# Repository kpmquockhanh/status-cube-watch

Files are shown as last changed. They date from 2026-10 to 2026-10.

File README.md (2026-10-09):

# Claude Status Cube

A desk display that shows how much of your Claude rate limits you have left.
Runs on a **Waveshare ESP32-S3-Touch-LCD-1.69** (240x280 ST7789V2, CST816
touch).

One card with both rate-limit windows — the five-hour session and the
seven-day week — as two concentric rings: outer is the session, inner is the
week. The middle holds the one thing a ring cannot show (time until the session
resets), a legend line per window sits underneath with its exact percentage and
reset time, and your unread-mail count rides in the gap of the rings next to an
envelope.

```
┌─────────────────────┐
│ 78%    BLE      4s● │
│      ╭───────╮      │
│    ╭─╯ ╭───╮ ╰─╮    │
│   │  │ 4h 09m │ │   │
│   │  │TO RESET│ │   │
│    ╰─╮╰─ ✉ 12 ─╯╭╯  │
│      ╰──   ──╯      │
│  ■ 5H  14%   4h 09m │
│  ■ 7D  53%   1d 1h  │
│        ● ○          │
└─────────────────────┘
```

Two notches are cut into each ring at 60% and 85%, where it turns amber and
then red, so the arcs read against their own thresholds with no legend of
colours anywhere on screen.

## How it fits together

```
~/.claude/projects/*.jsonl  ─┐
                             ├─→  bridge (Node)  ──HTTP──→  ESP32-S3
Anthropic Usage & Cost API  ─┘     aggregates,              draws cards
                                   formats strings
```

The device never talks to Anthropic. A host-side bridge does the aggregation
and serves one small, pre-formatted JSON document over the LAN. That keeps
credentials off the microcontroller, keeps TLS and pagination off the
microcontroller, and — most usefully — means **you redesign the dashboard by
editing `bridge/cards.mjs` and reloading, with no reflash.**

## The gauges

The whole deck is two cards, because the only numbers that change what you do
next are the two rate-limit windows.

Both come from the same place Claude Code's own status line gets them:
`GET https://api.anthropic.com/api/oauth/usage`, which returns each window's
utilization as a whole percentage plus the instant it resets. That is the
figure the server is actually enforcing, so there is nothing to estimate and no
error bar. Green under 60%, amber to 85%, red above.

Authentication reuses the Claude Code login already on this machine -- the
macOS Keychain item `Claude Code-credentials`, falling back to
`~/.claude/.credentials.json` elsewhere. The token never leaves the host; the
device only ever receives the rendered percentage. `bridge/limits.mjs` caches
the response for 60s and fails soft: a failed read keeps the last good one for
up to 10 minutes, and after that (or with no login, no network, or an endpoint
that has moved) the ring keeps its empty track and a short reason (`no login`,
`timeout`, `HTTP 401`, `offline`...) goes under the countdown. A window whose
reset time has passed shows the empty track too, until the next read. An
unfilled ring reads as a legible nothing; a missing ring reads as a bug.

The spend and token breakdowns (`TODAY`, `THIS MONTH`, `TOKENS TODAY`,
`TOP MODEL`, `TOP PROJECT`) are still built in `bridge/cards.mjs` and are one
flag away -- set `"extraCards": true` in `bridge/config.json`, or run with
`CUBE_EXTRA_CARDS=1` (with the Mac helper: **Bridge settings…**), to swipe through them as well. They are off by default,
and they have no percentage of anything to fill a ring with, so they keep the
older big-number layout (see **Adding a card**).

### Unread mail card

Set `"gmail": {"user": "you@gmail.com", "appPassword": "xxxx xxxx xxxx xxxx"}`
in `bridge/config.json` (or `CUBE_GMAIL_USER` / `CUBE_GMAIL_PASSWORD`; with the Mac helper, the
Mail fields in **Bridge settings…**) and a
number appears next to an envelope in the gap of the rings. The bridge
reads it over IMAP (`STATUS INBOX (UNSEEN)`, at most once a minute), so the
device never sees a credential. Create the app password at
<https://myaccount.google.com/apppasswords> (needs 2-step verification; some
Workspace admins disable them). If a fetch fails the last count stays on screen
shown in red; with no count yet it reads `--`. Leave the settings empty and
there is no mail badge.

## Two data sources

| Source | What it reads | Who it works for |
|---|---|---|
| `local` *(default)* | Claude Code's own transcripts in `~/.claude/projects` | Anyone. Works on a personal account, no API key, no network call. |
| `admin` | The [Usage & Cost Admin API](https://platform.claude.com/docs/en/manage-claude/usage-cost-api) | Organizations only. Needs an Admin API key or an `org:admin` OAuth token. |

**Start with `local`** unless you're on an org plan. The Admin API is
unavailable for individual accounts, and `local` covers the machine you
actually work on.

A caveat worth knowing for `local`: the transcripts record tokens, not
billing. The bridge prices them with the published per-model rates, so the
dollar figures are an *equivalent API cost*. If you're on a Claude subscription
you aren't billed per token, and the number is a usage proxy, not an invoice.
Cards show a `~` in the top bar whenever the figure is an estimate. In `admin`
mode the cost report supplies real billed dollars and the `~` disappears.

## Quick start

### 1. Bridge

```bash
cd bridge
node server.mjs
```

No dependencies to install — it's plain Node ≥20 with zero packages. It prints
the URL to put in the firmware config:

```
claude-status-cube bridge  source=local  refresh=5000ms
  preview   http://localhost:8787/
  device    http://192.168.1.50:8787/api/status
```

Open the **preview** URL in a browser: it renders the same payload as a
240x280 device mock, so you can build and tune the whole dashboard before the
hardware arrives. Click the screen or use the arrow keys to change cards.

The server answers at once and fills in the data in the background (the card
says `starting` until the first read lands). `GET /health` is always 200 while
it runs; read `ok` in the body (`ok:false` with `error` / `limitsError` when
degraded). It listens on every interface, which the cube needs to poll over
WiFi; set `"host": "127.0.0.1"` in `config.json` (or `CUBE_HOST`) to keep it off
the LAN when the cube only uses Bluetooth. Pinned to one LAN address, it also
listens on `127.0.0.1` for the Mac helper. A bad value in `config.json` or the
environment is ignored with a warning, and an environment variable wins over
the file both ways (`CUBE_EXTRA_CARDS=0` turns off `"extraCards": true`).

To keep it running without a terminal open, install it as a LaunchAgent:

```bash
./agent.sh install      # starts now, and at every login
./agent.sh status       # loaded? answering? what's on the cards?
./agent.sh logs         # tail ~/Library/Logs/claude-status-cube/bridge.log
./agent.sh restart      # after editing cards.mjs
./agent.sh uninstall
```

An *agent* rather than a *daemon* on purpose: it runs as you, inside your GUI
login session, which is what lets it read the Claude Code token from your login
Keychain. A daemon starts before login, has no Keychain, and could not
authenticate. launchd restarts it if it crashes but leaves it alone if you stop
it deliberately (`SuccessfulExit=false`), and backs off 10s between respawns so
a bad config cannot spin the CPU.

The interpreter is pinned to an absolute path — launchd does not read your
shell profile — and the script prefers `/opt/homebrew/bin/node` over an nvm
build, whose path disappears when you clean up a Node version. Override with
`CUBE_NODE=/path/to/node ./agent.sh install`.

This keeps the cube alive as long as the Mac is awake. It still goes dark when
the Mac sleeps; for a display that is genuinely independent, run the bridge on
a Raspberry Pi or another always-on box instead.

For Admin API mode:

```bash
export ANTHROPIC_ADMIN_KEY=sk-ant-admin01-...
CUBE_SOURCE=admin node server.mjs
```

(or copy `config.example.json` to `config.json` and set it there).

### 2. Firmware

```bash
cd firmware
cp src/config.h.example src/config.h   # fill in SSID, password, bridge URL
pio run -t upload && pio device monitor
```

**Check `src/board_pins.h` before the first flash.** Waveshare ships several
1.69" variants and the revisions don't all share a pinout. Every
board-specific value is in that one file; cross-check it against the pin table
on your board's product wiki.

### 3. Pairing over Bluetooth (optional, recommended)

The Mac can push the data to the cube over Bluetooth, so the cube needs no WiFi at all. With WiFi
also configured, it is the automatic fallback when the Mac is out of range or asleep.

```sh
cd mac-helper
./install.sh install      # builds the app, asks for Bluetooth permission, installs the LaunchAgent
./install.sh status|logs|restart|uninstall
```

1. Flash the cube. With no WiFi configured and no Mac paired it shows **Waiting for a Mac** until a payload arrives (a touch dismisses it).
2. `./install.sh install`, click **Allow** on the macOS Bluetooth prompt. The script pauses
   (`read`) until you press Enter, so run it from a terminal, not a script without stdin.
3. The cube shows a 6-digit code; macOS asks for it. Type it. That is the whole pairing.
4. From then on it reconnects by itself. The app also runs the Node bridge for you
   (`node server.mjs` from a copy of `bridge/` inside the app, restarted if it dies); if something
   already serves the port, such as a running `bridge/agent.sh` job, the app adopts that bridge
   instead of starting its own. Node itself is not bundled: it needs Node 20+ installed.

**`install.sh` replaces `bridge/agent.sh`.** BLE users run `mac-helper/install.sh` instead of
`bridge/agent.sh install`. If the `agent.sh` job is already installed, run
`bridge/agent.sh uninstall` first; otherwise both LaunchAgents fight for the same port.
**The bridge ships inside the app.** `build-app.sh` copies the bridge's code (not `config.json`)
to `ClaudeCubeLink.app/Contents/Resources/bridge`, so the app runs the same way from the
LaunchAgent, Finder or `open`, wherever the repo is. A change to `bridge/` reaches the app only
after `./install.sh install` again.

**Bridge settings live in the app**, not in `bridge/config.json`: menu **Bridge settings…** edits
the usage source (local logs or Admin API, with its key or OAuth token), the spend/token cards,
the refresh interval, Gmail (address + app password) and whether the bridge serves the LAN (WiFi
cubes need it; off = `127.0.0.1` only). Apply saves and restarts the bridge, which gets them as the
bridge's environment variables (`CUBE_SOURCE`, `CUBE_EXTRA_CARDS`, `CUBE_REFRESH_MS`,
`CUBE_HOST`, `ANTHROPIC_ADMIN_*`, `CUBE_GMAIL_*`), which win over any `config.json`. The secrets are one Keychain item ("Claude Cube Link
bridge settings"); the rest is in the app's defaults (`bridgeSettings`). On its first launch after
`./install.sh install` the app imports `bridge/config.json` once, if it has no settings of its own
yet. Each reinstall re-signs the app, so macOS asks once to let the new build read that Keychain
item: choose **Always Allow**. A bridge the app adopted (say, a running `agent.sh` job) keeps its own
config; the window says so.
The app reads `CUBE_PORT` (default 8787), `CUBE_BRIDGE_DIR` and `CUBE_NODE` (path to `node`) from
the environment, and takes `--port N` on its command line; `install.sh` writes the port and node
into the LaunchAgent, which restarts the app only after a crash (`KeepAlive` with
`SuccessfulExit=false`), and records the node path in the app's defaults
(`defaults read com.claude-cube.link`) for launches without the LaunchAgent. Bridge order:
`CUBE_BRIDGE_DIR` (to run the repo's bridge while working on it), a `bridgeDir` default left by an
older install (`install.sh install` removes it), the bundled copy, then a `bridge/` next to the
working directory (`swift run`). Node: `CUBE_NODE`, the recorded path, the Homebrew and system paths.
The app talks to the bridge on `127.0.0.1`; a bridge whose `host` is pinned to a LAN address
listens on `127.0.0.1` as well, so any `host` works.

**Menu bar.** The item shows the 5-hour percentage. **Cube settings…** edits what the setup portal
can; changing the WiFi network with the password left blank asks first, because the cube then joins
it as an open network and forgets the stored password. **Forget cube** drops the stored cube and
scans again, for when you replace it (also remove the old "Claude Cube" in System Settings >
Bluetooth). **Quit** also stops the bridge the app started.
For verbose diagnostics (BLE state changes, frames and ACKs, bridge health checks and child exits,
HTTP timings, push decisions) set `CUBE_TRACE=1` or pass `--trace`; lines tagged `[trace:...]`
go to stderr, i.e. `./install.sh logs`.

While a Mac is paired and data arrives over Bluetooth (a payload every 5 s) the cube turns WiFi off
(with no paired Mac, or with `WIFI_ALWAYS_ON 1`, WiFi stays on even when Bluetooth is live). If
nothing arrives for 15 s and WiFi is configured it polls the bridge instead, and goes back to
Bluetooth after it has been steady for 30 s. `WIFI_ALWAYS_ON 1` in `config.h` keeps WiFi up
(needed for OTA while Bluetooth is working). With no WiFi configured and the Mac away, the last
cards stay on screen and the freshness counter keeps counting; the setup portal does not open by
itself unless the cube has no paired Mac.

**Pairing again.** Hold the screen at boot, join the cube's `claude-cube-XXXX` network, press
**Forget paired Mac**, then also remove "Claude Cube" in System Settings > Bluetooth. If the cube's
flash was erased the Mac keeps the old bond and the log says so (`./install.sh logs`).

The protocol is in `docs/ble-protocol.md`. The manual hardware checklist (nothing in it has been run
on a real cube yet) is `docs/ble-acceptance.md`.

### Changing WiFi without reflashing (setup portal)

The cube shows a setup screen when it cannot join the stored network within ~20 s and has no paired Mac (a cube with no WiFi and no Mac shows "Waiting for a Mac" instead, see Pairing over Bluetooth), or when you touch the screen while the boot screen says "HOLD SCREEN FOR SETUP" (the first 3 s after power-up) and keep holding for 5 s. Join the open `claude-cube-XXXX` network (scan the QR on the screen); the setup page opens by itself, or browse to `192.168.71.1`. Enter the WiFi name and password, the bridge URL and, optionally, an OTA password. A WiFi password must be 8 to 63 characters (or empty for an open network). A blank password keeps the saved one unless you change the network; a blank OTA password keeps the saved one too, and **Remove the OTA password** clears it. While nobody is on the setup network the cube keeps trying the stored network (a 10 s attempt every 30 s). Once it joins, the screen also shows the cube's address on that network, where the same page works from any computer on your LAN. If the setup screen came up because WiFi was down (not because you held the screen), the cube goes back to normal by itself the moment the stored network answers, so a router that was slow to come back after a power cut does not strand it. The setup network is open by design: while it is up (setup screen showing), anyone in radio range, and once it has joined, anyone on your LAN, can change the cube's settings, including the OTA password. (The page refuses requests that do not name the cube by address or that do not come from the form it served, so another web page cannot submit it for you.) Only reconfigure when you are at the cube, and set an OTA password. The page also has a **Forget paired Mac** button.

### Updating over WiFi (OTA)

After the first USB flash the cube is reachable as `claude-cube.local`. In `firmware/platformio.ini` uncomment `upload_protocol = espota`, `upload_port = claude-cube.local` and (if you set an OTA password) `upload_flags = --auth=...`, then run `pio run -t upload` as usual. The screen shows a progress bar. OTA runs under WiFi modem sleep (Bluetooth is always on, and the ESP32 does not allow WiFi power-save off alongside it), so an upload may occasionally time out: just retry. Without an OTA password anyone on your network can flash the cube; set one in the portal.

### Volume card

While a Mac is paired, the deck has a Volume card just before the Pomodoro: the output's name and its volume as a large number on the left, a slim bar on the right that fills from the bottom. **Drag** up or down anywhere on the card to raise or lower the volume by how far your finger moves; touching or tapping never changes it. **Tap the number** to mute or unmute (any volume change also unmutes). The row of buttons at the bottom is **previous**, **play/pause** and **next**: they act on whichever app is playing (as Control Center's buttons do; no permission needed), and the middle button shows ▶ while paused and ❙❙ while playing. Left and right swipes still change card; swipe down does not open the display panel on this card. Changes made on the Mac (keyboard, menu bar, switching to AirPods) show on the cube within about a third of a second. An output whose volume the Mac cannot set (HDMI, some USB devices) shows `FIXED`, and only mute works there; with the Mac's app not connected the card shows `NO MAC`. It needs the Mac app and firmware from the same release: an older app leaves the card on `NO MAC`, and an older cube has no Volume card. After a firmware update the cube tells the paired Mac its services changed (Service Changed, sent once per new firmware revision), and the Mac app rediscovers them on the next connection. If the card still stays on `NO MAC` while the top bar says `BLE`, remove the cube in System Settings > Bluetooth and pair again (macOS kept the old services).

### Unlocking the Mac from the cube

Turn on **Unlock Mac with cube…** in the menu. It asks for your login password once, checks it, and keeps it in the Mac's Keychain; macOS also asks you to allow Claude Cube Link under Privacy & Security > Accessibility, which it needs to type. From then on, when the Mac locks, the cube shows **Tap to unlock**. Tap it, and the Mac wakes the display and types the password into the lock screen. The cube only asks; the password never leaves the Mac. A swipe puts the prompt away to show the cards, and it comes back after 30 s without a touch. A running Pomodoro shows its clock under the prompt.

It works on a locked session only. After a restart, the FileVault login comes before the app runs, so type the password there as usual. Anyone holding your paired cube can unlock the Mac while it is in Bluetooth range, so leave this off if the cube sits where others can reach it. `build-app.sh` signs with your Apple Development certificate when the keychain has one (a free Apple ID in Xcode > Settings > Accounts creates it), so macOS keeps the Accessibility permission and Keychain access across rebuilds. Without one the app is signed ad-hoc, and macOS forgets both after every rebuild; until you allow them again, the log says why a tap did nothing. Turning the item off deletes the stored password.

### Pomodoro card

The last card in the deck is a Pomodoro timer that runs on the cube itself (so it works with the bridge down). **Double-tap** the screen to start, pause or resume (it acts a third of a second after the second tap, once it is clear no third is coming); **triple-tap** to reset. It runs 25 min focus, 5 min break, and a 15 min break after four focus sessions, each phase started by you. When a phase ends the cube jumps to this card and pulses the ring and backlight for about two seconds and plays a short tune (rising for a break, ending high for back to work); the next phase waits for your double tap. To change the lengths without reflashing, **swipe up** on the Pomodoro card while the timer is idle. A settings screen opens with a `-` and `+` for FOCUS (steps of 5 min), SHORT BREAK (1 min), LONG BREAK (5 min) and SESSIONS (1). RESET returns to the defaults; DONE (or a swipe down) saves them, and they survive power cycles. A running or paused phase is never resized: new lengths apply from the next one you start. Lengths changed from the Mac (**Cube settings…**) work the same way, and arrive even mid-set. The defaults are `POMO_FOCUS_MIN`, `POMO_BREAK_MIN`, `POMO_LONG_MIN` and `POMO_SESSIONS` in `config.h`.

### Sound

The cube's buzzer plays a short tune when a Pomodoro phase ends. Its level is OFF, LOW, MED (the default) or HIGH, and you can set it in three places:
- **On the cube:** swipe down on any card and use the SOUND row. A tap on its label switches it off or back on, and each change plays a beep at the new level.
- **From the Mac:** **Cube settings…** > Sound.
- **In the setup portal:** Sound, from 0 to 3.

The default is `BUZZER_LEVEL` in `config.h`. SOUND took the place of WiFi refresh in the on-device panel. WiFi refresh is still in the portal and on the Mac.

## Layout

```
bridge/
  server.mjs          HTTP server + refresh loop
  cards.mjs           events → the card deck (edit this to redesign)
  pricing.mjs         per-model rates and cache multipliers
  limits.mjs          rate-limit windows from the OAuth usage endpoint
  agent.sh            install/remove the macOS LaunchAgent
  preview.html        browser mock of the device
  sources/local.mjs   incremental ~/.claude transcript reader
  sources/admin.mjs   Usage & Cost Admin API client
mac-helper/           Swift app: runs the bridge, pushes /api/status to the cube over BLE
  install.sh          install/remove the LaunchAgent
firmware/
  src/board_pins.h    all board-specific pins — check this first
  src/config.h        your WiFi + bridge URL (gitignored)
  src/display.h       LovyanGFX panel definition
  src/touch.cpp       CST816 driver
  src/ui.cpp          card rendering
  src/payload.cpp     bridge JSON → Payload (shared with the simulator)
  src/net.cpp         WiFi transport
  src/net_ble.cpp     BLE transport (NimBLE GATT server)
  src/ble_frame.h     chunk reassembly for the BLE wire format
  src/transport_policy.h  when WiFi runs versus BLE (pure, host-tested)
  src/main.cpp        poll loop and swipe handling
  sim/                desktop simulator — runs the UI without hardware
  sim/shot.cpp        headless frame grab: one PNG per card
```

## Testing without the board

Two ways, in increasing fidelity.

**Browser mock.** Start the bridge and open its address. `preview.html` renders
the same 240×280 layout and polls the same endpoint the device will. Good for
iterating on `cards.mjs` — edit, reload, see it. It is a JavaScript
reimplementation of the layout, so it tells you whether the *data* reads well,
not whether the firmware draws it correctly.

**Battery indicator.** Every card's top bar shows the battery level, measured on the board's ADC and drawn on-device (it is not part of the bridge payload). With no battery connected the cube is running from USB and shows a full 100%. In the simulator, `CUBE_BATTERY=30 make run` (or `none` for the no-battery case) picks the level.

**Desktop simulator.** `firmware/sim/` compiles the actual firmware sources —
`main.cpp`, `ui.cpp`, `payload.cpp` — against LovyanGFX's SDL backend and opens
a window instead of driving the ST7789. Only the two layers that touch hardware
are swapped: `net_sim.cpp` does a socket HTTP GET in place of WiFi, and
`touch_sim.cpp` feeds mouse events in place of the CST816 over I²C. The gesture
thresholds, the font-fitting ladder, the sprite compositing and the JSON parsing
are the real ones.

```sh
brew install sdl2
cd firmware && pio run          # once, to fetch LovyanGFX + ArduinoJson
cd sim && make run
```

Drag across the window to swipe, click to tap, `SCALE=3 make run` for a bigger
window, and `CUBE_BRIDGE_URL=http://localhost:8787/api/status make run` to point
it somewhere other than the `BRIDGE_URL` in `config.h`.

**Bluetooth in the simulator.** There is no BLE radio on the desktop, so `CUBE_BLE` picks what the
cube believes: `none` (default, WiFi-only as before), `live` (bonded, a payload arrives every 5 s),
`stale` (bonded, nothing arrives, so WiFi takes over after 15 s), `pair` (the passkey screen).
`./build/cube-shot build/shot @ble-pair` and `@ble-wait` render the passkey and "Waiting for a Mac"
screens.

**Frame grabs.** `make shot` renders every card of the live payload through the
same `ui.cpp` and writes one PNG per card to `build/`, with no window and no
screen-recording permission involved. It waits for the entry animation to
settle first, so what you get is the resting layout. Point it at a saved
payload to shoot states you cannot reach on demand -- the red ring, the
empty track, a card that does not exist yet:

```sh
cd firmware/sim
make shot                                  # the live bridge
./build/cube-shot build/state states.json  # build/state-0.png, -1.png, ...
```

What it still cannot tell you: whether the pins in `board_pins.h` match your
revision, how the ST7789 renders these colours, and how the panel behaves at its
real refresh rate.

## Adding a card

Push one more object onto the `cards` array in `bridge/cards.mjs`. Without a
`g`, you get the big-number layout:

```js
{ t: 'WEB SEARCHES', v: String(dayT.webSearch), s1: 'today', s2: '', c: 'blue' }
```

With a `g` — a whole percentage — you get a ring instead, and the other fields
change jobs: `g` fills the arc, `v` goes in the middle of it, `s1` captions
`v`, and `s2` labels the percentage in the gap at the bottom:

```js
{ t: 'CONTEXT', v: '38k', s1: 'tokens left', s2: 'of 200k', c: 'green', g: 81 }
```

`g: -1` means *no reading* and draws the empty track. The threshold colours
are yours to pick through `c`; the notches at 60% and 85% are fixed, so a ring
whose meaning does not break there wants a different accent than green/amber/
red so it doesn't imply one.

Reload the page. The firmware sizes the deck from the payload and the page
dots follow — nothing to change on the device. Accent names are `accent`,
`blue`, `green`, `amber`, `violet`, `red`.

Keep `v` short. A text card shrinks its own value to fit 220px. Ring cards
instead pick one size for the whole deck — the largest that fits the longest
value inside the ring's 130px middle — so the countdown does not change size
as you swipe. One long value therefore shrinks every ring, which is why
`until()` drops minutes once the horizon passes ten hours.

## Notes on the implementation

- **Incremental reads.** The local source reads every `.jsonl` under
  `~/.claude/projects` (subagent transcripts included), keeps a byte offset per
  file and only parses appended bytes, moving the offset only past complete
  lines, so a half-written line is read again next time. A file whose size and
  modified time have not changed is skipped, so a 5-second refresh over a busy
  `~/.claude` stays cheap. Events are de-duplicated on `requestId`, because
  the same request is often written to the log more than once.
- **Pricing.** `bridge/pricing.mjs` matches model ids on the longest prefix,
  prices cache reads and writes per model, and prices fast mode and US-only
  inference (`inference_geo: "us"`, 1.1x) when the usage record says so.
- **Admin polling.** The Usage & Cost API documents sustained polling at once
  per minute; the bridge enforces that floor in `admin` mode regardless of
  what you configure.
- **Cost vs. usage endpoints.** In `admin` mode the usage report gives hourly
  granularity per model and the cost report gives authoritative dollars in
  daily buckets (UTC days, shown under the local date). Both only matter with
  `extraCards` on; the default gauges come from the OAuth usage endpoint instead.
- **No LVGL.** Two dials don't need a widget toolkit. LovyanGFX with one
  full-screen sprite is simpler to build, has no `lv_conf.h` to maintain, and
  leaves most of RAM free. LVGL 9 is the upgrade path if the UI grows.
- **Motion.** A ring sweeps up from zero the first time you see a card after
  boot (700ms), retargets from wherever it currently is when the number moves
  under it (260ms), and crossfades through a threshold colour over 400ms.
  Everything eases out. It is deliberately per-card and once-per-boot: an
  animation replayed on every swipe is one you would see dozens of times a
  day, and there is no pulse or blink on the red state for the same reason.
  `uiAnimating()` is what tells `main.cpp` to keep drawing frames; the rest of
  the time the loop still redraws once a second for the freshness counter.

## Troubleshooting

| Symptom | Cause |
|---|---|
| White or blank screen | Pins in `board_pins.h` don't match your revision |
| Image shifted vertically | Change `LCD_OFFSET_Y` (20 ↔ 0) |
| Colours inverted | Flip `cfg.invert` in `src/display.h` |
| `[touch] not responding` | `PIN_I2C_SDA` / `PIN_I2C_SCL` / `PIN_TP_RST` wrong |
| Top bar shows `OFF` | Bridge not reachable — check it's bound to the LAN address it printed, and that the host firewall allows the port |
| Costs look too low | An unrecognised model falls back to Sonnet-tier rates; add it to `bridge/pricing.mjs` |
| Cube never pairs | Check `./install.sh logs`; the app needs the Bluetooth permission (System Settings > Privacy & Security > Bluetooth) |
| `pio run` stalls at `Downloading 0%` | PlatformIO's CDN, not your network. See below. |

### When the PlatformIO registry is down

`dl.registry.platformio.org` occasionally serves at a crawl, which strands
`pio run` on `Downloading 0%` with an empty `~/.platformio/packages/`. Confirm
it's the CDN and not you by timing the same toolchain from GitHub:

```sh
curl -o /dev/null -w '%{speed_download} B/s\n' -r 0-8000000 \
  https://github.com/espressif/crosstool-NG/releases/download/esp-2021r2-patch5/xtensa-esp32s3-elf-gcc8_4_0-esp-2021r2-patch5-macos-arm64.tar.gz
```

If GitHub is fast, install the packages by hand into `~/.platformio/packages/`
from their upstream releases — the two xtensa toolchains and the RISC-V one
from [crosstool-NG](https://github.com/espressif/crosstool-NG/releases/tag/esp-2021r2-patch5),
the framework from [arduino-esp32 2.0.17](https://github.com/espressif/arduino-esp32/releases/tag/2.0.17),
and [esptool 4.11.0](https://github.com/espressif/esptool/releases/tag/v4.11.0).
Each directory needs a `package.json` (`name` and `version` matching what
`~/.platformio/platforms/espressif32/platform.json` asks for) and a `.piopm`
naming the owner — the registry adds both during packaging, so the raw
archives lack them. esptool from source also needs `pip install intelhex`
in the PlatformIO Python environment.

## Ideas from here

The board also has a QMI8658 IMU, a PCF85063 RTC, a buzzer, and battery
charging, none of which this scaffold uses yet:

- Wrist-raise or tilt to wake, via the IMU
- Buzzer when the daily spend crosses a threshold
- Deep sleep between polls, with the RTC as the wake source, for battery use
- A "burn rate" card: tokens per minute over the last 10 minutes

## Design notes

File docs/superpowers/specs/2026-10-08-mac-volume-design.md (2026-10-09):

# Mac volume card

## Goal

A card on the cube that shows and changes the Mac's output volume: a full-width vertical slider in
the style of the Android "flex" volume control. Drag it, tap to jump, tap the speaker to mute. The
cube follows the Mac too, so a change made with the keyboard shows up on the cube.

## Decisions (agreed)

- A **deck card**, not a panel. Deck order: payload cards, **Volume**, Pomodoro (still last). The
  card exists while a Mac is bonded (`bleBonded()`); with no bond the deck is unchanged.
- Controls: **volume and mute** only. No media keys.
- Transport: **BLE only**, approach A: a new Control message (cube -> Mac) carries the request, and a
  new **Volume** characteristic (Mac -> cube) carries the Mac's state, including the **output device
  name**. The payload contract, the bridge and `preview.html` are untouched.
- Look: one rounded pill across the card, filling from the bottom (reference: Android flex volume
  UI, made full width).
- On this card a vertical drag is the volume, so **swipe down does not open the display panel
  here**. It still opens from every other card.
- No new menu item on the Mac.

## The card

```
  BLE   78%            4s .
 +------------------------+
 |  MACBOOK PRO SPEAKERS  |   output name, small caps
 |          56            |   level
 |########################|   fill edge = level (flat)
 |########################|
 |#########  spk  ########|   speaker glyph
 +------------------------+
           . . o .
```

Layout (240x280 panel; exact numbers are tuned against `make shot`):

- The top bar is the shared one (battery, link marker, age), and the page dots sit below as usual.
- The pill runs x 14..226 and y 42..252, with corners of about 40 px. Its track is dark (the ring
  track colour family).
- The fill is the same anti-aliased rounded rect, clipped to `y >= levelY`, so the corners stay
  smooth at any level and the top edge is flat. The fill colour is a soft lavender (a new accent
  constant).
- The output name is drawn in small caps near the top of the pill, and the level number large below
  it. Both are drawn twice through the fill clip: ink above the fill edge, dark where the fill
  covers them, so the text stays readable at any level.
- The speaker glyph is centred near the bottom of the pill with 0..3 waves by level (0, 1..33,
  34..66, 67..100). When muted it is slashed and drawn with no waves.
- No glow or texture: the panel is RGB565 and the frame budget is better spent elsewhere.

States:

| State | Fill | Number | Caption / name | Touch |
|---|---|---|---|---|
| Live | lavender, at level | level | output name | drag, tap-jump, speaker = mute |
| Muted | crossfades to grey (`POMO_MUTED`), keeps its height | level | output name, glyph slashed, the word `MUTED` under the number | as live; any level change also unmutes |
| Fixed volume (`canSet` false) | full, dimmed grey | `--` | output name, `FIXED` under the number | speaker = mute if `canMute`, else nothing |
| No Mac (link down, or no Volume write yet) | empty track | `--` | `MAC VOLUME`, `NO MAC` under the number | nothing |

The state never relies on colour alone: `MUTED`, `FIXED` and `NO MAC` are spelled out.

Motion:

- A change from the Mac, or a tap-jump, eases the fill to the new level with the existing retarget
  timing (`RETARGET_MS`, 260 ms, ease-out).
- While a finger drags, the fill tracks the finger directly, with no easing.
- Mute and unmute crossfade the fill colour over `COLOR_MS` (400 ms).
- The first view of the card sweeps the fill in from empty, as rings do (`uiReplay`).

Interaction:

- Drag up or down anywhere on the pill: the level is the finger's height mapped linearly over the
  pill's inner height, clamped to 0..100.
- Tap on the pill, outside the speaker zone: the level jumps to that height.
- Tap in the speaker zone (about 60x50 px around the glyph): toggle mute.
- Swipe left or right: change card. Axis lock decides between the two: once the finger has moved
  10 px from where it landed, a mostly vertical move becomes a drag and a mostly horizontal one
  stays a swipe. A drag never turns into a swipe and vice versa.
- Swipe up and swipe down mean nothing on this card.
- Taps here are plain taps (multi-tap is off), delivered at once.
- Touch is ignored in the No Mac state. In the Fixed state only the speaker zone acts.

Other behaviour:

- Local-only, like the Pomodoro card: not in the payload contract, not counted against
  `MAX_CARDS`, not in `preview.html`.
- Volume writes from the Mac are not readings. They do not change `readingsKey()`, so they do not
  keep the screen awake or wake it.
- Auto-advance includes the card like any other. A touch on it restarts the auto-advance timer, as
  a swipe does.
- When the deck changes size, a viewer on the Volume card stays on it (`deck_util.h`), as a viewer
  on the Pomodoro card does.

## Protocol

Additive; protocol version stays 1. `fw_rev` goes 4 -> 5.

### Control (cube -> Mac)

| Bytes | Meaning |
|---|---|
| `05 <level> <muted>` | set the Mac's output to `<level>` (0..100) and mute `<muted>` (0/1). |

- The request is an absolute target, so a lost or repeated message cannot drift the volume.
- Fire and forget: no ack, and it is dropped when no Mac is subscribed.
- A Mac that does not know `05` ignores it.

### Volume characteristic (Mac -> cube)

UUID `6e6d3c10-5d1a-4c1e-9f0b-7c4a2b8e1a06`, write (encrypted + authenticated), at most 26 bytes:

```
[ver=1][level][flags][name...]
```

- `level`: 0..100, or `FF` when there is no output device.
- `flags`: bit0 muted, bit1 volume settable, bit2 mute settable. Other bits are 0, and the cube
  ignores them.
- `name`: the output device name, printable ASCII (0x20..0x7E), 0..23 bytes, no terminator.

Validation:

- The cube drops the whole write when the value is shorter than 3 bytes, `ver != 1`, `level` is
  over 100 and not `FF`, or the name holds a byte outside 0x20..0x7E.
- A dropped write keeps the previous state.

When the Mac writes:

- once after it has subscribed to Control;
- then on every coalesced CoreAudio change (volume, mute, name, default output device).

Lifetime:

- The cube forgets the state when the link drops, and the card falls back to No Mac.
- A cube without the characteristic (fw_rev < 5) gets no writes, and the Mac logs it once.

Both encodings get golden lines in `firmware/sim/fixtures/ble-frames.txt`, read by `make test` and
`swift test`. Documented in `docs/ble-protocol.md`.

Latency note: the idle connection parameters let the cube skip up to 6 connection events, so a
Mac -> cube write can take about 300 ms to land. Drags go cube -> Mac and the fill follows the
finger locally, so this only delays how fast a *keyboard* change shows on the cube.

## Firmware

New pure units, each with a host test in `sim/tests/` (no Arduino, caller passes `now`, gnu++11
safe):

- **`volume_frame.h`**
  - `MacVolume { bool known; uint8_t level; bool muted, canSet, canMute; char name[24]; }`.
  - `bool volumeParse(const uint8_t *d, size_t n, MacVolume &out)` applies the validation above.
  - `void volumeRequestEncode(uint8_t level, bool muted, uint8_t out[3])`.
- **`volume_slider.h`**
  - The geometry: pill rect, inner travel, speaker zone. `ui.cpp` draws from the same constants,
    so drawing and hit-testing cannot drift (the `pomo_editor` pattern).
  - `uint8_t volumeLevelAt(int16_t y)`.
  - A `VolumeSlider` model:
    - holds the shown level and muted flag;
    - `grab(now)` / `drag(y, now)` / `release(now)` / `tap(x, y, now)`;
    - `fromMac(const MacVolume&, now)`, which is ignored while held and for `VOLUME_HOLD_MS`
      (600 ms) after release, so echoes of older levels cannot jerk the fill;
    - `bool takeSend(now, level&, muted&)`, which yields a request at most every `VOLUME_SEND_MS`
      (50 ms) while dragging, always the final value on release, and once per tap.

Changed units:

- **`gesture.h/.cpp`**: a `dragMode` flag next to `multiTap`, set by `main.cpp` only on the Volume
  card.
  - New gestures `DragStart`, `Drag`, `DragEnd`. `Drag` comes back while the finger moves, with
    `lastY()`.
  - Once travel reaches `DRAG_LOCK_PX` (10), a mostly vertical move locks to a drag and a mostly
    horizontal one is classified on lift as today.
  - Taps are unchanged. With `dragMode` off, behaviour is identical to today (the existing tests
    must still pass).
- **`ble.h`, `net_ble.cpp`**
  - The Volume characteristic; its callback copies the value out under the same pattern as
    Settings.
  - `bool bleTakeVolume(MacVolume &out)` returns true when the state changed, including the change
    to "unknown" when the link drops.
  - `void bleSendVolume(uint8_t level, bool muted)` notifies Control `05`.
  - `BLE_FW_REV` becomes 5.
  - Stand-ins in `sim/ble_sim.cpp` (driven by `CUBE_VOLUME=56|muted|fixed|none`, default `none`)
    and `sim/bench.cpp`.
- **`ui.h/.cpp`**
  - `uiVolumeIndex(p)`. `uiDeckSize` / `uiPomodoroIndex` account for the card when it is present,
    and `uiRender` takes whether it is present.
  - `drawVolumeCard(...)` draws the pill, the clipped fill, the two-tone text and the glyph.
  - A `GaugeAnim`-style animation holds the fill level and colour.
  - `uiReplay` covers the card.
- **`deck_util.h`**: `deckKeepIndex` keeps a viewer on either local card.
- **`main.cpp`**
  - calls `bleTakeVolume` every pass and feeds the slider;
  - on the Volume card passes `dragMode`, routes `DragStart` / `Drag` / `DragEnd` / `Tap` to the
    slider and skips `SwipeDown`;
  - calls `bleSendVolume` from `takeSend`;
  - sets `dirty` on any slider change;
  - treats a drag as animating, so the CPU stays at 240 MHz and frames are paced to `FRAME_MS`.
- **`sim/shot.cpp`**: `@vol-56`, `@vol-muted`, `@vol-fixed`, `@vol-none`, `@vol-full`,
  `@vol-zero`.
- **`sim/bench.cpp`**: a `volume` scenario (one drag across the pill, then a tap on the speaker).

## Mac helper

- **`CubeLinkCore/Volume.swift`** (pure, tested)
  - `MacVolume`.
  - `encodeVolume(_ v: MacVolume) -> Data`. The name is folded to ASCII: diacritics stripped,
    other non-ASCII dropped, cut to 23 bytes.
  - `ControlMessage.volumeRequest(level:muted:)` in `Protocol.swift`. A frame under 3 bytes, a
    level over 100 or a muted byte over 1 parses to nil.
  - `CubeProtocol.volumeUUID`.
- **`ClaudeCubeLink/SystemVolume.swift`** (CoreAudio; no permission prompt needed)
  - Reads the default output device, `kAudioHardwareServiceDeviceProperty_VirtualMainVolume`,
    `kAudioDevicePropertyMute`, `kAudioObjectPropertyName`, and whether each is settable. With no
    output device, `level` is `FF`.
  - Listens with `AudioObjectAddPropertyListenerBlock` to the system default-output change and to
    volume, mute and name on the current device. The device listeners move when the default
    output changes.
  - Coalesces callbacks into one `onChange(MacVolume)` about 30 ms after the last.
  - `apply(level:muted:)` sets mute, then the volume scalar (level / 100). A request with
    `muted = 0` unmutes. A part the device cannot set is skipped.
- **`CubeLink`**
  - Discovers the Volume characteristic optionally (like Settings).
  - `writeVolume(Data)` writes it with response.
  - The Control handler calls `onVolumeRequest(level, muted)`.
  - Once subscribed, the link asks for the current state so it is written at once.
- **Wiring (`main.swift` / `StatusMenu.swift`)**: `SystemVolume.onChange` -> `CubeLink.writeVolume`
  (only while ready), and `CubeLink.onVolumeRequest` -> `SystemVolume.apply`. Changes are logged
  through `Trace`.

## Testing

- `make test`:
  - `volume_frame_test`: parse and encode, every rejection case, the fixture lines.
  - `volume_slider_test`: `levelAt` at the travel ends and past them, tap-jump, the speaker zone,
    the hold window ignoring and then accepting Mac state, the send throttle and the final send,
    unmute-on-change.
  - `gesture_test`: axis lock both ways, the drag event sequence, taps in drag mode, `dragMode`
    off unchanged.
  - `deck_util` cases for two local cards.
- `swift test`: fixture parity for both encodings, `05` parsing including malformed frames, name
  folding and truncation.
- `make shot` / `cube-shot @vol-*`: each state looked at before the UI is called done.
- `make bench`: the `volume` scenario stays within frame pacing, and the screen still sleeps at
  the end of `linked` / `sleep`.
- `pio run`: the board build (gnu++11) after the pure headers are added.
- Hardware: a "Volume card" section in `docs/ble-acceptance.md` covering drag, tap-jump, mute,
  keyboard echo, switching output to AirPods, an HDMI or fixed output, link drop, and an older Mac
  app.

## Out of scope

- Media keys (play/pause, next).
- Per-app volume.
- Input (microphone) volume.
- A Mac-side toggle for the feature.
- WiFi delivery.
- Haptic or sound feedback on the cube.
- Hold-to-repeat.
- A volume HUD on the Mac.

## Docs to update on implementation

- `CLAUDE.md`: the deck description and the Transports paragraph.
- `firmware/CLAUDE.md`: the pure-header list.
- `docs/ble-protocol.md`: Control `05` and the Volume characteristic.
- `docs/ble-acceptance.md`: the new section.
- `mac-helper/CLAUDE.md`.
- `README.md`: where it describes the cards and the Mac app.

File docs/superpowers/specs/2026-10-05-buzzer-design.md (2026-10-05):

# Buzzer

## Goal
Give the cube a voice. Make the on-board passive buzzer play a short tune when a Pomodoro phase ends, with an on/off switch and three volume levels you can set on the cube, from the Mac and in the portal. Also hold the buzzer pin low from the first instant of boot. Today the firmware never touches it, and Waveshare's FAQ for this board warns that an undriven buzzer pin keeps drawing current through the 3.3 V LDO and heats it.

This is sub-project A of six (A buzzer, B Claude session status, C answer from the cube, D IMU gestures, E next meeting, F now playing). B will use the `Attention` sound defined here when Claude Code is waiting for you, so that sound is in the tables now even though nothing in A triggers it.

## Non-goals
- Sounds triggered by the bridge: no payload field and no contract change. B adds the payload event that plays `Attention`.
- Usage-threshold beeps and a limit-reset chime. These were offered and not wanted.
- Quiet hours. The cube has no local time of day yet (the RTC is unused), so there is nothing to compare against.
- A touch-click sound, or sound for swipes and taps.
- Mirroring in `preview.html` or the Mac's menu bar. Sound is local, like the battery and the Pomodoro card.
- Real audio in the simulator. It logs which sound would play.

## Hardware facts
- The buzzer is **passive**: a PWM square wave sets its pitch, and the duty cycle sets its loudness (non-linearly; 50% is loudest).
- Current boards wire it to **GPIO42** (`docs/ESP32-S3-Touch-LCD-1.69.md`). Waveshare's FAQ says an older revision used GPIO33.
- The Arduino core is 2.0.17 (`framework-arduinoespressif32` 4.20017.0), so the LEDC API is `ledcSetup` / `ledcAttachPin` / `ledcWrite` / `ledcChangeFrequency`. On the S3, channel *n* runs on timer `(n / 2) % 4`.
- The backlight is LovyanGFX `Light_PWM` on LEDC **channel 7** (timer 3) at 12 kHz (`display.h`). The buzzer must use a channel on another timer, so that changing the buzzer's frequency can never retime the backlight. Channel 6 would share timer 3, so it is ruled out.
- Arduino's `tone()` is not used. It claims LEDC channel 0 and spawns its own FreeRTOS task.

## Design

### Pin: `board_pins.h`
`#define PIN_BUZZER 42`, with a comment that older board revisions use 33.

### Sequencer: `firmware/src/melody.h` (pure, header-only, host-tested)
- `struct Note { uint16_t hz; uint16_t ms; }`, where `hz == 0` is a rest.
- `enum class Sound : uint8_t { FocusDone, BreakDone, Attention, Preview }` and `const Note *melodyFor(Sound, uint8_t &len)`. Each melody is a `constexpr` table and lasts under 0.5 s.

| Sound | Played when | Shape (starting pitches; tuned by ear on the board) |
|---|---|---|
| `FocusDone` | a focus phase ends: break time | three rising notes, ~2.1 / 2.6 / 3.1 kHz, ~110 ms each |
| `BreakDone` | a short or long break ends: back to work | three notes ending high and held longer, distinct from `FocusDone` |
| `Attention` | (B) Claude Code is waiting for you | two ~70 ms beeps near the buzzer's loudest pitch (~2.7 kHz), 70 ms apart |
| `Preview` | the SOUND level changes in the on-device panel | one ~90 ms beep |

- `class MelodyPlayer`:
  - `play(Sound)` replaces whatever is playing. Timing starts at the next `update()`, so a play requested after this pass read `now` (the panel's preview, from the touch handler) keeps its first note.
  - `stop()`.
  - `uint16_t update(now)` returns the pitch to output now, or 0 for silence (a rest, or finished). A late call skips the notes it missed, so a tune keeps its length.
  - `bool playing() const`.
- Elapsed time uses unsigned subtraction, so a `millis()` wrap mid-melody is harmless. The caller passes `now`, as with every pure header.
- C++11-safe for the board build: every `constexpr` function is a single `return`.

### Driver: `firmware/src/buzzer.{h,cpp}` (hardware layer)
API:
```cpp
bool buzzerBegin();                 // first thing in setup(); false = LEDC setup failed
void buzzerSetLevel(uint8_t level); // 0 = off, 1..3 = LOW / MED / HIGH
void buzzerPlay(Sound s);           // no-op at level 0
void buzzerUpdate(uint32_t now);    // every loop pass
```
- `buzzerBegin()`:
  1. `pinMode(PIN_BUZZER, OUTPUT); digitalWrite(PIN_BUZZER, LOW)` before anything else in `setup()`, so the pin no longer floats from boot.
  2. Then `ledcSetup(BUZZ_CH = 0, 2000, 10)` (10-bit duty), `ledcAttachPin`, and `ledcWrite(BUZZ_CH, 0)`. Channel 0 runs on timer 0, away from the backlight's timer 3.
- Silence is always duty 0, which keeps the output low.
- `buzzerUpdate` asks the `MelodyPlayer` for the current pitch and only touches LEDC when the pitch changes: `ledcChangeFrequency` followed by `ledcWrite(duty)`, or duty 0 for a rest or the end.
- Notes are timed by the main loop pass (15 ms, or `FRAME_MS` = 16 ms while animating), so durations are accurate to about one pass. Every note is ≥ 60 ms, so that is inaudible. Screen-off passes are 50 ms, but nothing in A plays with the screen off: a running Pomodoro keeps it on, and the panel is on screen.
- Volume is a duty per level: `{0, LOW ≈ 2%, MED ≈ 10%, HIGH = 50%}` of the 10-bit range. These are constants in `buzzer.cpp`, tuned by ear on the board, because a passive transducer's loudness is not linear in duty.
- A level change applies on the next loop pass. Level 0 also stops the tune, so it is silent at once.
- `ledcSetup` returning 0 makes `buzzerBegin()` return false. `setup()` logs `[buzz] ledc setup failed` once Serial is up, and the cube stays silent. The pin is still held LOW by step 1.
- Serial log: `[buzz] <sound> @<LOW|MED|HIGH>` on each play.

Simulator and bench:
- `firmware/sim/buzzer_sim.cpp` implements the same header. It only prints the `[buzz]` line: no player and no audio.
- `sim/bench.cpp` includes `../src/buzzer.h` and defines no-op stand-ins, as it already does for the battery and the IMU.
- `buzzer_sim.cpp` goes in `SRCS`. `melody.h` is header-only, so `melody_test` only needs adding to `TESTS`.

### Setting: `DeviceSettings.sound`
- New field `uint8_t sound; // 0 = off, 1..3 = LOW / MED / HIGH`. It is clamped to 0..3 in `deviceClamp` and compared in `operator==`.
- Default: `BUZZER_LEVEL` from `config.h` (MED = 2), with an `#ifndef` fallback in `device_defaults.h` so an older `config.h` still builds. `config.h.example` documents it.
- NVS key `sd` (`settings.cpp`), falling back to the default when never stored. `sim/settings_sim.cpp` has no NVS and copies `DEVICE_DEFAULTS` whole, so it needs no change.
- Every brace-initialised `DeviceSettings{...}` gains the fifth value: `DEVICE_DEFAULTS`, `portal.cpp`'s save (`DeviceSettings{bl, sl, rt, pi}` today), and the tests. A missed one compiles fine and silently stores sound = 0.
- `buzzerSetLevel` is called:
  - in `setup()`, with `deviceSettings().sound`;
  - in `closeDeviceEditor()`, next to the brightness restore;
  - in `handleBleSettings()`, next to its `setBrightness`.

  The portal saves and reboots, so `setup()` covers it.

Everywhere it can be edited:
- **On-device panel** (`dev_editor.cpp`): row 3 becomes **SOUND** in place of REFRESH. It is a switch row, like SLEEP and ADVANCE.
  - Presets are `{1, 2, 3}`, shown as `LOW` / `MED` / `HIGH`, or `OFF`.
  - A tap on the lead toggles it. Turning it back on restores the saved level, else the default, else MED.
  - The steppers move between presets and do nothing while it is off.
  - Each change plays `Preview` at the new level, as brightness previews live. Turning it off is silent.
  - This lives in `main.cpp`, beside the existing live `lcd.setBrightness(editDevice.backlight)` after `devEditorApply`. When `editDevice.sound` changed, it calls `buzzerSetLevel(editDevice.sound)`, and then `buzzerPlay(Sound::Preview)` if the new level is non-zero. `dev_editor.cpp` stays pure.
  - Closing the panel always saves, so there is no cancel path that would need to revert the level.
  - REFRESH leaves the cube's panel but stays editable in the portal and the Mac window.
- **BLE Settings JSON** (`settings_json.cpp`, `docs/ble-protocol.md`): key `sd`, an integer from 0 to 3. As for every key, a missing `sd` leaves the level unchanged, so an older Mac helper keeps working. `BLE_FW_REV` goes from 3 to 4.
- **Mac helper** (`CubeSettings.swift`, `SettingsWindow.swift`): a `sound` field and a **Sound** popup (Off / Low / Medium / High). The popup is shown only when the cube's settings read contains `sd`, so an older cube never shows a control it would ignore. The write sends `sd` only when it changed (the existing diff rule).
- **Portal** (`portal.cpp`): a numeric field "Sound" (hint "0 = off, 1 = low, 2 = medium, 3 = high"), key `sd`, using the existing `numField` / `portalParseInt` pattern. A blank field keeps the current value.

### Pomodoro hookup: `main.cpp`
In the existing `pomo.takeAlert()` block, next to `bleNotifyPomodoro` and `uiAlertStart`:
```cpp
buzzerPlay(ended.phase == PHASE_FOCUS ? Sound::FocusDone : Sound::BreakDone);
```
`buzzerUpdate(now)` runs on every loop pass, right after the Pomodoro tick. The screen never sleeps while a Pomodoro runs, so this needs no sleep interaction. Nothing here changes the CPU clock policy: a playing tone costs LEDC time, not CPU.

## Testing
- `make test`:
  - New `melody_test`: note boundaries, a rest outputs 0, the end gives 0 and `playing() == false`, `play` replaces a running melody, `stop`, timing starts at the first `update`, a late pass skips ahead and still ends on time, a `millis()` wrap mid-note, and every table is non-empty and under 500 ms.
  - Updated `dev_editor_test`: row 3 is SOUND, with a switch; toggle/restore order; stepping LOW↔HIGH and clamping at the ends; steppers inert while off; RESET restores the defaults but keeps WiFi refresh, which has no row in the panel.
  - Updated `settings_json_test`: `sd` is accepted for 0..3, rejected for 4, -1 and a string, and absent means unchanged.
  - Updated `device_settings_test`: `deviceClamp` holds `sound` to 0..3, and `operator==` sees it.
- `pio run`: the board build (catches C++11 issues in `melody.h`).
- `make bench`: still passes, with the buzzer stand-in.
- `./build/cube-shot build/shot @dev-edit`: the panel shows the SOUND row, switched on at MED. ADVANCE in the same shot shows what a switched-off row looks like.
- `swift test`: `CubeSettings` round-trips `sd`, and `sound` is nil when `sd` is absent, so it is never sent. That the popup is then hidden is checked by hand: the window is AppKit glue.
- Hardware (new `docs/buzzer-acceptance.md`, a checklist like the IMU and BLE ones):
  - [ ] With the cube idle and silent, the board near the LDO stays cool (compare with before the flash).
  - [ ] Each level is audible, with LOW clearly quieter than HIGH; the duties are tuned until it is.
  - [ ] A focus phase ending plays `FocusDone`, and a break ending plays `BreakDone`.
  - [ ] Sound OFF is silent everywhere.
  - [ ] The backlight does not flicker or change brightness while a tune plays (separate LEDC timers).

## Docs
- Root `CLAUDE.md` and `firmware/CLAUDE.md`:
  - A short Buzzer paragraph covering the pin, the separate LEDC timer, that `melody.h` is pure and host-tested, the `sd` setting, and that it is local-only.
  - The "Display panel" paragraph's list of rows changes (WiFi refresh becomes sound), and its NVS keys gain `sd`.
- `mac-helper/CLAUDE.md`: `sd` in the mirrored key list, and that `sound` is optional.
- README: a sound line in the device features and settings. `docs/ble-protocol.md`: the `sd` key and fw_rev 4.

## Risks
- **Loudness.** A passive buzzer behind a 3D-printed bezel may be quiet at LOW, or shrill at HIGH. The duty table and the pitches are tuned on the board; the structure does not depend on the values.
- **Board revision.** Only GPIO42 is supported. If an older GPIO33 board turns up, `PIN_BUZZER` is a one-line change, to be checked against that board's schematic first.
- **Losing REFRESH from the on-device panel.** It is still in the portal and on the Mac. With BLE as the main link it is rarely changed.

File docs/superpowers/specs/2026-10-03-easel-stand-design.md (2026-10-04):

# Easel desk stand — design

Date: 2026-10-03 · Status: approved; plan: docs/superpowers/plans/2026-10-03-easel-stand.md

## Goal

A second printed stand for the status cube, chosen from the concepts page as **A · Easel**.
The board stands at 65° in a slim bezel, carried on a low tray that holds the 12 × 40 × 65 mm
LiPo flat. Compared with the wedge (`3d-printing/stand.scad`) it looks lighter, it keeps the cell in its
own tray, and every part prints flat without supports. It lives alongside the wedge, and the two
share one copy of the board facts.

## Constraints

Carried over from the wedge spec (`docs/superpowers/specs/2026-10-02-desk-stand-enclosure-design.md`):
- the whole active area stays open, with no overlay;
- Type-C stays reachable, with a plug relief and an optional blanking cap;
- RST/BOOT/PWR are reachable through pinholes;
- plastic only near the antenna;
- FDM without supports.

New:
- **One source of truth for the board.** Move the board facts, fit tunables and board helpers out of
  `stand.scad` into `board.scad`. After the move, the wedge must render the same parts.
- **Stable under touch.** A press on the centre of the active area of at least 3.0 N must not tip the
  stand backwards, and neither must 1.3 N on its top edge. These are estimates from the meshes, not
  measurements.
- **Screws only, no glue:** 5 × M2 self-tapping.
- **`board_flip` needs no firmware change**, because auto-rotate is always on.

## Source dimensions

All board numbers come from `board.scad`, moved out of `stand.scad` unchanged, including its VERIFY
defaults. The easel adds three VERIFY items:
- **PCB mounting-hole positions.** The carrier's pegs go into these holes. They are assumed symmetric,
  as in the wedge spec. `peg_l = 0` turns the pegs off.
- **Where the MX1.25 connector sits** on the board's rear, and the route of the battery lead to it.
- **Which end of the cell the tabs leave from.** The design assumes the front.

## Frames and placement

- **World frame:** X = width, Y = depth (front edge y = 0), Z = up, with the desk at z = 0.
- **Board-local frame**, as in `stand.scad`: x = portrait right, y = into the stand from the glass
  front, z = portrait up. The origin is the glass's front-bottom-left corner.
- **Lean:** the board leans back by `lean = 90 − tilt` = 25°.
- **Origin:** `O = [(W − glass_b)/2, 6.2, deck + 9.1]`. `deck` = 17.6 is the top of the frame lid.
- **Deck plane** in board-local coordinates: z = −10.04 + 0.466·y.
- **Hinge line P:** the bezel's front-bottom edge, at board (y −1, z −10.51), which is world (y 0.85,
  z 17.6). The bezel swings about P.

## Design

### Form
Four printed parts and an optional cap:
- **Tray** (46 × 81 × 15.2): holds the cell flat.
- **Frame:** a 2.4 mm lid with a central fin; it closes the tray.
- **Carrier:** stands on the lid at 65° and holds the board from behind.
- **Bezel:** frames the glass from the front and hooks onto the carrier at the bottom.

The envelope is about 46 × 81 × 68 mm (W × D × H). The 55 g cell sits low and mostly behind the screen. That keeps the
centre of gravity far in front of the rear feet, which stops a press on the screen from tipping the stand backwards.

### Parts

#### 1. Tray
Prints open side up.
- Walls and floor 2.4 mm.
- **Battery bay** 40.8 × 65.8 × 12.8 (the cell plus 0.4 per side) at x 2.6–43.4, y 9.9–75.7, tab end
  towards the front.
- **Front space** (y 2.4–9.9, 7.5 mm deep) holds:
  - the bend of the battery lead;
  - two Ø4.2 screw pilasters at (14.5, 7.6) and (31.5, 7.6), webbed to the front wall.
- **Rear pilaster** Ø4.2 at (23, 77.9), merged into the rear wall.
- **Pilots:** Ø1.8 in every pilaster.
- **Feet:** four Ø8 × 0.8 recesses for rubber feet, 7 mm in from the corners.
- **Bottom edge:** 0.8 mm chamfer.

#### 2. Frame
Prints lid down.
- **Lid:** 2.4 thick, W × D, corner radius 4.
- **Holes:**
  - Ø2.4 clearance for the two leg screws;
  - Ø2.4 with a Ø4.2 × 1.6 counterbore for the rear screw;
  - two lead slots, 4.5 × 5.5, one beside each carrier leg, over the tray's front space.
- **Fin:** 5 mm thick, on the centre line, lightened with a window.
  - It sits 0.2 mm behind the carrier's rear face, up to board z 32, and runs back to y 65 on the lid.
  - Its job is to stop a press on the screen from flexing the carrier backwards.

#### 3. Carrier
Prints rear face down. The legs stand at 65°, so they need no supports.
- **Back plate:** the panel outline (x −3.2 to 36.33, top z 45.13, r 4) from y 7.3 to 9.7, cut by the deck.
- **Posts:** four, at the PCB holes.
  - Ø3 shoulders reach y 3.0, which preloads the PCB rear (y 3.2) by 0.2.
  - Ø1.8 × 1.0 pegs enter the holes. They hold the board in place while the bezel goes on.
- **Legs:** two, 6 mm wide, under the board.
  - Position: x 5.065–11.065 and 22.065–28.065; y 1.5–7.3; from the deck up to z −1.3.
  - Each takes a vertical M2 × 10 from above, at world (14.5, 7.6) and (31.5, 7.6). The Ø4.2 counterbore floor is 2.4 above the deck.
  - The screw passes through the leg and the lid into the tray pilaster, so one screw clamps all three parts.
- **Ridges:** one on each leg's front face, 1 mm proud (y 0.5–1.5). Each is an arc band from radius 3.2 to 4.4 about P.
- **Top-screw holes:** two Ø2.4 holes, with Ø4.2 × 1.6 counterbores from the rear face.
- **Plug relief:** the Type-C relief continues 1.3 mm into the back plate (y 7.3–8.6).

#### 4. Bezel
Prints face down.
- **Body:** the panel outline from y −1 (front face) to 7.3, cut by the deck. A 0.6 chamfer runs along the top and side edges of the front face.
- **Glass pocket and window:** the same as the wedge, with the chamfered window.
- **Open chin cavity:** x −0.3 to 33.43, from y 1.2 to the rear, and everything below the pocket. It
  leaves room for the legs, the screw heads and the battery lead.
- **Chin wall** (y −1 to 1.2): its top is lowered to z −0.6, so it clears a board that sags on its
  pegs while the bezel swings.
- **Grooves** for the ridges, cut into the chin wall's rear face:
  - an arc band from radius 3.0 to 4.6 about P;
  - from y 0.3 to the rear face;
  - across each leg's width plus 0.3 per side.
- **Top-screw pilots:** two, Ø1.8, from y 7.3 to −0.2, at board (−0.561, 41.691) and (33.691, 41.691).
  These are the corners between the glass and the outline, and both keep walls of at least 1.2.
- **Openings:** the Type-C slot, plug relief and RST/BOOT/PWR pinholes, as in the wedge. They follow `board_flip`.

#### 5. USB cap
Optional; prints flange down.
- A friction plug for the blind plug relief.
- Crush ribs on its ±z faces, only on the part of the plug that sits in the bezel.
- A 1.0 flange plus a pull ear, sitting on the side face at board x 36.33.

### Hinge
- Ridges and grooves are concentric about P, so swinging the bezel about P slides each groove along
  its ridge. The ridge leaves through the groove's open rear face, and nothing else meets.
- When closed, the ridges stop the chin lifting or sliding forward. The grooves also locate it sideways.
- The two top screws then fix the bezel to the carrier.

### Assembly
1. Put the cell in the tray, tab end forwards. Thread the lead up through the slot on the board's connector side.
2. Put the frame on and fit the rear M2 × 8.
3. Stand the carrier on the lid. Fit two M2 × 10 through the legs; they clamp carrier, lid and tray together.
4. Plug the lead into the board and press the board onto the pegs, glass outwards.
5. Hold the bezel tilted forward with its front-bottom edge on the lid. Swing it back over the glass, so the grooves pick up the ridges.
6. Fit two M2 × 6 from the carrier's rear.

To reach the board or the lead later, remove the two top screws and swing the bezel off.

### Hardware
- **Screws** (self-tapping into Ø1.8 pilots):
  - 2 × M2 × 6 for the top;
  - 2 × M2 × 10 for the legs;
  - 1 × M2 × 8 for the rear.
- **Feet:** 4 × Ø8 rubber feet.

### Parameters
- **`board.scad`:** the board facts, fit tunables and board helpers. It has no top-level geometry.
  - Facts: glass, active area, PCB, holes, openings.
  - Tunables: `clr`, `lip_t`, `win_*`, `board_flip`.
- **`easel.scad`:**
  - `tilt`, W, D and `wall`;
  - cell size and clearance;
  - leg, ridge, peg and screw positions, and the swing margin;
  - `part`, which selects the output.

## Deliverables

- **Shared file:** `3d-printing/board.scad`, with `stand.scad` changed to include it. The wedge output is unchanged.
- **`3d-printing/easel.scad`**, with these parts:
  - `tray`, `frame`, `carrier`, `bezel` and `cap`, in print orientation;
  - `assembly` and `section`, for viewing;
  - `at_*`, the parts in their assembled positions, for analysis.
- **STLs:** `3d-printing/easel-tray.stl`, `easel-frame.stl`, `easel-carrier.stl`, `easel-bezel.stl` and `easel-usb-cap.stl`.
- **`3d-printing/tools/stability.py`:** works out mass, centre of gravity and tip force from the `at_*` STLs
  and the reference points that `easel.scad` echoes.
- **`3d-printing/test.sh`:** covers both stands. `./test.sh stand` or `./test.sh easel` runs one.
- **README:** an Easel section. The stale `docs/enclosure/` paths and the old `setRotation` note are fixed.

## Verification

`./test.sh` runs OpenSCAD with the manifold backend and checks the following.

**Parts**
- Every part renders, is manifold and stays inside its size envelope.
- Each part also renders at tilt 55, 65 and 75, and with `board_flip`.

**Fit and clearance**
- No part collides with another part, the board ghost or a cell ghost.
- This also holds with a 15 mm cell, with `clr` 0.5 and with a 9 mm board.
- The window clears the active area.
- Pilot walls are at least 1.2.
- The leg screw heads sit inside the leg and clear the bezel.
- The lead slots open into the chin cavity above and the tray's front space below.

**Hinge**
- The ridges sit inside the grooves.
- With the bezel swung 5, 10, 20 and 30° about P, it clears the carrier and the board, and the board is
  checked both at nominal and sagged 0.2 mm on its pegs.

**Board mount**
- The pegs sit inside the PCB holes.
- The shoulders press on the PCB.
- The cap seats in the relief.

**Stability**
- `stability.py` reports at least 3.0 N at the centre of the active area and at least 1.3 N at the top edge.

Every check also has a positive control that must fail, such as a part moved or a margin removed. That
catches a check that could never fail.

**After the tests:** print the carrier first and check the pegs against the real board before printing the rest.

## Risks

- **PCB hole positions are assumed.** If the pegs are wrong, the board will not seat. Shorten the pegs
  (`peg_l`) or turn them off; the shoulders still press the PCB.
- **Tip force is an estimate.** It assumes 0.9 solidity at 1.24 g/cm³, a 55 g cell and a 12 g board, and
  it takes a pivot 1 mm inside the rear edge of the rear feet.
- **The hinge has 0.2 mm clearances in printed plastic.** If it binds, sand the ridges or reduce `ridge_t`.
- **Lead routing.** The lead must pass beside a leg and behind the PCB to the MX1.25. Check this on the first build.
- **Battery polarity and LiPo safety:** as in the wedge README.

## Out of scope

- Replacing the wedge. It stays, and choosing between the two is the user's call.
- Adjustable tilt.
- Firmware or bridge changes.

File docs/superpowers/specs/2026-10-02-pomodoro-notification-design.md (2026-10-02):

# Pomodoro phase-end notification on the Mac

## Goal

When a Pomodoro phase ends on the cube, `ClaudeCubeLink.app` shows a macOS notification, so the
user notices at the Mac even when not looking at the cube.

## Decisions (agreed)

- Notify on **every phase end** (focus, short break, long break), each with its own text.
- The cube announces the event over BLE (approach A). The Mac does not mirror the timer.
- Works over BLE only. WiFi-only setups have no cube-to-Mac path and are out of scope.
- A mute checkbox lives in the **menu bar dropdown**, stored in the Mac's `UserDefaults`
  (default on). It is not a cube setting and not part of the Settings characteristic.
- The cube's own on-screen alert is unchanged.

## Protocol

New Control (cube -> Mac) message, additive; protocol version stays 1:

| Bytes | Meaning |
|---|---|
| `04 <ended> <next>` | a Pomodoro phase just ended. `<ended>`/`<next>`: `00` focus, `01` short break, `02` long break |

- Fire-and-forget Control notify, no ack, no retry. If no Mac is subscribed it is dropped.
- A Mac that does not know `04` ignores it (`ControlMessage.parse` returns nil).
- Documented in `docs/ble-protocol.md`; a frame is added to `firmware/sim/fixtures/ble-frames.txt`
  so `make test` and `swift test` both pin the encoding.

## Firmware

- `net_ble.cpp`: `bleNotifyPomodoro(uint8_t ended, uint8_t next)` notifies Control. No-op when
  there is no connected, subscribed Mac. Stubbed in `net_ble_off.cpp` and `sim/ble_sim.cpp`.
- `main.cpp`: inside the existing `if (pomo.takeAlert())` block, read `pomo.view()` (state DONE:
  `phase` = ended phase, `next` = what a long-press starts) and call `bleNotifyPomodoro`.
- The frame encoding lives in a pure helper next to `ble_frame.h` so it is host-tested.
- Bump `fw_rev` per the Settings precedent so the Mac can tell the event exists (informational;
  the Mac does not gate on it).

## Mac helper

- `Protocol.swift`: `ControlMessage.pomodoroEnded(ended: PomoPhase, next: PomoPhase)`. A frame
  shorter than 3 bytes or with a phase code above 2 parses to nil.
- `CubeLinkCore`: pure `PomodoroNotice` mapping (ended, next) to title/body:

  | Ended | Next | Title | Body |
  |-------|------|-------|------|
  | focus | short break | Focus done | Take a short break |
  | focus | long break | Focus done | Take a long break |
  | short/long break | focus | Break over | Time to focus |

  Any other combination falls back to title "Pomodoro", body "Phase finished".
- `CubeLink`: new `onPomodoroEnded` callback invoked from the Control handler (next to the
  existing `Trace.log("ble", "control: ...")`).
- `ClaudeCubeLink` target: a `Notifier` posts through `UNUserNotificationCenter`; it requests
  authorization once at launch. `StatusMenu.swift` wires `onPomodoroEnded` to it, gated by the
  mute flag.
- Menu: a checkable item "Pomodoro notifications" in the dropdown, backed by `UserDefaults`
  (default on). If authorization is denied the item shows as disabled with the hint
  "Notifications off in System Settings".
- No queueing: an event that arrives while the Mac is disconnected is lost.

## Testing

- Host: frame encoding fixture (`make test`), `ControlMessage.parse` cases including malformed
  frames, and the `PomodoroNotice` mapping (`swift test`).
- Hand: finish a phase on the cube with `POMO_FAST` firmware or a short duration set in the
  Pomodoro editor; confirm the notification, the mute checkbox, and the denied-permission state.
- Add an item to `docs/ble-acceptance.md` for the on-hardware check (the BLE path has not yet
  been run on a real cube).

## Out of scope

WiFi delivery, notifications for pause/start/reset, per-phase mute, a notification sound
setting, a cube-side toggle, and queueing missed events.

## Docs to update on implementation

`CLAUDE.md` (Transports paragraph), `docs/ble-protocol.md`, `docs/ble-acceptance.md`, `README.md`
if it lists the menu items.

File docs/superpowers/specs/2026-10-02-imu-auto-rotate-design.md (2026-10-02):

# IMU auto-rotate (180°) — design

## Goal

When the cube is turned upside down, the display redraws rotated 180° so it stays
readable, and touch/swipes still feel correct. Portrait and upside-down only.

Out of scope: landscape, flip/shake as an input gesture, any on/off setting
(always on; decided with the user), gyro use, the IMU interrupt pin.

Assumption: the cube is usually stood upright or hung, and often rests flat, face up.
USB-C sits on a side edge, so its position is irrelevant to the logic; only the
sign of the accelerometer axis that runs along the screen's vertical axis matters.

## Approach

Rotate the panel in hardware (`lcd.setRotation(0|2)`) and leave the renderer alone.
`ui.cpp` composes one 240x280 sprite and pushes it, so card/ring/editor layouts
and `preview.html` are untouched. Touch is remapped before it reaches
`GestureTracker`, so swipes and both editors work unchanged.

## Components

1. **`imu.h/.cpp`** (hardware-only) — minimal QMI8658C driver on the shared `Wire`
   bus, address `0x6B` (`QMI8658_ADDR` in `board_pins.h`). Accelerometer only, low
   ODR, one call `bool imuReadAccel(float &ax, float &ay, float &az)` in g.
   Absent/not answering → returns false and orientation stays at 0; never blocks boot.
2. **`orientation.h`** (pure, host-tested, no Arduino) — `Orientation` class:
   `update(now, up, az, busy)` → true when the rotation (0 or 2) changed. `up` is the
   accelerometer axis along the screen's vertical, signed by `IMU_UP_SIGN` so that
   `+1 g` means "screen top is up".
   - A flip candidate exists only when `|up| > 0.6 g` **and** `|up| > |az|` (so a cube
     lying flat or tilted past 45° towards face-up never flips) and it points away
     from the current orientation. It must hold for 1000 ms.
   - Anything else (flat, in the dead zone, pointing at the current orientation)
     clears the candidate and keeps the orientation. Needing `up < -0.6` to go to 2
     and `up > +0.6` to come back is the hysteresis.
   - `busy` (finger down) defers a pending flip; it lands right after the finger
     lifts if still wanted.
3. **`board_pins.h`** — `IMU_UP_SIGN` (+1/-1): which sign of the IMU axis means
   "screen top is up". Needs confirming on the first hardware run.
4. **`main.cpp`** — poll the IMU ~5 Hz from the main loop; when `Orientation`
   changes, call `lcd.setRotation(r)`, set the touch-remap flag, and force a full
   redraw. Touch remap: for rotation 2, `x → LCD_WIDTH-1-x`, `y → LCD_HEIGHT-1-y`,
   applied where `touch.read()` results are consumed. Remap lives in a small pure
   helper so it is host-tested.
5. **Simulator** — `imu_sim.cpp` returns a gravity vector from `CUBE_ORIENT=0|2`
   (default 0), so `make run` flips after ~1 s; `touch_sim.cpp` undoes the remap so
   `main.cpp` sees raw panel coordinates as on hardware. `make shot` is **not**
   affected: it reads pixels back with `readRect` in LovyanGFX's already-rotated
   logical frame, so a flipped frame looks identical there. The flip is only visible
   in the `make run` window.

## Interactions to preserve

- Screen sleep: IMU motion is **not** activity; it neither wakes the screen nor
  resets the idle timer. Orientation is still tracked while asleep (the CPU runs at
  80 MHz then; 5 Hz reads are negligible) so the first frame on wake is correct.
- Editors and Pomodoro: rotation may change while an editor or timer is open;
  state is untouched, only the output and touch mapping change.
- Boot: orientation starts at 0 and is corrected within ~1 s if the cube boots upside down.

## Error handling

IMU missing or I2C errors → treat as "no reading", keep current orientation, log once
to Serial (`[imu] not responding`), same style as `touch.cpp`. A bad IMU never
affects touch or display.

## Testing

- Host (`make test` in `firmware/sim/`): `Orientation` — flips after hold, not before;
  flat readings never flip; hysteresis band; `busy` defers; flips back; touch remap
  helper for both rotations incl. corners.
- Simulator: `CUBE_ORIENT=2 make run` shows the rotated frame and a left swipe with
  the mouse still advances the card.
- Hardware only (open checklist, like `docs/ble-acceptance.md`): `IMU_UP_SIGN` is
  right; no band at an edge after rotation (the 20 px `LCD_OFFSET_Y` is symmetric
  in the 40 spare rows of the 320-row frame, so it should be unchanged under
  rotation 2; if a band appears, adjust the offset in `display.h`); touch lands
  where drawn when flipped; no I2C errors from touch while polling; QMI8658
  `WHO_AM_I` (reg `0x00`) reads `0x05` in the boot log.

## Docs

Update CLAUDE.md (new "Auto-rotate" paragraph, local-only: not in payload or
`preview.html`, hardware layer `imu.cpp` with sim stand-in) and the Commands list
(`CUBE_ORIENT`).

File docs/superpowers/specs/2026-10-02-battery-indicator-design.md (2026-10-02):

# Battery indicator in the top bar

## Goal
Show the Li-ion battery percentage on every card, so the cube's charge is visible at a glance. Purely on-device: the bridge, the payload contract, `cards.mjs` and `preview.html` do not change.

## Non-goals
- Charging bolt / charge state. The board docs list no charge-status GPIO (ETA6098 STAT is not routed to a documented pin). Revisit only if the schematic shows one.
- A dedicated battery card, low-battery sleep, or any power management.
- Mirroring in `preview.html` (it is device-local, like the Pomodoro card).

## Design

### Measurement: `firmware/src/battery.{h,cpp}`
- Reads `PIN_BAT_ADC` (GPIO1), `VBAT = VADC x 3` (200K/100K divider).
- `analogReadMilliVolts` averaged over 16 samples, sampled every ~5 s from the main loop (not every frame).
- `batteryPercent(mv)`: pure function, piecewise-linear Li-ion discharge table (4200 mV = 100, 3700 = ~50, 3300 = 0), clamped.
- Smoothing: pure `BatteryFilter` (exponential moving average on mV, first sample seeds it) so the number does not flicker with WiFi TX bursts.
- No cell: if smoothed mV is below 2500 (floating pin, USB-only), the cube can only be running from USB, so `pct = 100` and `onUsb = true`. No separate cable detection is needed or available. With a cell fitted, the percentage comes from the voltage (while USB charges, the cell sits near 4.2 V, so it reads ~100 anyway).
- API: `struct BatteryView { uint8_t pct; bool onUsb; }`, `batteryBegin()`, `batteryUpdate(uint32_t nowMs)`, `batteryView()`.

### Drawing: `ui.cpp`
- `drawTopBar` gains a `const BatteryView &bat` parameter (passed through `uiRender`).
- Layout, right side of the bar (Y = 24): `[label ........ battery pct%  | age dot]`. The battery glyph (~18x9 px outline + nub, fill proportional to pct) and `NN%` in `V_S12` sit left of the age readout, with a ~10 px gap.
- Colour via existing palette: green >= 40, amber 15..39, red < 15. The text and glyph fill share the colour; the outline is `DIM`.
- Always drawn. With `onUsb` (no cell) it shows `100%` in green, so the glyph is full.
- Left label gets a max width (bar width minus right cluster) and is truncated if longer.
- Applies to every card, including Pomodoro. Not drawn on the editor, portal, OTA or message screens.

### Simulator and tests
- `firmware/sim/battery_sim.cpp` replaces `battery.cpp`'s hardware read; level from env `CUBE_BATTERY` (percent, or `none` for the no-cell / USB case, which shows 100%), default 78.
- `cube-shot` picks it up, so `CUBE_BATTERY=10 ./build/cube-shot ...` shows red, `none` shows a full 100% indicator.
- Host tests (`make test`): `batteryPercent` table points and clamping, `BatteryFilter` seeding and convergence, the no-cell threshold (reads 100%).

### Docs
- README and CLAUDE.md: one line each noting the on-device battery indicator, `CUBE_BATTERY` in the simulator, and that it is not in the payload contract.

## Risks
- Voltage-to-percent is an estimate (load and temperature shift it); the table is approximate and the number is labelled `%` only.
- The ADC is not factory-calibrated beyond what `analogReadMilliVolts` provides; accept +-50 mV error.
- Right cluster width grows ~45 px; verify with `make shot` that nothing clips at the rounded corners for 3-digit ages (`99m`) and `OFFLINE`.

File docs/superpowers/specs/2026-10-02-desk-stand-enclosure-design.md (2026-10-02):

# Desk stand enclosure — design

Date: 2026-10-02 · Status: implemented; see the plan's "Deviations from the spec" (docs/superpowers/plans/2026-10-02-desk-stand-enclosure.md) for what changed and why

## Goal

A 3D-printable desk stand for the Claude status cube: it holds the Waveshare
ESP32-S3-Touch-LCD-1.69 and a 12 × 40 × 65 mm LiPo, with the screen tilted back
for reading on a desk. Output is parametric OpenSCAD plus print-ready STLs.

## Constraints (from the project and the user)

- Touch must stay fully usable: tap, swipe, and the Pomodoro 600 ms / 2 s
  long-press all use the CST816T panel, so the active area is an open window with no overlay.
- Type-C stays reachable with the battery installed (flashing, charging, serial).
- RST, BOOT and PWR stay reachable. BOOT is held through boot for the 5 s
  setup-portal entry and for download mode.
- The chip antenna (2.4 GHz) is not covered by the battery or any metal; the body is plastic only.
- FDM printable without a multi-material setup; support use minimised.
- The user chose: **angled wedge**, **two-part shell closed with 4 × M2 screws**.

## Source dimensions

From the Waveshare drawing in `docs/ESP32-S3-Touch-LCD-1.69.md` (landscape view):

| Item | Value (mm) |
|---|---|
| Glass outline | 41.13 × 33.13, rounded corners |
| Active area | 32.634 × 27.972 |
| PCB | 37.12 × 29.83 |
| Mounting hole centre | about 4.16 from PCB left edge, about 1.75 from PCB top edge (top-left hole; assumed symmetric) |
| Battery | 12 × 40 × 65 |

**Not in the drawing, set as defaults and marked `VERIFY` in the SCAD file:**
total board thickness (7), mounting hole diameter (2.2), corner radius of the glass (4),
battery corner radius (1), connector and button positions along their edges.

**Orientation (inferred, to confirm on the first print).** Firmware uses
`setRotation(0)`, i.e. portrait 240 × 280. The flex cable sits on the drawing's left
edge, which becomes the bottom in portrait. So Type-C and the MX1.25 battery
connector face the **right** wall, and RST/BOOT/PWR face the **left** wall.
A single `board_flip` parameter rotates the board 180° (a mirror is physically wrong) and also needs `lcd.setRotation(2)` in `firmware/src/main.cpp`.

## Design

### Form
Wedge. Screen on the sloped front face at `tilt = 65°` from the desk. Battery lies
flat in the base under the board's lower part and extends rearward under a low back
section. Envelope: about 86 deep × 48 wide × 64 high (the 65 mm battery plus screw bosses sets the depth, and a 5 mm top margin keeps the apex skin thick at tilts of 55°–75°). The heavy cell sits at the bottom, so the stand does not tip.

### Parts
1. **Front shell:** sloped face with screen window and 1 mm bezel lip, side and back
   walls (2.4 mm), 4 base-plate screw bosses, port and button cutouts.
2. **Base plate:** closes the underside with 4 × M2 screws; 4 rubber-foot recesses;
   battery retaining ribs. Removing it exposes the battery and the board's back.

### Board mount
Board is inserted from inside. The glass seats against a 1.0 mm lip. The glass covers the
front of the PCB mounting holes, so screws cannot be used; instead two vertical pusher posts on
the base plate press the PCB's rear edge up and forward (0.2 mm preload). Foam tape on the pusher tips is the fallback if the board rattles. Glass pocket is
glass outline + 0.3 mm per side, with matching corner radii. Window is the active area + 1 mm margin
per side, so the whole touch surface is exposed.

### Battery bay
Pocket 65 × 40 × 12 + 0.4 mm clearance per side (65.8 × 40.8 × 12.8). Finger gaps
between the base-plate ribs allow removal. The interior is one open volume, so the MX1.25 lead
routes freely. The bay position relative to the chip antenna is unverified and must be checked
physically.

### Openings
- Type-C: about 9.5 × 3.5 mm slot + 0.4 clearance in the right wall.
- Buttons: 3 × Ø2 pinholes in the left wall, aligned to RST / BOOT / PWR.

### Parameters
All dimensions are named variables at the top of `stand.scad`: board, glass, battery,
tilt, wall, clearance, screw size, foot size, `board_flip`, `insert_mode`
(self-tapping bosses by default; heat-set inserts optional).

## Deliverables

- `docs/enclosure/stand.scad`
- `docs/enclosure/stand-front.stl`, `docs/enclosure/stand-base.stl`
- `docs/enclosure/fit-check.stl`: a small, quick print (window + pocket + port slot
  only) for validating the unknown dimensions before printing the full stand
- `docs/enclosure/README.md`: print orientation, layer height (0.2 mm), supports,
  screws needed, assembly order, battery polarity warning
- Preview PNGs from OpenSCAD (front, back, and a section through the battery bay)

## Verification

There is no CAD test suite. Verification is:
1. OpenSCAD renders both parts without CGAL errors; STLs are manifold.
2. Preview PNGs and the battery-bay section confirm: battery fits with clearance, board
   rear components do not touch the battery, the window frames the active area, and the
   cutouts line up with the connector and button positions in the drawing.
3. The user prints `fit-check.stl` and reports fit; defaults are corrected before the full print.

## Risks

- **Battery polarity:** MX1.25 pinouts vary by vendor. Check against the board's
  `+`/`−` marks before connecting. This goes in the README.
- **Unknown thickness and hole diameter:** may force a parameter tweak after the fit check.
- **Orientation inference:** if wrong, set `board_flip`.
- **LiPo safety:** the pocket must not compress the cell. Clearance is intentional, and
  the base plate must not press on it.

## Out of scope

Wall mounting, a hinge or adjustable tilt, wireless charging, and changes to the firmware
or bridge.

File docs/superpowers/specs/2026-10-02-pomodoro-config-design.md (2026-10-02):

# On-device Pomodoro configuration

Date: 2026-10-02 · Status: draft, awaiting review

## Goal

Change the Pomodoro focus length, short break, long break and sessions-before-long-break from the cube's touchscreen, with no host, bridge or reflash involved. Values persist across reboots.

## Non-goals

- No bridge config, payload field or setup-portal fields (the bridge never learns about the Pomodoro).
- No editing while a phase is running or paused.
- No change to how phases start (still long-press only) or to the alert.
- No `preview.html` change: the Pomodoro card and its editor are local-only.

## Behavior

**Opening.** On the Pomodoro card, while the timer is idle (`POMO_IDLE`), a swipe up opens the editor. In every other timer state, and on every other card, a swipe up does nothing (as vertical travel does today). Tap and horizontal swipes keep their current meaning on the Pomodoro card.

**Editor screen** (240x280). From the top: a title, four rows, then a button row.

| Row | Step | Range | Default |
|---|---|---|---|
| FOCUS | 5 min | 1-99 | 25 |
| SHORT | 1 min | 1-99 | 5 |
| LONG | 5 min | 1-99 | 15 |
| SESSIONS | 1 | 1-9  | 4 |

Each row shows its label, the value, and a `-` and `+` touch target of at least 44x44 px. Stepping by 5 snaps to multiples of 5, with 1 as the lower bound: `+` goes to the next multiple of 5 above the value and `-` to the next one below it (1 +> 5 +> 10, 10 -> 5 -> 1, 27 +> 30, 27 -> 25). Values clamp at the range ends. The button row has **RESET** (left) and **DONE** (right), also at least 44 px tall.

**Leaving.** DONE or a swipe down saves and returns to the Pomodoro card. RESET sets all four rows to the compile-time defaults (`config.h` values, else 25/5/15/4); it only changes the rows on screen, and DONE (or swipe down) then saves, so there is no separate undo. There is no cancel: every change is visible as it is made, and RESET is the way back.

**While open.** Auto-rotate and bridge polls still run, but nothing may move the deck off the editor: `step()` and the poll's `deckKeepIndex` are bypassed while it is open. The phase-end alert cannot fire because the timer is idle.

## Components

### Persistence: `settings.h/.cpp`

```cpp
struct PomoSettings { uint8_t focusMin, shortMin, longMin, sessions; };
const PomoSettings &pomoSettings();
bool pomoSettingsSave(const PomoSettings &s);
```

NVS namespace `cube`, keys `pf`, `ps`, `pl`, `pn` (u8). A key that was never stored falls back to `POMO_FOCUS_MIN` / `POMO_BREAK_MIN` / `POMO_LONG_MIN` / `POMO_SESSIONS` from `config.h`, else the defaults above, so a fresh or older cube behaves as it does now. Loaded values are clamped to the ranges above (a bad NVS value never reaches the timer). `settingsLoad()` loads it with the rest. The `POMO_*` defaults move from `main.cpp` into a shared header (`pomo_defaults.h`) so `settings.cpp`, the editor's RESET and `main.cpp` share one source. `sim/settings_sim.cpp` gets an in-memory stand-in.

### Timer: `pomodoro.h/.cpp`

`void Pomodoro::setConfig(const PomoConfig &cfg)` replaces the config and is ignored unless the state is `POMO_IDLE`. It does not touch the completed-session count. `main.cpp` builds the `PomoConfig` from `pomoSettings()` using the existing `* 60000UL / POMO_TIME_DIV` conversion, so `make run POMO_FAST=60` is unchanged.

### Gesture: `gesture.h/.cpp`

Add `SwipeUp` and `SwipeDown`. A touch is vertical when travel is at least `SWIPE_MIN_PX`, within `SWIPE_MAX_MS`, and `|dy| > |dx|`. Horizontal classification is unchanged, and a diagonal swipe goes to whichever axis dominates. `SwipeUp`/`SwipeDown` are reported on every card; `main.cpp` acts on them only as above.

### Editor logic: `pomo_editor.h/.cpp` (new, pure)

No Arduino or LovyanGFX dependency, so it builds in `make test`.

```cpp
enum class EditAction { None, Dec, Inc, Reset, Done };
struct EditHit { EditAction action; uint8_t row; };  // row valid for Dec/Inc
EditHit pomoEditorHit(int16_t x, int16_t y);          // layout constants live here
void pomoEditorApply(PomoSettings &s, EditHit hit);   // step/snap/clamp/reset
```

The layout rectangles are constants shared with the renderer so hit-testing and drawing cannot drift apart.

### Screen: `ui.cpp` / `ui.h`

`void uiPomodoroEditor(Display &lcd, const PomoSettings &s)` draws the editor into the same full-screen sprite as the cards, using the existing palette, fonts and `fitFont`. No animation. The editor adds no new state to `uiRender`; `main.cpp` calls `uiPomodoroEditor` instead of `uiRender` while open.

### Wiring: `main.cpp`

An `editing` flag plus a working `PomoSettings` copy.
- `pollTouch`: on the idle Pomodoro card, `SwipeUp` sets `editing`, copies the current settings, and marks dirty. While `editing`, `Tap` is hit-tested and applied, `SwipeDown` and DONE call `pomoSettingsSave`, `pomo.setConfig`, clear `editing`, and `uiReplayPomodoro()`. Holds are disabled while editing (`holdEnabled` false), so a long press cannot start a session behind the editor.
- `loop`: skip `step()` and the poll's index adjustment while `editing`.
- `setup`: construct `pomo` from `pomoSettings()` after `settingsLoad()` (the global initialiser moves into `setup()` or uses `setConfig` once settings are loaded).

## Verification

Host tests (`make test` in `firmware/sim/`):
- Gesture: vertical swipe up/down, a diagonal resolved by dominant axis, and a short drag below `SWIPE_MIN_PX` stays a tap or nothing.
- Editor: step, snap-to-5 (including 1<->5), clamping at both ends, RESET, hit-testing for every row and button, and a miss returning `None`.
- Pomodoro: `setConfig` applies while idle and is ignored while running, paused or done.
- Settings: clamping and fallback are checked through the pure clamp helper (NVS itself is board-only).

Simulator: `make run` (open with a vertical mouse drag, adjust with clicks); `./build/cube-shot build/shot @pomo-edit` renders the editor headlessly; `make run POMO_FAST=60` confirms a changed length is honoured by the next focus phase. On hardware: change values, reboot, confirm they persist and that a fresh flash with an empty NVS still uses `config.h`.

## Docs

README: a short "Configuring the Pomodoro" section. CLAUDE.md: extend the Pomodoro paragraph (swipe up on the idle card opens the on-device editor, persisted in NVS keys `pf/ps/pl/pn`; the gesture and editor logic are pure and host-tested; the editor is not in the payload contract).

## Risks and open points

- Vertical swipe on the 240x280 panel near the edges may be affected by the CST816's edge behavior; verify on hardware, and if it is flaky, widen the allowed start region rather than the gesture.
- `main.cpp` currently constructs `pomo` as a global from compile-time values; moving construction after `settingsLoad()` must keep the sim (`sdl_main.cpp`) building.

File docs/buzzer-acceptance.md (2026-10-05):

# Buzzer: hardware acceptance checklist

The sequencer (`melody.h`) and the SOUND row are host-tested, and the simulator logs
every play. Nothing here has run on a real cube yet. Work through this after flashing
(`pio run -t upload && pio device monitor`). To reach a phase end quickly, set FOCUS
and SHORT BREAK to 1 min in the Pomodoro editor (swipe up on the idle Pomodoro card).

## Boot and idle

- [ ] No `[buzz] ledc setup failed` appears in the boot log.
- [ ] No click or tone at power-up or reset.
- [ ] After 10 minutes idle and silent, the area around the 3.3 V regulator is no
      warmer than with the previous firmware, which left the pin floating.
- [ ] Flashed over firmware without a buzzer (nothing stored under `sd`), the display
      panel shows SOUND MED, and the first phase end beeps.

## Tunes

- [ ] A focus phase ending logs `[buzz] focus-done @MED` and plays three rising notes.
- [ ] A break ending logs `[buzz] break-done @MED` and plays a tune you can tell
      apart from the first.
- [ ] Neither tune is cut short or stretched while the ring and the backlight pulse.

## Levels

- [ ] In the display panel (swipe down), SOUND's `-` / `+` step through LOW, MED and HIGH,
      and each step beeps at the new level. LOW is clearly quieter than HIGH, and LOW
      is still audible across a desk. If not, tune `DUTY` in `buzzer.cpp` (and the
      pitches in `melody.h`), reflash, and repeat.
- [ ] A tap on SOUND's label turns it OFF without a beep. Another tap restores the level.
- [ ] With SOUND OFF, a phase end is silent and logs no `[buzz]` line.
- [ ] Switching SOUND OFF while a tune plays silences it at once.
- [ ] A level set from the Mac (**Cube settings…** > Sound) or in the portal is the one
      the next phase end plays at.
- [ ] On a Mac helper connected to a cube that has this firmware, the settings window
      shows Sound. On older firmware it does not.

## Backlight

- [ ] While a tune plays, the backlight neither flickers nor changes brightness, at any
      brightness setting. The buzzer's LEDC timer 0 is separate from the backlight's
      timer 3.

## Board revision

- [ ] If nothing sounds even at HIGH while the log shows `[buzz]` lines, check the board
      revision: an older one wires the buzzer to GPIO33. Confirm that on the board's
      schematic before changing `PIN_BUZZER` in `board_pins.h`.

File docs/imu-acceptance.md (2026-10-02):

# IMU auto-rotate: hardware acceptance checklist

The classifier and the touch remap are host-tested, and the flow is exercised in
the simulator. Nothing here has run on a real cube yet. Work through this after
flashing (`pio run -t upload && pio device monitor`).

## Boot log

- [ ] `[imu] QMI8658 who-am-i 0x05` appears right after `[touch] CST816 chip id ...`.
      If it says "not responding", check `QMI8658_ADDR` in `board_pins.h` (`0x6A`
      is the other possible address) and the I2C pins. Touch must still work.

## Direction

- [ ] Stand the cube on its edge so the picture is the right way up. It must stay
      as is. (If it flips to upside down after about a second and back, `IMU_UP_SIGN`
      in `board_pins.h` is wrong: change `1` to `-1` and reflash.)
- [ ] Turn it over 180° on its edge. After about 1 s the picture rotates and
      `[imu] rotation -> 2` is logged. Turn it back: `rotation -> 0`.
- [ ] Lay it flat face up, then face down, and tilt it about 30° either way: the
      picture never flips.

## Display

- [ ] After the flip there is no band or shift at either screen edge. The 20 px
      `LCD_OFFSET_Y` is symmetric in the 40 spare rows of the 320-row frame, so it
      should be unchanged; if a band appears, adjust the offset in `display.h`.
- [ ] Colours are unchanged (no inversion after `setRotation`).

## Touch

- [ ] Upside down: a tap on a visible control (e.g. the DONE bar of the display
      panel, swipe down to open it) lands where it is drawn.
- [ ] Upside down: swipe left advances the card, swipe right goes back, swipe down
      opens the display panel from the top **of the picture**, swipe up closes it.
- [ ] Hold a finger on the screen and turn the cube: the picture does not flip until
      the finger lifts, and no swipe fires.
- [ ] No touch drops or I2C errors in the log while the IMU is polled (watch for a
      minute).

## Sleep and boot

- [ ] Let the screen sleep (`SCREEN_SLEEP_MS`), flip the cube, then touch: it wakes
      already the right way up, and that wake touch does not change the card.
- [ ] Moving the cube alone never wakes a sleeping screen.
- [ ] Power the cube up upside down: after the boot screens the picture rotates
      within about a second.

## Simulator (a human at the window)

- [ ] `cd firmware/sim && CUBE_ORIENT=2 make run`: the window flips about a second
      after start. The picture is upside down, so its left edge is the window's
      right edge: dragging the mouse **left-to-right** (towards the picture's left)
      advances the card and right-to-left goes back. Keep the `touchToScreen(...)`
      call in `firmware/sim/touch_sim.cpp`; without it the directions are wrong.

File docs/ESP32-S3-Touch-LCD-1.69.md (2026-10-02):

# ESP32-S3-Touch-LCD-1.69

URL: https://docs.waveshare.com/ESP32-S3-Touch-LCD-1.69

SP32-S3-Touch-LCD-1.69 (https://www.waveshare.com/esp32-s3-touch-lcd-1.69.htm)

The ESP32-S3-Touch-LCD-1.69 is a low-cost, high-performance microcontroller development board designed by Waveshare. Powered by the **ESP32-S3R8** dual-core LX7 processor (240 MHz) with 2.4 GHz Wi-Fi and Bluetooth 5 (LE), featuring 512KB SRAM, 8MB stacked PSRAM and 16MB Flash. Its compact form factor integrates a 1.69inch capacitive touch LCD (240×280), Li-battery charging, a 6-axis IMU, RTC, and other peripherals, making it convenient for rapid prototyping and embedded applications.

| SKU | Product |
| --- | --- |
| 27350 | ESP32-S3-Touch-LCD-1.69 |

**If you are looking for:**

- **Schematics, datasheets, and example code** : See [Resources](https://docs.waveshare.com/ESP32-S3-Touch-LCD-1.69/Resources-And-Documents)
- **Arduino development** : See [Working with Arduino](https://docs.waveshare.com/ESP32-S3-Touch-LCD-1.69/Arduino)
- **ESP-IDF development** : See [Working with ESP-IDF](https://docs.waveshare.com/ESP32-S3-Touch-LCD-1.69/ESP-IDF)
- **Troubleshooting** : See [Product FAQ](https://docs.waveshare.com/ESP32-S3-Touch-LCD-1.69/FAQ) or contact [Technical Support](https://docs.waveshare.com/ESP32-S3-Touch-LCD-1.69/Technical-Support)

## Onboard Resources

ESP32-S3-Touch-LCD-1.69 Hardware Resources 1

1. **ESP32-S3R8** Wi-Fi and Bluetooth SoC, 240 MHz, 8MB stacked PSRAM
2. **W25Q128JVSIQ** 16MB NOR Flash
3. **PCF85063** RTC clock chip
4. **QMI8658** 6-axis IMU (3-axis gyroscope + 3-axis accelerometer)
5. **ETA6098** high-efficiency Li-battery charging chip
6. **MX1.25 Li-battery connector** MX1.25 2P connector for 3.7V Li-battery, supports charging/discharging
7. **Type-C port** ESP32-S3 USB, for program uploading and log printing
8. **Buzzer** audible peripheral
9. **RTC battery connector** for rechargeable RTC battery, supports charging/discharging
10. **Onboard chip antenna** supports 2.4 GHz Wi-Fi (802.11 b/g/n) and Bluetooth® 5 (LE)
11. **Power function button** supports power-on detection, single-click, double-click, multi-click and long-press
12. **BOOT button**
13. **RST reset button**

### Peripheral Quick Reference

| Module | Device / Function | Interface | Address / Parameters | GPIO / Signal |
| --- | --- | --- | --- | --- |
| LCD | ST7789V2 | 4-wire SPI | 240×280, RGB565, MISO unused | DC=GPIO4, CS=GPIO5, CLK=GPIO6, DIN=GPIO7, RST=GPIO8, BL=GPIO15 |
| Touch | CST816T capacitive touch | I2C | 7-bit address `0x15` | SCL=GPIO10, SDA=GPIO11, RST=GPIO13, INT=GPIO14 |
| IMU | QMI8658C 6-axis sensor | I2C | 7-bit address `0x6B` | SCL=GPIO10, SDA=GPIO11, INT1=GPIO38 |
| RTC | PCF85063ATL | I2C | 7-bit address `0x51` , 32.768 kHz crystal | SCL=GPIO10, SDA=GPIO11, INT=GPIO39 |
| Buzzer | Onboard buzzer | GPIO / PWM | - | GPIO42 |
| Battery sampling | B+ voltage divider to ADC | ADC | R3 pull-up 200K, R7 pull-down 100K; VBAT=VADC×3 | GPIO1 / BAT_ADC |
| Power control | SYS_OUT / SYS_EN | GPIO | PWR / Key2 power circuit | SYS_OUT=GPIO40, SYS_EN=GPIO41 |
| USB Type-C | ESP32-S3 native USB | USB | Upload, logging | USB_N=GPIO19, USB_P=GPIO20 |
| UART0 | Default serial | UART | Debug / expansion pads | U0TXD=GPIO43, U0RXD=GPIO44 |
| Charge management | ETA6098 | Power | Single-cell Li-battery | PH1.25 / M1.25 battery connector |
| 3.3V LDO | ME6217C33M5G | Power | System 3.3V | VCC3V3 |
| PWR button | Key2 / Power | GPIO / power control | SYS_OUT pulled up, pulled low when pressed; SYS_EN controls battery power hold | SYS_OUT=GPIO40, SYS_EN=GPIO41 |
| BOOT button | Key1 / BOOT | GPIO / download mode | Pulled up to 3.3V, pulled low when pressed | GPIO0 |
| RST button | Key3 / Reset | Reset | Pulled up to 3.3V, pulled low when pressed | CHIP_PU |

## Pinout Definition

When using the GPIO pins reserved on the ESP32-S3-Touch-LCD-1.69 board, pay attention to the wire colors and corresponding functions to avoid burnout of the development board due to wiring habits.

ESP32-S3-Touch-LCD-1.69 Pin Definition

### Extension Port

| Type | Signal |
| --- | --- |
| Power | `5V` / `3V3` / `GND` |
| I2C | `SCL(GPIO10)` / `SDA(GPIO11)` |
| UART | `TX(GPIO43)` / `RX(GPIO44)` |
| GPIO | `GPIO2` / `GPIO3` / `GPIO17` / `GPIO18` |

### Complete GPIO Allocation

| GPIO | Signal Name | Connected To | Notes |
| --- | --- | --- | --- |
| GPIO0 | BOOT / Key1 | BOOT button | Strapping pin; hold while powering on, then release to enter download mode |
| GPIO1 | BAT_ADC | Battery voltage divider | R3 pull-up 200K, R7 pull-down 100K; VBAT=VADC×3 |
| GPIO2 | GPIO2 | Reserved pad / header | Extension port GPIO2 |
| GPIO3 | GPIO3 | Reserved pad / header | Extension port GPIO3 |
| GPIO4 | LCD_DC | ST7789V2 data/command | - |
| GPIO5 | LCD_CS | ST7789V2 chip select | - |
| GPIO6 | LCD_CLK | ST7789V2 SPI clock | - |
| GPIO7 | LCD_DIN | ST7789V2 SPI data | Only connected to the LCD SPI write data line, LCD_DOUT unused |
| GPIO8 | LCD_RST | ST7789V2 reset | - |
| GPIO10 | ESP32_SCL | Touch + IMU + RTC shared I2C SCL; also exposed on extension port | See peripheral table for I2C devices |
| GPIO11 | ESP32_SDA | Touch + IMU + RTC shared I2C SDA; also exposed on extension port | See peripheral table for I2C devices |
| GPIO13 | TP_RST | CST816T touch reset | - |
| GPIO14 | TP_INT | CST816T touch interrupt | - |
| GPIO15 | LCD_BL | LCD backlight control | - |
| GPIO17 | GPIO17 | Reserved pad / header | Extension port GPIO17 |
| GPIO18 | GPIO18 | Reserved pad / header | Extension port GPIO18 |
| GPIO19 | USB_N | USB Type-C D- | ESP32-S3 native USB |
| GPIO20 | USB_P | USB Type-C D+ | ESP32-S3 native USB |
| GPIO38 | QMI_INT2 | QMI8658C INT2 | - |
| GPIO39 | RTC_INT | PCF85063 RTC interrupt | - |
| GPIO40 | SYS_OUT | System power control network | Related to PWR / Key2 power circuit |
| GPIO41 | SYS_EN | System power control network | Related to PWR / Key2 power circuit |
| GPIO42 | Buzz | Onboard buzzer driver | Can be used as PWM / tone output |
| GPIO43 | U0TXD | Reserved UART TX pad / header | Extension port TX |
| GPIO44 | U0RXD | Reserved UART RX pad / header | Extension port RX |

LCD and Touch Pins
| Signal | GPIO | Description |
| --- | --- | --- |
| `LCD_DC` | `GPIO4` | ST7789V2 data/command |
| `LCD_CS` | `GPIO5` | ST7789V2 chip select |
| `LCD_CLK` | `GPIO6` | ST7789V2 SPI clock |
| `LCD_DIN` | `GPIO7` | ST7789V2 SPI data (write only; DOUT is unused) |
| `LCD_RST` | `GPIO8` | ST7789V2 reset |
| `LCD_BL` | `GPIO15` | LCD backlight control |
| `TP_SCL` | `GPIO10` | Touch I2C SCL (shared) |
| `TP_SDA` | `GPIO11` | Touch I2C SDA (shared) |
| `TP_RST` | `GPIO13` | CST816T touch reset |
| `TP_INT` | `GPIO14` | CST816T touch interrupt |

Power and Buttons
| Signal / Button | GPIO / Signal | Description |
| --- | --- | --- |
| `BOOT` / Key1 | `GPIO0` | Download mode strapping pin; hold while powering on, then release |
| `BAT_ADC` | `GPIO1` | Battery voltage divider; `VBAT=VADC×3` |
| `SYS_OUT` | `GPIO40` | System power control network (PWR / Key2 circuit) |
| `SYS_EN` | `GPIO41` | System power hold network (PWR / Key2 circuit) |
| `Buzz` | `GPIO42` | Onboard buzzer; supports PWM / tone output |
| `RST` / Key3 | `CHIP_PU` | Reset signal |

I2C Device Summary
| Device | Model | I2C Address | I2C Pins | Additional Interrupt / Control |
| --- | --- | --- | --- | --- |
| Touch | CST816T | `0x15` | `GPIO10` / `GPIO11` | `TP_INT=GPIO14` , `TP_RST=GPIO13` |
| IMU | QMI8658C | `0x6B` | `GPIO10` / `GPIO11` | `QMI_INT1=GPIO38` |
| RTC | PCF85063ATL | `0x51` | `GPIO10` / `GPIO11` | `RTC_INT=GPIO39` |

### Usage Notes

- When connecting external I2C devices, avoid address conflicts with `0x15` , `0x6B` , and `0x51` .
- `GPIO19/GPIO20` are connected to USB Type-C and are not recommended for general GPIO use.
- `GPIO0` is the BOOT pin and `CHIP_PU` is the reset signal; not recommended as general user inputs.

## Dimensions

ESP32-S3-Touch-LCD-1.69 Product Dimensions

## Development Methods

The ESP32-S3-Touch-LCD-1.69 supports two development frameworks: Arduino IDE and ESP-IDF, providing flexibility for developers to choose the tool that best fits their project requirements and personal preference.

Arduino generally offers a gentler learning curve and may be more approachable for beginners and hobbyists. ESP-IDF provides advanced tooling and finer control over system behavior, making it better suited to complex projects and applications with demanding performance requirements.

- **Arduino IDE** is a convenient, flexible, and easy-to-use open-source electronics prototyping platform. It requires minimal foundational knowledge, allowing for rapid development after a short learning period. Arduino has a huge global user community, providing a vast amount of open-source code, project examples, and tutorials, as well as a rich library ecosystem that encapsulates complex functions, enabling developers to implement various features rapidly. You can refer to the **[Working with Arduino](https://docs.waveshare.com/ESP32-S3-Touch-LCD-1.69/Arduino)** to complete the initial setup, and the tutorial also provides related examples for reference.
- **ESP-IDF** , short for Espressif IoT Development Framework, is a professional development framework launched by Espressif Systems for its ESP series of chips. It is based on C language development and includes compilers, debuggers, flashing tools, etc. It supports development via command line or integrated development environments (such as Visual Studio Code with the Espressif IDF plugin), which provides features like code navigation, project management, and debugging. We recommend using VS Code for development. For the specific configuration process, please refer to the **[Working with ESP-IDF](https://docs.waveshare.com/ESP32-S3-Touch-LCD-1.69/ESP-IDF)** . The tutorial also provides relevant examples for reference.

[Give Feedback](https://docs.google.com/forms/d/e/1FAIpQLSfayJEZ5J-dp-3Wq_dkWsVRhNuQ6C79_GNV62mYuFW8Mj6U8Q/viewform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)

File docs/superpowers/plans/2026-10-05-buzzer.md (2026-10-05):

# Buzzer Implementation Plan

> **For agentic workers:** REQUIRED SUB-SKILL: Use superpowers:subagent-driven-development (recommended) or superpowers:executing-plans to implement this plan task-by-task. Steps use checkbox (`- [ ]`) syntax for tracking.

**Goal:** The cube's passive buzzer plays a short tune when a Pomodoro phase ends. Its level (OFF / LOW / MED / HIGH) can be set on the cube, from the Mac and in the portal. The buzzer pin is held LOW from the first line of `setup()`.

**Architecture:** A pure, host-tested sequencer (`melody.h`: tune tables plus `MelodyPlayer`) decides which pitch should sound at `now`. A thin hardware layer (`buzzer.cpp`) turns that pitch into LEDC writes on channel 0, with a log-only simulator stand-in and a silent bench stand-in. The level is a fifth `DeviceSettings` field, `sound`, carried everywhere the other display knobs already go: NVS, portal, BLE Settings JSON, the Mac's settings window, and the on-device panel, where SOUND replaces REFRESH.

**Tech Stack:** C++ (board: Arduino-ESP32 2.0.17, `-std=gnu++11`; host tests: C++17 with `tests/check.h`), LovyanGFX, ArduinoJson. Swift 6 tools / Swift 5 mode for the Mac helper (Swift Testing). No new dependencies.

**Spec:** `docs/superpowers/specs/2026-10-05-buzzer-design.md`

## Global Constraints

- Board code compiles as gnu++11. Every `constexpr` function is a single `return`. No C++14/17 features in `src/`.
- Pure headers make no Arduino calls and never read `millis()`. The caller passes `now`, and elapsed time uses unsigned subtraction.
- LEDC channel 0 (timer 0) only. Never channel 6 or 7: those share timer 3 with the backlight. No `tone()`.
- `sound` is 0..3: 0 = off, 1 = LOW, 2 = MED, 3 = HIGH. The default is `BUZZER_LEVEL` = 2 (MED). The NVS key and the BLE JSON key are both `sd`. `BLE_FW_REV` goes from 3 to 4.
- Local-only: no payload field, nothing in `preview.html` or the Mac menu bar.
- Firmware text stays printable ASCII (the generated fonts cover 0x20-0x7E only).
- Every hardware layer has a `sim/*_sim.cpp` stand-in and a stand-in in `sim/bench.cpp`.
- Shared app code (`main.cpp`) uses only what `sim/Arduino.h` provides.
- Commit messages end with `Co-Authored-By: Claude Opus 5.5 <noreply@anthropic.com>`.

## Review Focus

These are listed most likely first. Each line names the step that pins it.

1. **Upgrade from older firmware with nothing stored under `sd`.** The cube must come up at MED, not silent. Pinned by Task 2 Step 6 (`loadU8(p, "sd", DEVICE_DEFAULTS.sound)`, checked by grep) and the Task 7 acceptance item.
2. **A positional `DeviceSettings{...}` initializer left at four values.** It still compiles, and silently stores sound = 0. Pinned by Task 2 Step 8 (a grep of every initializer) and Task 3 Step 5 (a rebuild of every test with no `missing-field-initializers` warning).
3. **Mixed versions.**
   - An older Mac writing to a new cube omits `sd`, and the level must stay unchanged: Task 4 `testSound`.
   - A new Mac reading an older cube gets no `sd`: `sound == nil`, the row is hidden and `sd` is never sent. Task 5 `soundExistsOnlyWhenTheCubeReportsIt`.
4. **Sound turned off while a tune plays, or switched off in the panel.** It must be silent at once, with no preview beep.
   - Task 1 `testStop`.
   - Task 6: `buzzerSetLevel(0)` stops the player, and `buzzerPlay` is a no-op at level 0.
   - Task 3 `testSound`: toggling off gives 0, so `main.cpp` plays nothing.
5. **A play made after this pass read `now`, a late pass, or a `millis()` wrap.**
   - A play made after `now` was read is the editor preview, called from `pollTouch`.
   - In all three cases the tune must keep its full length and note order.
   - Pinned by Task 1 `testTimingStartsAtFirstUpdate`, `testLatePassSkipsAhead` and `checkWholeTune` from just before the wrap.

---

### Task 1: Melody sequencer (`melody.h`)

**Files:**
- Create: `firmware/src/melody.h`
- Create: `firmware/sim/tests/melody_test.cpp`
- Modify: `firmware/sim/Makefile` (`TESTS`)

**Interfaces:**
- Produces (all in `melody.h`):
  - `struct Note { uint16_t hz; uint16_t ms; }`, where `hz == 0` is a rest.
  - `enum class Sound : uint8_t { FocusDone, BreakDone, Attention, Preview }`.
  - The tune tables `MELODY_FOCUS_DONE`, `MELODY_BREAK_DONE`, `MELODY_ATTENTION` and `MELODY_PREVIEW` (`constexpr Note[]`).
  - `const Note *melodyFor(Sound s, uint8_t &len)`.
  - `const char *melodyName(Sound s)`, which returns `"focus-done"`, `"break-done"`, `"attention"` or `"preview"`.
  - `class MelodyPlayer`:
    - `void play(Sound)` replaces whatever is playing. Timing starts at the next `update()`.
    - `void stop()`.
    - `bool playing() const`.
    - `uint16_t update(uint32_t now)` returns the pitch for `now`, or 0 for silence.

- [ ] **Step 1: Commit the spec and this plan**

The branch `feat/buzzer` already exists and is checked out.

```bash
cd /Users/kpmquockhanh/code/claude-status-cube
git add docs/superpowers/specs/2026-10-05-buzzer-design.md docs/superpowers/plans/2026-10-05-buzzer.md
git commit -m "docs: buzzer design and implementation plan

Co-Authored-By: Claude Opus 5.5 <noreply@anthropic.com>"
```

- [ ] **Step 2: Write the failing test**

Create `firmware/sim/tests/melody_test.cpp`:

```cpp
#include <cstring>

#include "check.h"
#include "melody.h"

namespace {

const Sound ALL[] = {Sound::FocusDone, Sound::BreakDone, Sound::Attention, Sound::Preview};

// Plays `s` from t0, checking the first and the last millisecond of every note,
// then that it ends exactly when its notes add up to.
void checkWholeTune(Sound s, uint32_t t0) {
  uint8_t n = 0;
  const Note *tune = melodyFor(s, n);
  MelodyPlayer p;
  p.play(s);
  uint32_t t = t0;
  for (uint8_t i = 0; i < n; i++) {
    CHECK(p.update(t) == tune[i].hz);
    CHECK(p.update(t + tune[i].ms - 1) == tune[i].hz);
    CHECK(p.playing());
    t += tune[i].ms;
  }
  CHECK(p.update(t) == 0);
  CHECK(!p.playing());
  CHECK(p.update(t + 1000) == 0);
}

void testWholeTunes() {
  for (Sound s : ALL) {
    checkWholeTune(s, 1000);
    checkWholeTune(s, 0xFFFFFFFFu - 50);  // millis() wraps mid-tune
  }
}

void testIdle() {
  MelodyPlayer p;
  CHECK(!p.playing());
  CHECK(p.update(0) == 0);
  CHECK(p.update(123456) == 0);
}

// A rest is silence, but the tune is still playing.
void testRest() {
  CHECK(MELODY_ATTENTION[1].hz == 0);
  MelodyPlayer p;
  p.play(Sound::Attention);
  CHECK(p.update(0) == MELODY_ATTENTION[0].hz);
  const uint32_t rest = MELODY_ATTENTION[0].ms;
  CHECK(p.update(rest) == 0 && p.playing());
  CHECK(p.update(rest + MELODY_ATTENTION[1].ms) == MELODY_ATTENTION[2].hz);
}

// The editor's preview is requested from pollTouch(), after this pass read
// `now`. The tune must start at the next update, whatever its `now`, and play
// whole.
void testTimingStartsAtFirstUpdate() {
  MelodyPlayer p;
  p.play(Sound::Preview);
  CHECK(p.playing());
  CHECK(p.update(50000) == MELODY_PREVIEW[0].hz);
  CHECK(p.update(50000 + MELODY_PREVIEW[0].ms - 1) == MELODY_PREVIEW[0].hz);
  CHECK(p.update(50000 + MELODY_PREVIEW[0].ms) == 0);
}

// One long pass misses a whole note: the player skips it, and the tune still
// ends on time instead of running late.
void testLatePassSkipsAhead() {
  MelodyPlayer p;
  p.play(Sound::FocusDone);
  CHECK(p.update(0) == MELODY_FOCUS_DONE[0].hz);
  const uint32_t third = MELODY_FOCUS_DONE[0].ms + MELODY_FOCUS_DONE[1].ms;
  CHECK(p.update(third + 5) == MELODY_FOCUS_DONE[2].hz);
  CHECK(p.update(third + MELODY_FOCUS_DONE[2].ms) == 0 && !p.playing());
}

void testPlayReplaces() {
  MelodyPlayer p;
  p.play(Sound::FocusDone);
  p.update(0);
  CHECK(p.update(MELODY_FOCUS_DONE[0].ms) == MELODY_FOCUS_DONE[1].hz);  // mid-tune
  const uint32_t t = MELODY_FOCUS_DONE[0].ms + 10;
  p.play(Sound::Preview);
  CHECK(p.update(t) == MELODY_PREVIEW[0].hz);
  CHECK(p.update(t + MELODY_PREVIEW[0].ms) == 0 && !p.playing());
}

void testStop() {
  MelodyPlayer p;
  p.play(Sound::BreakDone);
  CHECK(p.update(0) != 0);
  p.stop();
  CHECK(!p.playing() && p.update(1) == 0);
  p.play(Sound::BreakDone);  // stopped before it ever sounded
  p.stop();
  CHECK(!p.playing() && p.update(2) == 0);
  p.stop();  // stopping nothing is fine
  CHECK(!p.playing());
}

bool sameTune(Sound a, Sound b) {
  uint8_t na = 0, nb = 0;
  const Note *ta = melodyFor(a, na);
  const Note *tb = melodyFor(b, nb);
  if (na != nb) return false;
  for (uint8_t i = 0; i < na; i++)
    if (ta[i].hz != tb[i].hz || ta[i].ms != tb[i].ms) return false;
  return true;
}

void testTables() {
  for (Sound s : ALL) {
    uint8_t n = 0;
    const Note *tune = melodyFor(s, n);
    CHECK(tune != nullptr && n > 0);
    if (!tune || !n) continue;
    uint32_t total = 0;
    for (uint8_t i = 0; i < n; i++) {
      CHECK(tune[i].ms >= 60);  // the loop times notes to about one 16 ms pass
      total += tune[i].ms;
    }
    CHECK(total < 500);
    CHECK(tune[0].hz != 0 && tune[n - 1].hz != 0);  // no dead air at either end
  }
  CHECK(!sameTune(Sound::FocusDone, Sound::BreakDone));  // you can tell break from work by ear
  CHECK(!strcmp(melodyName(Sound::FocusDone), "focus-done"));
  CHECK(!strcmp(melodyName(Sound::BreakDone), "break-done"));
  CHECK(!strcmp(melodyName(Sound::Attention), "attention"));
  CHECK(!strcmp(melodyName(Sound::Preview), "preview"));
}

}  // namespace

int main() {
  testWholeTunes();
  testIdle();
  testRest();
  testTimingStartsAtFirstUpdate();
  testLatePassSkipsAhead();
  testPlayReplaces();
  testStop();
  testTables();
  return checksDone("melody_test");
}
```

In `firmware/sim/Makefile`, add `build/melody_test` to the end of `TESTS`. `melody.h` is header-only, so no extra rule is needed. Change:

```make
         build/ble_conn_test build/touch_gate_test
```

to:

```make
         build/ble_conn_test build/touch_gate_test build/melody_test
```

- [ ] **Step 3: Run the test to verify that it fails**

Run: `cd /Users/kpmquockhanh/code/claude-status-cube/firmware/sim && make build/melody_test`

Expected: the compile fails with `fatal error: 'melody.h' file not found`.

- [ ] **Step 4: Write `melody.h`**

Create `firmware/src/melody.h`:

```cpp
#pragma once
#include <stddef.h>
#include <stdint.h>

// The buzzer's tunes and the sequencer that plays them, minus the hardware:
// MelodyPlayer::update() says which pitch should sound now, and buzzer.cpp
// drives the pin. Pure: no Arduino. The caller passes `now`; elapsed time is
// unsigned subtraction, so a millis() wrap mid-tune is harmless.

struct Note {
  uint16_t hz;  // 0 = rest
  uint16_t ms;
};

enum class Sound : uint8_t {
  FocusDone,  // a focus phase ended: break time
  BreakDone,  // a short or long break ended: back to work
  Attention,  // Claude Code is waiting for you (played from sub-project B)
  Preview,    // the SOUND level changed in the display panel
};

// Starting pitches, tuned by ear on the board. Every note is >= 60 ms, because
// the loop times notes to about one pass (15-16 ms), and every tune is under
// 0.5 s.
constexpr Note MELODY_FOCUS_DONE[] = {{2093, 110}, {2637, 110}, {3136, 110}};  // rising
constexpr Note MELODY_BREAK_DONE[] = {{2637, 100}, {2349, 100}, {3136, 220}};  // ends high, held
constexpr Note MELODY_ATTENTION[] = {{2700, 70}, {0, 70}, {2700, 70}};        // near the loudest pitch
constexpr Note MELODY_PREVIEW[] = {{2700, 90}};

template <size_t N>
inline const Note *melodyOf(const Note (&tune)[N], uint8_t &len) {
  len = (uint8_t)N;
  return tune;
}

inline const Note *melodyFor(Sound s, uint8_t &len) {
  switch (s) {
    case Sound::FocusDone: return melodyOf(MELODY_FOCUS_DONE, len);
    case Sound::BreakDone: return melodyOf(MELODY_BREAK_DONE, len);
    case Sound::Attention: return melodyOf(MELODY_ATTENTION, len);
    case Sound::Preview: return melodyOf(MELODY_PREVIEW, len);
  }
  len = 0;
  return nullptr;
}

// For the [buzz] log line.
inline const char *melodyName(Sound s) {
  switch (s) {
    case Sound::FocusDone: return "focus-done";
    case Sound::BreakDone: return "break-done";
    case Sound::Attention: return "attention";
    case Sound::Preview: return "preview";
  }
  return "?";
}

class MelodyPlayer {
 public:
  // Replaces whatever is playing. Timing starts at the next update(): a
  // play() made after this pass read `now` (the editor's preview) must not
  // lose its first note.
  void play(Sound s) {
    notes_ = melodyFor(s, len_);
    if (!len_) notes_ = nullptr;
    idx_ = 0;
    armed_ = notes_ != nullptr;
  }

  void stop() {
    notes_ = nullptr;
    armed_ = false;
  }

  bool playing() const { return notes_ != nullptr; }

  // The pitch to output at `now`, or 0 for silence (a rest, or nothing
  // playing). A late call skips the notes it missed, so a tune keeps its
  // length.
  uint16_t update(uint32_t now) {
    if (armed_) {
      noteStart_ = now;
      armed_ = false;
    }
    while (notes_) {
      if (now - noteStart_ < notes_[idx_].ms) return notes_[idx_].hz;
      noteStart_ += notes_[idx_].ms;
      if (++idx_ >= len_) notes_ = nullptr;
    }
    return 0;
  }

 private:
  const Note *notes_ = nullptr;
  uint8_t len_ = 0;
  uint8_t idx_ = 0;
  bool armed_ = false;
  uint32_t noteStart_ = 0;
};
```

- [ ] **Step 5: Run the test to verify that it passes**

Run: `cd /Users/kpmquockhanh/code/claude-status-cube/firmware/sim && make build/melody_test && ./build/melody_test`

Expected: `melody_test: N checks, 0 failed`, with no compiler warnings.

- [ ] **Step 6: Commit**

```bash
cd /Users/kpmquockhanh/code/claude-status-cube
git add firmware/src/melody.h firmware/sim/tests/melody_test.cpp firmware/sim/Makefile
git commit -m "feat(firmware): melody sequencer for the buzzer

Co-Authored-By: Claude Opus 5.5 <noreply@anthropic.com>"
```

`melody.h` is first compiled for the board in Task 6, when `buzzer.cpp` includes it. That task's `pio run` catches any gnu++11 problem.

---

### Task 2: The `sound` setting (struct, defaults, NVS, portal)

**Files:**
- Modify:
  - `firmware/src/device_settings.h`
  - `firmware/src/device_defaults.h`
  - `firmware/src/config.h.example`
  - `firmware/src/settings.cpp:61-64, 112-115`
  - `firmware/src/portal.cpp:68-74, 145-167`
  - `firmware/sim/tests/settings_fake.cpp:6`
  - `firmware/sim/shot.cpp:178`
- Test: `firmware/sim/tests/device_settings_test.cpp`

**Interfaces:**
- Produces (in `device_settings.h`):
  - `DeviceSettings::sound` (`uint8_t`, 0..3), the fifth and last field. It is part of `operator==`.
  - `constexpr int DEV_MAX_SOUND = 3`.
  - `inline const char *devSoundName(uint8_t level)`, which returns `"OFF"`, `"LOW"`, `"MED"` or `"HIGH"`.
  - `DEVICE_DEFAULTS.sound` = `BUZZER_LEVEL` (default 2).
- Every `DeviceSettings{...}` brace initializer has five values.

- [ ] **Step 1: Write the failing test**

Replace `firmware/sim/tests/device_settings_test.cpp` with:

```cpp
#include <cstring>

#include "check.h"
#include "device_settings.h"

int main() {
  DeviceSettings s = deviceClamp({0, 255, 255, 0, 9});
  CHECK(s.backlight == DEV_MIN_BACKLIGHT);
  CHECK(s.sleepMin == DEV_MAX_SLEEP_MIN);
  CHECK(s.rotateSec == 255);
  CHECK(s.pollSec == DEV_MIN_POLL_SEC);
  CHECK(s.sound == DEV_MAX_SOUND);
  s = deviceClamp({160, 0, 0, 200, 0});
  CHECK(s.backlight == 160 && s.sleepMin == 0 && s.rotateSec == 0 && s.pollSec == DEV_MAX_POLL_SEC &&
        s.sound == 0);
  // == sees the level too: a change made only to it must still be saved
  // (closeDeviceEditor and settings_json compare with it).
  const DeviceSettings a{160, 15, 0, 5, 2};
  DeviceSettings b = a;
  CHECK(a == b);
  b.sound = 3;
  CHECK(a != b);
  CHECK(!strcmp(devSoundName(0), "OFF") && !strcmp(devSoundName(1), "LOW"));
  CHECK(!strcmp(devSoundName(2), "MED") && !strcmp(devSoundName(3), "HIGH"));
  // config.h gives milliseconds; the settings store whole minutes / seconds. A
  // short non-zero value must not round down to 0, which means never / off.
  CHECK(devMsToUnits(0, 60000) == 0);
  CHECK(devMsToUnits(30000, 60000) == 1);
  CHECK(devMsToUnits(60000, 60000) == 1);
  CHECK(devMsToUnits(60001, 60000) == 2);
  CHECK(devMsToUnits(900000, 60000) == 15);
  CHECK(devMsToUnits(500, 1000) == 1);
  CHECK(devMsToUnits(5000, 1000) == 5);
  return checksDone("device_settings_test");
}
```

- [ ] **Step 2: Run the test to verify that it fails**

Run: `cd /Users/kpmquockhanh/code/claude-status-cube/firmware/sim && make build/device_settings_test`

Expected: the compile fails. The errors name `sound` (`no member named 'sound'`), `DEV_MAX_SOUND`, `devSoundName` and an excess-initializer error.

- [ ] **Step 3: Add the field to `device_settings.h`**

In `firmware/src/device_settings.h`, change the struct and `operator==`:

```cpp
struct DeviceSettings {
  uint8_t backlight;    // 10..255 (0 would look like a dead cube)
  uint8_t sleepMin;     // screen-off after this many idle minutes; 0 = never
  uint8_t rotateSec;    // auto-advance the deck every N seconds; 0 = off
  uint8_t pollSec;      // WiFi poll interval in seconds
  uint8_t sound;        // buzzer: 0 = off, 1..3 = LOW / MED / HIGH
};

inline bool operator==(const DeviceSettings &a, const DeviceSettings &b) {
  return a.backlight == b.backlight && a.sleepMin == b.sleepMin && a.rotateSec == b.rotateSec &&
         a.pollSec == b.pollSec && a.sound == b.sound;
}
```

After `constexpr int DEV_MAX_POLL_SEC = 60;`, add:

```cpp
constexpr int DEV_MAX_SOUND = 3;

// The buzzer level as the display panel and the [buzz] log show it.
inline const char *devSoundName(uint8_t level) {
  return level == 0 ? "OFF" : level == 1 ? "LOW" : level == 2 ? "MED" : "HIGH";
}
```

In `deviceClamp`, after the `pollSec` line, add:

```cpp
  s.sound = devClampU8(s.sound, 0, DEV_MAX_SOUND);
```

- [ ] **Step 4: Run the test to verify that it passes**

Run: `cd /Users/kpmquockhanh/code/claude-status-cube/firmware/sim && make build/device_settings_test && ./build/device_settings_test`

Expected: `device_settings_test: N checks, 0 failed`.

- [ ] **Step 5: Add the default and document it**

In `firmware/src/device_defaults.h`, after the `SCREEN_SLEEP_MS` fallback block, add:

```cpp
#ifndef BUZZER_LEVEL
#define BUZZER_LEVEL 2  // older config.h files: MED
#endif
```

Then give `DEVICE_DEFAULTS` its fifth value:

```cpp
constexpr DeviceSettings DEVICE_DEFAULTS{
    devClampU8(BACKLIGHT, DEV_MIN_BACKLIGHT, DEV_MAX_BACKLIGHT),
    devClampU8(devMsToUnits(SCREEN_SLEEP_MS, 60000), 0, DEV_MAX_SLEEP_MIN),
    devClampU8(devMsToUnits(CARD_ROTATE_MS, 1000), 0, DEV_MAX_ROTATE_SEC),
    devClampU8(devMsToUnits(POLL_INTERVAL_MS, 1000), DEV_MIN_POLL_SEC, DEV_MAX_POLL_SEC),
    devClampU8(BUZZER_LEVEL, 0, DEV_MAX_SOUND)};
```

In `firmware/src/config.h.example`, after the `SCREEN_SLEEP_MS` line, add:

```cpp
#define BUZZER_LEVEL         2   // buzzer: 0 off, 1 low, 2 medium, 3 high
```

Leave the user's own gitignored `src/config.h` alone. The fallback covers it.

- [ ] **Step 6: Store it in NVS**

In `firmware/src/settings.cpp`, in `settingsLoad()`, give the `DeviceSettings` its fifth value. A cube that never stored `sd` gets the default, MED:

```cpp
  g_dev = deviceClamp(DeviceSettings{loadU8(p, "bl", DEVICE_DEFAULTS.backlight),
                                     loadU8(p, "sl", DEVICE_DEFAULTS.sleepMin),
                                     loadU8(p, "rt", DEVICE_DEFAULTS.rotateSec),
                                     loadU8(p, "pi", DEVICE_DEFAULTS.pollSec),
                                     loadU8(p, "sd", DEVICE_DEFAULTS.sound)});
```

In `deviceSettingsSave`, after `p.putUChar("pi", g_dev.pollSec);`, add:

```cpp
  p.putUChar("sd", g_dev.sound);
```

`firmware/sim/settings_sim.cpp` has no NVS. It copies `DEVICE_DEFAULTS` whole, so it needs no change.

Check the fallback:

```bash
grep -n '"sd"' /Users/kpmquockhanh/code/claude-status-cube/firmware/src/settings.cpp
```

Expected: two lines. One is `loadU8(p, "sd", DEVICE_DEFAULTS.sound)` and the other is `p.putUChar("sd", g_dev.sound)`.

- [ ] **Step 7: Add it to the setup portal**

In `firmware/src/portal.cpp`, in the form, after the `numField("WiFi refresh (seconds)", ...)` statement (it spans two lines), add:

```cpp
  h += numField("Sound", "sd", d.sound, 0, DEV_MAX_SOUND, "0 = off, 1 = low, 2 = medium, 3 = high");
```

In the save handler, change the declaration:

```cpp
  int bl, sl, rt, pi, pf, pshort, pl, pn;
```

to:

```cpp
  int bl, sl, rt, pi, sd, pf, pshort, pl, pn;
```

After the `pi` check (`return sendForm(400, "WiFi refresh must be 2 to 60 seconds.");`), add:

```cpp
  if (!portalParseInt(server.arg("sd").c_str(), 0, DEV_MAX_SOUND, dc.sound, sd))
    return sendForm(400, "Sound must be 0 (off) to 3 (high).");
```

Then change the save:

```cpp
      !deviceSettingsSave(DeviceSettings{(uint8_t)bl, (uint8_t)sl, (uint8_t)rt, (uint8_t)pi}) ||
```

to:

```cpp
      !deviceSettingsSave(DeviceSettings{(uint8_t)bl, (uint8_t)sl, (uint8_t)rt, (uint8_t)pi, (uint8_t)sd}) ||
```

A blank field keeps the current value. That is `portalParseInt`'s `keep` argument, as for every other field.

- [ ] **Step 8: Give every other initializer its fifth value, then grep for strays**

In `firmware/sim/tests/settings_fake.cpp`:

```cpp
constexpr DeviceSettings DEV0 = {200, 15, 0, 5, 2};
```

In `firmware/sim/shot.cpp`:

```cpp
    uiDeviceEditor(lcd, DeviceSettings{160, 15, 0, 5, 2});
```

`firmware/sim/tests/dev_editor_test.cpp` is rewritten in Task 3. Until then it builds with `missing-field-initializers` warnings and still passes.

Then list every positional initializer outside that test:

```bash
cd /Users/kpmquockhanh/code/claude-status-cube/firmware
grep -rn -E "DeviceSettings ?\{|deviceClamp\(\{|DeviceSettings [A-Z0-9_]+ ?= ?\{" src sim | grep -v "sim/tests/dev_editor_test"
sed -n '/DEVICE_DEFAULTS{/,/};/p' src/device_defaults.h
```

Expected: every hit has five values:
- `portal.cpp`
- `settings.cpp`, whose `DeviceSettings{loadU8(...` initializer spans five lines; read it.
- `settings_fake.cpp`
- `shot.cpp`
- `device_settings_test.cpp`
- `DEVICE_DEFAULTS`, printed by the `sed`, which ends in `BUZZER_LEVEL`.

The `struct DeviceSettings {` line in `device_settings.h` is the definition, not an initializer. Fix any initializer that still has four values.

- [ ] **Step 9: Build everything that compiles these files**

Run:

```bash
cd /Users/kpmquockhanh/code/claude-status-cube/firmware/sim && make test && make build/cube-shot
cd /Users/kpmquockhanh/code/claude-status-cube/firmware && pio run
```

Expected:
- `make test`: every test prints `0 failed`. `dev_editor_test` may print `missing-field-initializers` warnings while it compiles; that is expected until Task 3.
- `build/cube-shot` builds.
- `pio run` ends in `SUCCESS`. `portal.cpp` and `settings.cpp` are compiled only here.

- [ ] **Step 10: Commit**

```bash
cd /Users/kpmquockhanh/code/claude-status-cube
git add firmware/src/device_settings.h firmware/src/device_defaults.h firmware/src/config.h.example \
        firmware/src/settings.cpp firmware/src/portal.cpp firmware/sim/tests/device_settings_test.cpp \
        firmware/sim/tests/settings_fake.cpp firmware/sim/shot.cpp
git commit -m "feat(firmware): sound level setting (NVS sd, portal field)

Co-Authored-By: Claude Opus 5.5 <noreply@anthropic.com>"
```

---
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

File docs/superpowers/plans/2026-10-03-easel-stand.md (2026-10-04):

# Easel Stand Implementation Plan

> **For agentic workers:** REQUIRED SUB-SKILL: Use superpowers:subagent-driven-development (recommended) or superpowers:executing-plans to implement this plan task-by-task. Steps use checkbox (`- [ ]`) syntax for tracking.

**Goal:** Add the easel desk stand (concept A) next to the wedge: a tray for the cell, a frame lid with a fin, a carrier that holds the board at 65° and a bezel that hooks on at the bottom, with both stands sharing one copy of the board facts.
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

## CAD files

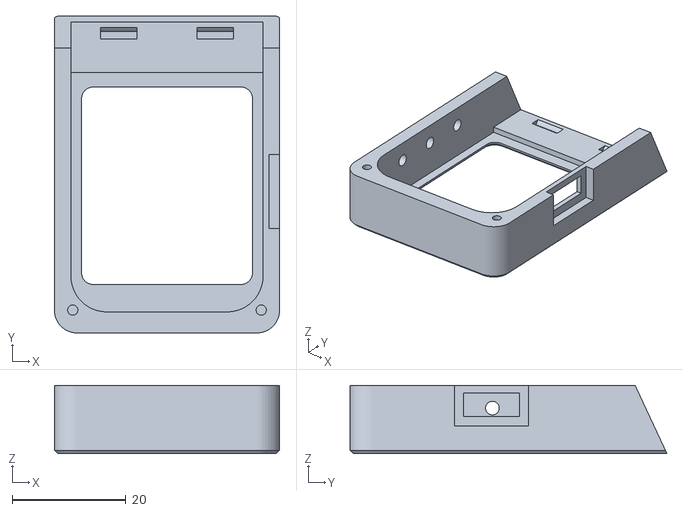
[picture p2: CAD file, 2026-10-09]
3d-printing/easel-bezel.stl
39.5 x 55.6 x 12.0

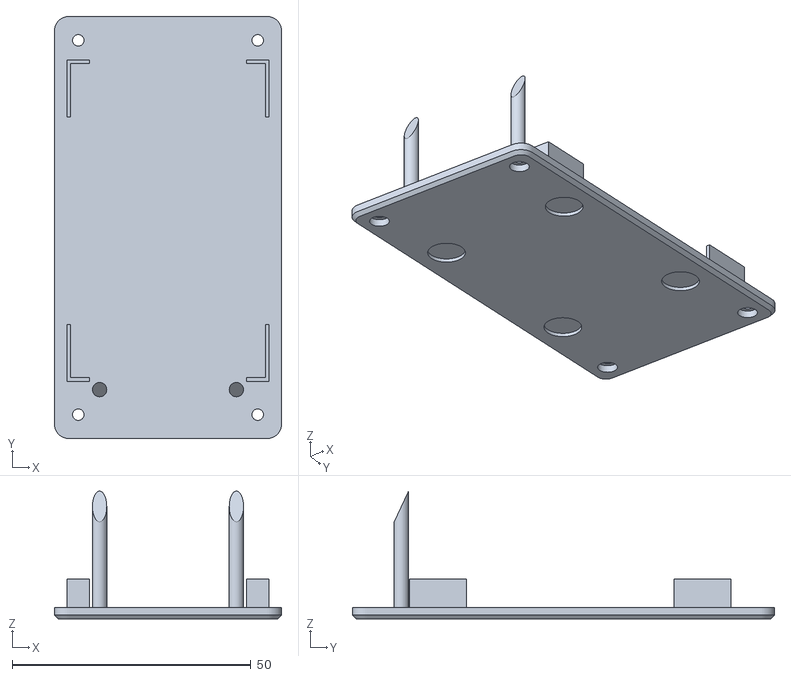
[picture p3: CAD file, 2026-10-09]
3d-printing/stand-base.stl
47.6 x 88.4 x 26.8

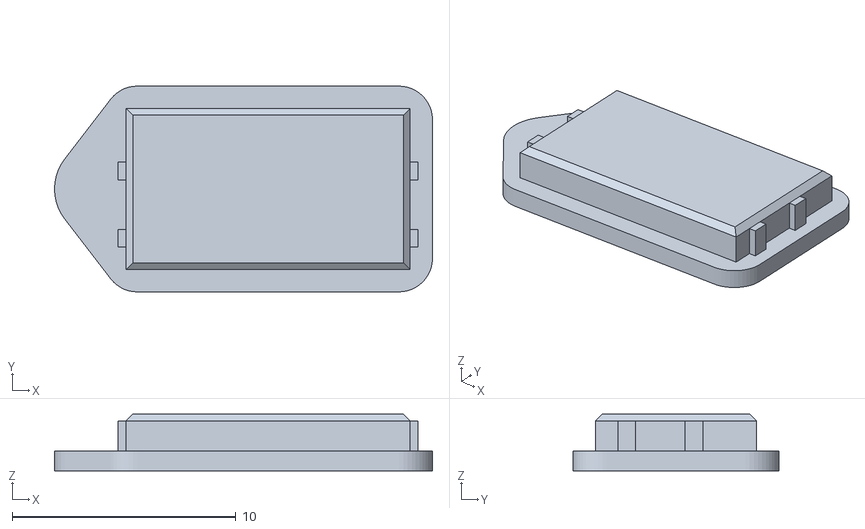
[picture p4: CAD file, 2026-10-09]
3d-printing/easel-usb-cap.stl
16.9 x 9.20 x 2.54

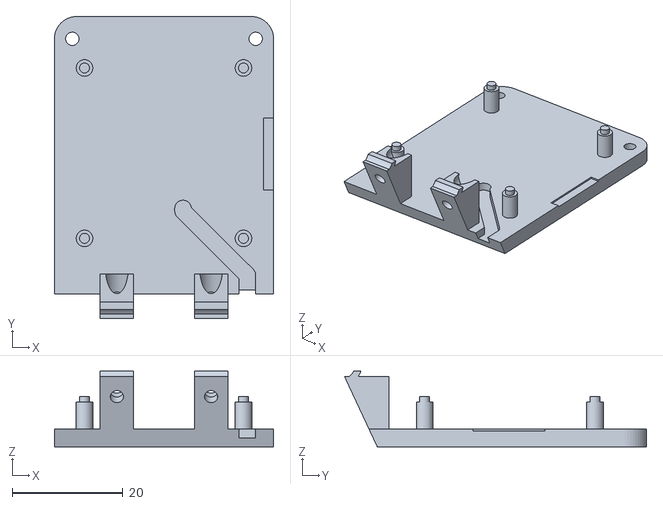
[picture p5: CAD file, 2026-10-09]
3d-printing/easel-carrier.stl
39.5 x 54.5 x 13.7

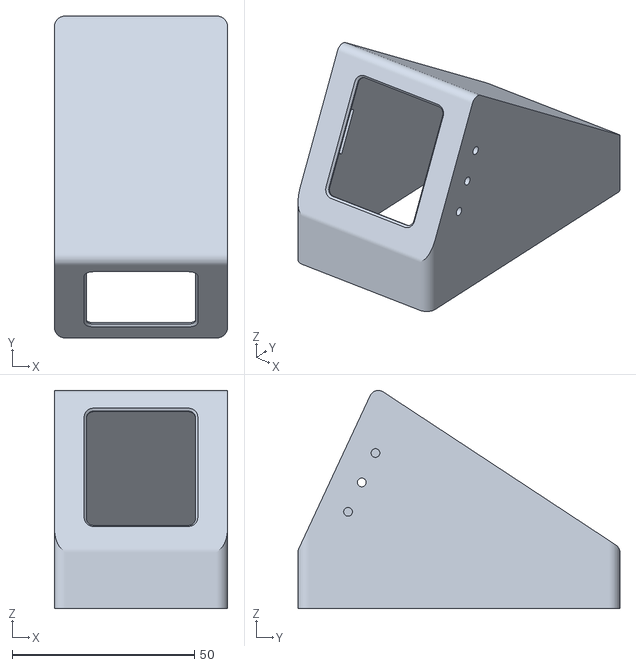
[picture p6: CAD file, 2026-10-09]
3d-printing/stand-front.stl
47.6 x 88.4 x 59.9

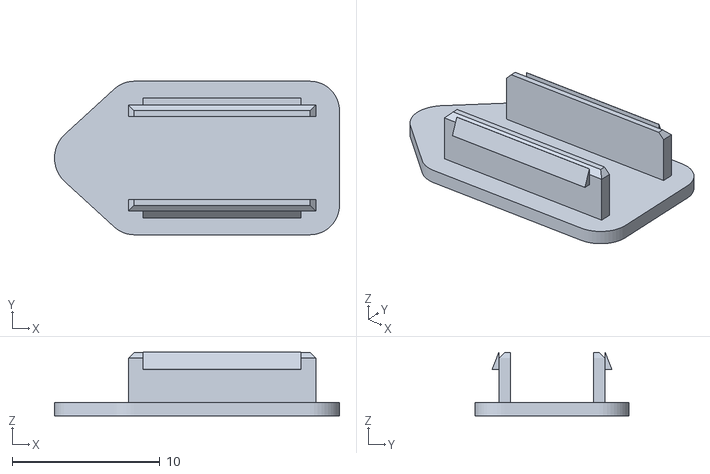
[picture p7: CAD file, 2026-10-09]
3d-printing/usb-cap.stl
19.3 x 10.4 x 4.31

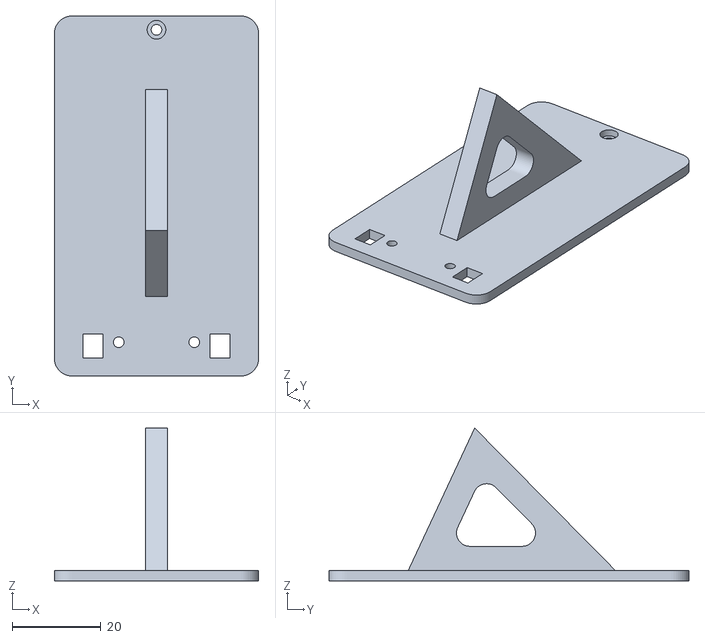
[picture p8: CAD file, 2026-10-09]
3d-printing/easel-frame.stl
46.0 x 81.0 x 34.4

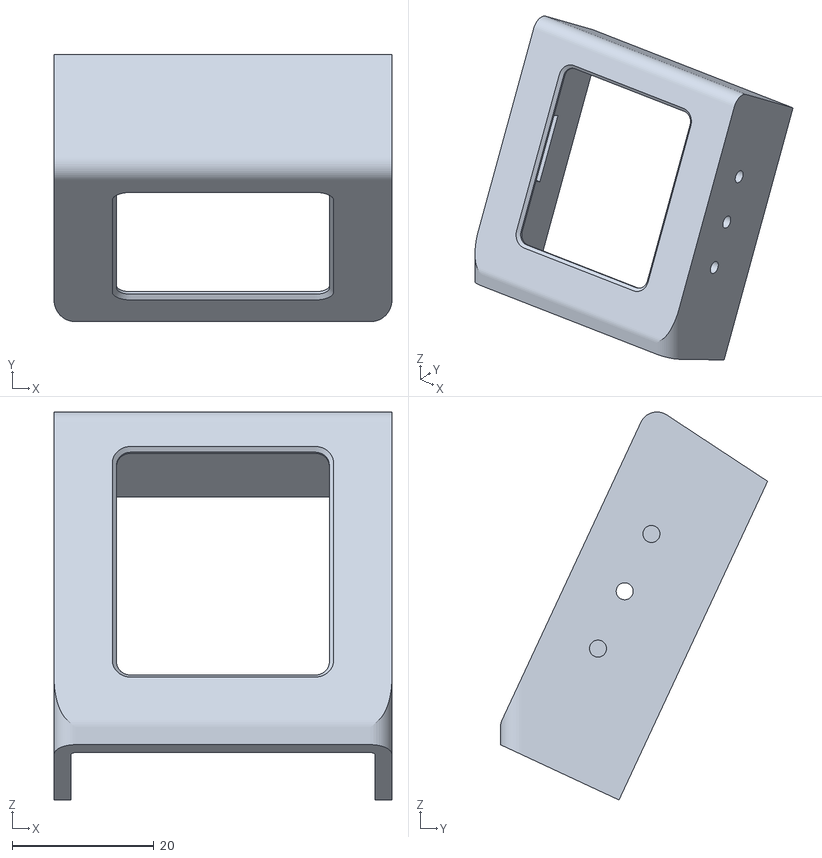
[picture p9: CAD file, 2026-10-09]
3d-printing/fit-check.stl
47.6 x 37.6 x 54.7

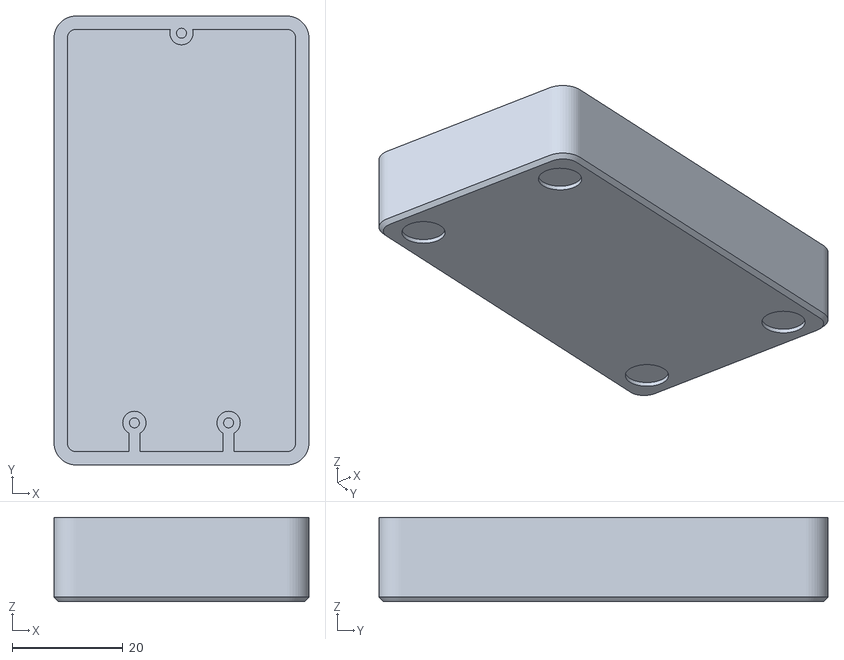
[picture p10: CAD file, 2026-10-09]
3d-printing/easel-tray.stl
46.0 x 81.0 x 15.2

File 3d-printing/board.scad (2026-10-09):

// board.scad: the Waveshare ESP32-S3-Touch-LCD-1.69 as both stands see it. Units: mm.
// Board facts, fit tunables and board-local helpers. No geometry and no $fn here: `include` it right
// after `$fn = 48;`. The includer defines `O` (board origin in world coordinates), `lean` (screen
// lean from vertical) and `board_flip`; the frame helpers read them when called. Assign no variable here
// and there too.

// ---- fit tunables -------------------------------------------------------------
lip_t = 1.0;                // material in front of the glass
clr = 0.3;                  // glass pocket clearance, per side
win_cham = 0.6;      // 45 deg break around the window, where a finger meets the screen edge

// Board, from the Waveshare drawing, corrected from Waveshare's STEP model (ESP32-S3-Touch-LCD-1_69.stp).
// Drawing coords: a = from its left edge, b = from its top edge.
// In the firmware's portrait view: portrait x = b, portrait z = a.
glass_a = 41.13;  glass_b = 33.13;  glass_r = 6;               // STEP: corners r ~6.4 and slightly bowed ends; 6 keeps the pocket outside
act_a0 = 2.97;  act_b0 = 2.585;  act_a = 32.634;  act_b = 27.972; // offsets from the STEP
pcb_a = 37.14;  pcb_b = 29.85;  pcb_a0 = 1.91;  pcb_b0 = 1.64;  // STEP
lcd_a = 37.42;  lcd_b = 30.08;  lcd_a0 = 1.81;  lcd_b0 = 1.53;  lcd_y1 = 3.8;  // STEP: LCD module behind the glass
foam_a = 18;  foam_b = 28;  foam_a0 = 7.29;  foam_b0 = 2.53;   // STEP: 1.5 mm foam pad from the LCD to the PCB
pcb_y0 = 5.3;  pcb_t = 1.0;                                     // STEP: 3.8 glass + LCD, 1.5 foam pad, then the PCB
board_t = 10.7;                                                 // STEP: glass front to tallest rear part (a 2-pin 1.0 mm header)
hole_d = 2.36;  hole_ia = 3.2;  hole_ib = 0.59;                 // STEP: not holes but notches open to the long edges; centres from the PCB corner (ends 3.13 / 3.26, averaged)
btn_a = [11.23, 20.14, 29.05];                                  // STEP: RST, BOOT, PWR along portrait z (VERIFY which is which)
usb_a = 20.3;  usb_w = 9.0;  usb_h = 3.3;                       // STEP: centre 20.31, shell 8.34 wide
usb_plug_w = 13;  usb_plug_h = 7.5;  usb_plug_x0 = 3;           // VERIFY: Type-C plug overmold relief; x0 = start beyond the PCB edge
win_margin = 1.0;                                               // window = active area + this per side

// ---- derived ------------------------------------------------------------------
pcb_rear = pcb_y0 + pcb_t;
usb_y = pcb_rear + 1.27;        // Type-C centre depth: mid-mount receptacle (STEP)
btn_y = pcb_rear + 0.7;         // side-button centre depth (STEP: switch body 5.9..8.1)
pin_d = 2.4;                    // pinhole for RST / BOOT / PWR

// Board-local point to world (reads the includer's O and lean).
function b2g(p) = [O[0] + p[0],
                   O[1] + p[1]*cos(lean) + p[2]*sin(lean),
                   O[2] - p[1]*sin(lean) + p[2]*cos(lean)];
function flipp(p) = board_flip ? [glass_b - p[0], p[1], glass_a - p[2]] : p;

// ---- helpers ----------------------------------------------------------------
// 2D shape given in (x, z) extruded along +y.
module xz_extrude(h) { rotate([-90, 0, 0]) linear_extrude(height = h) mirror([0, 1, 0]) children(); }
module rrect(x0, z0, w, h, r) { translate([x0 + r, z0 + r]) offset(r = r) square([w - 2*r, h - 2*r]); }
// Rounds the convex corners of a 2D shape by r (shrink then grow back); r <= 0 leaves it alone.
module round2d(r) { if (r > 0.01) offset(r = r) offset(r = -r) children(); else children(); }
// 2D (y, z) profile extruded along +x
module across(w) { rotate([90, 0, 90]) linear_extrude(w) children(); }

// Board-local frame: x = portrait right, y = INTO the stand from the glass front, z = portrait up.
module board_frame() { translate(O) rotate([-lean, 0, 0]) children(); }
module flip() {
  if (board_flip) translate([glass_b/2, 0, glass_a/2]) rotate([0, 180, 0]) translate([-glass_b/2, 0, -glass_a/2]) children();
  else children();
}
module bf() { board_frame() flip() children(); }

// ---- board pocket and window ----------------------------------------------------
// `extra` deepens the pocket past board_t + c (a pocket that must break through a rear face)
module pocket(c = clr, extra = 0) xz_extrude(board_t + c + extra) rrect(-c, -c, glass_b + 2*c, glass_a + 2*c, glass_r + c);
// through the lip, framing the active area, with the outer rim broken by win_cham
module win_rect(g = 0) rrect(act_b0 - win_margin - g, act_a0 - win_margin - g,
                             act_b + 2*(win_margin + g), act_a + 2*(win_margin + g), 2 + g);
module window() {
  translate([0, -lip_t - 0.5, 0]) xz_extrude(lip_t + 1.0) win_rect();
  if (win_cham > 0.01) hull() {   // widens to win_cham oversize at the face, nominal win_cham deeper in
    translate([0, -lip_t - 0.5, 0]) xz_extrude(0.01) win_rect(win_cham + 0.5);
    translate([0, -lip_t + win_cham, 0]) xz_extrude(0.01) win_rect();
  }
}
module pcb_slab() translate([pcb_b0, pcb_y0, pcb_a0]) cube([pcb_b, pcb_t, pcb_a]);
module board_ghost() {   // stand-in for the real board, for assembly renders and tests
  xz_extrude(1.8) rrect(0, 0, glass_b, glass_a, glass_r);
  translate([lcd_b0, 1.8, lcd_a0]) cube([lcd_b, lcd_y1 - 1.8, lcd_a]);
  translate([foam_b0, lcd_y1, foam_a0]) cube([foam_b, pcb_y0 - lcd_y1, foam_a]);
  pcb_slab();
}
// exactly the touch/display area, in front of the glass
module active_prism() translate([act_b0, -lip_t - 0.5, act_a0]) cube([act_b, lip_t + 0.7, act_a]);

// ---- openings (board-local; `reach` = how far they run out past the board) ----------------------
module usb_slot(reach)
  translate([pcb_b0 + pcb_b - 3, usb_y - usb_h/2 - 0.4, usb_a - usb_w/2 - 0.4])
    cube([reach, usb_h + 0.8, usb_w + 0.8]);
// Relief for the plug overmold (wider/taller than the slot), cut through the wall so the plug can
// reach within a few mm of the PCB edge. Centred on the slot.
module usb_plug_relief(reach)
  translate([pcb_b0 + pcb_b + usb_plug_x0, usb_y - usb_plug_h/2, usb_a - usb_plug_w/2])
    cube([reach, usb_plug_h, usb_plug_w]);
module button_holes(reach) for (a = btn_a)
  translate([pcb_b0 + 1.0 - reach, btn_y, a]) rotate([0, 90, 0]) cylinder(d = pin_d, h = reach);

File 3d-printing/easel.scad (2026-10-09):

// easel.scad: easel desk stand for the Claude status cube
// (Waveshare ESP32-S3-Touch-LCD-1.69 + 12x40x65 mm LiPo). Units: mm.
// A tray holds the cell flat; a frame lid with a fin closes it; a carrier stands on the lid at `tilt`
// and holds the board from behind; a bezel hooks onto the carrier's legs at the bottom and frames the
// glass. Every part is modelled where it sits in the assembly (world frame: X width, Y depth with the
// front at y = 0, Z up from the desk) and turned into print orientation only for output.
// Rendered by test.sh via the `part` variable (see README.md, "Easel stand").

part = "assembly";

$fn = 48;
include <board.scad>   // board facts, fit tunables (clr, lip_t, ...) and board helpers

// ---- tunables ---------------------------------------------------------------
board_flip = false;         // board turned 180 deg in its pocket (the IMU auto-rotates the picture). false keeps
                            // the active area low in the bezel, which the tip force needs
tilt = 65;                  // screen angle from the desk; the board turns about O, the base stays put
W = 46;  D = 81;            // footprint
wall = 2.4;                 // tray walls and floor
lid_t = 2.4;                // frame lid
base_r = 4;                 // plan corner radius of tray and lid
base_cham = 0.8;            // 45 deg chamfer under the tray, against the desk

// Cell: [length, width, thickness], same names as stand.scad
bat = [65, 40, 12];
bcl = 0.4;                  // cell clearance, per side
front_space = 7.5;          // tray room in front of the cell: lead bend and the two front pilasters

// Screws: M2 self-tapping into pilots, clearance holes and counterbores in the part on top.
pilot_d = 1.8;  screw_d = 2.4;  cb_d = 4.2;  cb_depth = 1.6;
pil_d = 4.2;                // pilaster diameter
pilot_floor = 5.2;          // pilots in the tray stop this high above the desk
leg_screw_x = [14.5, 31.5]; // world x of the two vertical leg screws (and of the tray's front pilasters)
leg_screw_y = 7.6;          // world y of the same
leg_cb_up = 2.4;            // leg counterbore floor above the deck
head_d = 4.0;  head_h = 1.6;    // M2 pan head, for the head checks
foot_d = 8;  foot_depth = 0.8;  foot_in = 7;   // rubber-foot recesses, centres foot_in from the edges

// Board placement: O is the glass's front-bottom-left corner (board-local origin) in world coordinates.
O_y = 6.2;                  // world y of O
glass_up = 9.1;             // O's height above the deck

// Carrier
carrier_t = 3.2;            // back plate (thick enough to keep 1.6 under the lead groove)
bez_side = 3.2;  bez_top = 4.0;  bez_r = 4;   // panel outline around the glass (carrier and bezel)
post_d = 3;  preload = 0.2; // shoulders press this far into the PCB rear
peg_d = 1.8;  peg_l = 1.0;  // pegs into the PCB holes; peg_l = 0 turns them off
leg_w = 6;  leg_y0 = 1.5;  leg_top = -1.3;    // legs under the board (board-local y front, z top)
ridge_r = [3.2, 4.4];  ridge_y0 = 0.5;        // hinge ridges on the leg fronts: arc band about P

// Battery lead. The MX1.25 BAT header sits on the PCB rear beside the Type-C, opening towards the board
// centre (Waveshare rear view), so the plug goes in from inside and the lead leaves flat across the PCB
// rear. A groove in the carrier's front face takes it from the plug, down at cord_x, past the lower post to
// below the PCB; from there it drops through the chin cavity beside the leg into the lid slot on that side.
bat_x = 25.3;  bat_z = 10.5;                  // STEP: header inner face (board x), header centre (board z); VERIFY it opens inwards
bat_h = 3.6;  bat_w = 5.0;  bat_plug = 3.5;   // mated height off the PCB (STEP), plug width along z (2-pin MX1.25 ~4.5); VERIFY: plug out of the header
cord_d = 1.6;                                 // the lead (two 28 AWG wires), as a round envelope
cord_w = 3.0;  cord_depth = 1.6;              // groove width, and depth into the back plate
cord_x = 20;                                  // board x of the groove's upright run
bat_exit = 3.5;                               // VERIFY: free run past the plug where the lead climbs over the rear parts

// Bezel
face_cham = 0.6;            // 45 deg break on the face's top and side edges
chin_y1 = 1.2;              // rear face of the chin wall (board-local y)
chin_top = -0.6;            // top of the chin wall, below the glass (board-local z)
groove_clr = 0.2;           // hinge groove clearance around the ridge, radial and sideways
groove_y0 = 0.3;            // grooves start this far behind the face plane
pilot_in = 1.25;            // wall between a top-screw pilot and the glass pocket

// Frame fin
// The fin stands on the lid fin_gap behind the carrier, up to board-local z fin_zb, and back to world y
// fin_end; it stops a press on the screen from flexing the carrier backwards. Lightened by a window that
// leaves fin_wall all round, with fin_win_r corners.
fin_t = 5;  fin_gap = 0.2;  fin_zb = 32;  fin_sink = 0.6;  fin_end = 65;  fin_wall = 6;  fin_win_r = 3;

// Lead slots in the lid, one beside each leg
lead_x = [6.5, 35.0];  slot_w = 4.5;  slot_l = 5.5;  slot_y0 = 4.0;

// Type-C cap (optional): a friction plug for the blind plug relief in the bezel's side, flange on the side
// face, crush ribs only on the stretch that sits in the bezel (so the bezel still swings off the carrier).
cap_clr = 0.15;             // per side, into the relief
cap_rib = 0.35;             // crush rib height: cap_rib - cap_clr of it bites
cap_rib_w = 0.8;  cap_rib_y = [-2.2, 0.8];   // rib width; rib centres along board y, from the plug centre
cap_flange = 1.0;           // how far the flange stands past the relief, per side
cap_lip = 0.9;              // flange thickness
cap_ear = 2.2;              // radius of the pull ear, centred on the flange edge
cap_gap = 0.2;              // plug tip to relief floor

nudge = 0.02;               // separates faces that touch by design, in collision checks only
swing = 0;  sag = 0;        // check_swing: bezel opened this many degrees about P; board sagged on its pegs

// ---- derived ----------------------------------------------------------------
lean = 90 - tilt;
bay_w = bat[1] + 2*bcl;  bay_l = bat[0] + 2*bcl;  bay_t = bat[2] + 2*bcl;
tray_h = wall + bay_t;
deck = tray_h + lid_t;                         // top of the lid: everything above stands on it
bay_x0 = (W - bay_w)/2;  bay_y0 = wall + front_space;  bay_y1 = bay_y0 + bay_l;
rear_screw = [W/2, bay_y1 + 2.2];
assert(D >= bay_y1 + wall + 0.5, "D too short for the cell");
O = [(W - glass_b)/2, O_y, deck + glass_up];
// board-local z of the deck plane at board-local y
function deck_zb(yb) = (deck - O[2])/cos(lean) + yb*tan(lean);
// Hinge line P: the bezel's front-bottom edge, on the deck (board-local y, z).
P = [-lip_t, deck_zb(-lip_t)];
back_y = board_t + clr + carrier_t;            // carrier rear face (board-local y)
plate_y0 = board_t + clr;                      // carrier front face = bezel rear face
out_x0 = -bez_side;  out_x1 = glass_b + bez_side;  out_z1 = glass_a + bez_top;
// PCB mounting holes (board-local x, z), following board_flip
holes = [for (bx = [hole_ib, pcb_b - hole_ib], az = [hole_ia, pcb_a - hole_ia])
         let (p = flipp([pcb_b0 + bx, 0, pcb_a0 + az])) [p[0], p[2]]];
// Top screws: on the 45 deg diagonal out of each upper glass corner arc, pilot_in clear of the pocket.
pilot_off = (glass_r + clr + pilot_in + pilot_d/2)/sqrt(2);
top_pts = [[glass_r - pilot_off, glass_a - glass_r + pilot_off],
           [glass_b - glass_r + pilot_off, glass_a - glass_r + pilot_off]];
// Stability reference points (board-local), and the tip pivots (world y)
press_pt = flipp([act_b0 + act_b/2, 0, act_a0 + act_a/2]);
top_pt = board_flip ? flipp([act_b0 + act_b/2, 0, act_a0]) : [act_b0 + act_b/2, 0, act_a0 + act_a];
pivot_y = D - foot_in + foot_d/2 - 1;          // 1 mm inside the rear edge of the rear feet
front_y = foot_in - foot_d/2 + 1;

// ---- shared helpers -------------------------------------------------------------
module yslab(y0, y1) translate([0, y0, 0]) xz_extrude(y1 - y0) children();
module above(z) translate([-200, -200, z]) cube([400, 400, 200]);
module plan_rr(w, d, r) translate([r, r]) offset(r = r) square([w - 2*r, d - 2*r]);
// a vertical hole of diameter d at world (x, y), from z0 to z1
module vhole(p, d, z0, z1) translate([p[0], p[1], z0]) cylinder(d = d, h = z1 - z0);
// the panel outline of carrier and bezel, in board-local (x, z)
module outline2d() rrect(out_x0, -30, out_x1 - out_x0, out_z1 + 30, bez_r);
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

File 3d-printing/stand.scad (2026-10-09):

// stand.scad: desk stand for the Claude status cube
// (Waveshare ESP32-S3-Touch-LCD-1.69 + 12x40x65 mm LiPo). Units: mm.
// Rendered by test.sh via the `part` variable (see README.md for the print and fit-check procedure).

part = "assembly";

$fn = 48;
include <board.scad>   // board facts, fit tunables (clr, lip_t, ...) and board helpers

// ---- tunables ---------------------------------------------------------------
board_flip = true;          // board turned 180 deg in its pocket (the IMU auto-rotates the picture). true: the
                            // pusher posts land clear of the RST switch and the BAT header (Waveshare STEP)
tilt = 65;                  // screen angle from the desk
insert_mode = false;        // true: heat-set insert holes instead of self-tapping pilots
pilot_d = 1.8;              // M2 self-tapping pilot
insert_d = 3.2;             // M2 heat-set insert hole

wall = 2.4;  plate_t = 2.4;
rim = 3.0;                  // face margin below the glass
rim_top = 5.0;              // face margin above the glass (keeps the apex skin thick at any tilt)
bcl = 0.4;                  // battery clearance, per side
side_gap = 1.0;             // extra room beside the battery pocket
end_zone = 7.5;             // room at each end of the battery for bosses / pushers
boss_r = 2.6;  boss_h = 8;

// Edge rounding (cosmetic): set any of these to 0 for the original hard edges.
edge_r = 3.0;        // the four vertical corners, in plan; shell and base plate share it
prof_r = 2.5;        // apex ridge, back top edge, and the kink at the foot of the face
plate_cham = 0.8;    // 45 deg chamfer under the base plate, against the desk

// Battery: [length, width, thickness]
bat = [65, 40, 12];

// ---- derived ----------------------------------------------------------------
lean = 90 - tilt;                              // screen lean from vertical
bay_l = bat[0] + 2*bcl;  bay_w = bat[1] + 2*bcl;  bay_t = bat[2] + 2*bcl;
inner_w = bay_w + 2*side_gap;
W = inner_w + 2*wall;
z0 = max(16, bay_t + 3);                       // height of the face's bottom edge
face_len = glass_a + 2*clr + rim + rim_top;
F1 = [face_len*sin(lean), z0 + face_len*cos(lean)];   // top edge of the face, in (y, z)
z_back = bay_t + wall + 1.5;                   // outer roof height at the back
bx0 = (W - bay_w)/2;                           // battery pocket origin (z = 0 is the plate top)
// Board-local origin (glass front face, portrait bottom-left corner) in global coordinates.
O = [(W - glass_b)/2,
     (rim + clr)*sin(lean) + lip_t*cos(lean),
     z0 + (rim + clr)*cos(lean) - lip_t*sin(lean)];
// The two lowest PCB mounting-hole positions (world-lowest even with board_flip), at the PCB rear face.
push_local = [for (bb = [hole_ib, pcb_b - hole_ib])
              [pcb_b0 + bb, pcb_rear, pcb_a0 + (board_flip ? pcb_a - hole_ia : hole_ia)]];
push_d = 3.0;  preload = 0.2;                            // pusher post diameter; interference into the PCB rear
// Front-end room: the pusher posts must stay >= push_gap in front of the battery bay. With board_flip or
// a low tilt the posts sit further back, so the front end zone grows to keep that gap (deeper stand).
push_gap = 1.0;
push_pts = [for (p = push_local) b2g(flipp(p))];
push_ymax = max([for (p = push_pts) p[1]]) + push_d/2;
end_front = max(end_zone, push_ymax + push_gap - wall);
inner_d = bay_l + end_front + end_zone;
D = inner_d + 2*wall;
by0 = wall + end_front;
assert(by0 >= push_ymax + push_gap - 1e-6, "pusher posts too close to the battery bay: raise tilt or end_zone");
boss_xy = [for (x = [wall + boss_r, W - wall - boss_r], y = [wall + boss_r, D - wall - boss_r]) [x, y]];

// ---- shell body -------------------------------------------------------------
function profile_pts(zb) = [[0, zb], [0, z0], F1, [D, z_back], [D, zb]];
// Footprint in plan, inset by t, with the four vertical corners rounded.
module foot2d(t = 0) round2d(edge_r - t) offset(delta = -t) square([W, D]);
// The outer body, inset by t on every face and cut flat at z = zb (zb < 0 leaves the bottom open).
// Convex edges are rounded: edge_r in plan, prof_r in the side profile, each reduced by the inset, so
// the wall keeps its full thickness through a corner. The profile is extended well below the cut, so
// the bottom edge stays square: the shell prints on that rim and its seam with the plate stays tight.
module outer_body(t = 0, zb = 0) intersection() {
  translate([t, 0, 0]) across(W - 2*t) round2d(prof_r - t) offset(delta = -t) polygon(profile_pts(-5));
  translate([0, 0, zb]) linear_extrude(200) foot2d(t);
}
module outer_solid() outer_body();
module outer_inset(t) outer_body(t, t);
// open at the bottom
module inner_void() outer_body(wall, -5);

module boss(p) {
  sx = p[0] < W/2 ? -1 : 1;  sy = p[1] < D/2 ? -1 : 1;
  // starts 1 mm below z=0 (clipped in front_shell): a boss bottom coplanar with the wall bottom is non-manifold
  translate([p[0], p[1], -1]) hull() {
    cylinder(r = boss_r, h = boss_h + 1);
    translate([sx*(boss_r + wall/2) - 0.5, sy*(boss_r + wall/2) - 0.5, 0]) cube([1, 1, boss_h + 1]);
  }
}
module bosses() for (p = boss_xy) boss(p);
module boss_pilots() for (p = boss_xy) translate([p[0], p[1], -0.01]) cylinder(d = insert_mode ? insert_d : pilot_d, h = boss_h - 1);

module front_shell() difference() {
  intersection() {
    union() { difference() { outer_solid(); inner_void(); } bosses(); }
    outer_solid();   // clips the bosses' 1 mm overshoot below z=0
  }
  bf() { pocket(); window(); }
  usb_cut();
  usb_plug_cut();
  button_cuts();
  boss_pilots();
}

// ---- battery bay -------------------------------------------------------------------
// The bay is the open interior above the plate; the plate's ribs locate the cell.
module bay_ghost() translate([bx0, by0, 0]) cube([bay_w, bay_l, bay_t]);
// outer_inset(wall) has its own floor at z = wall; fill that floor so only the roof/front/back can be hit
module roof_inset() { outer_inset(wall); translate([0, 0, -1]) cube([W, D, wall + 1]); }
module battery_ghost() translate([bx0 + bcl, by0 + bcl, 0]) cube([bat[1], bat[0], bat[2]]);

// ---- base plate --------------------------------------------------------------------
screw_clear_d = 2.4;  cb_d = 4.2;  cb_depth = 1.6;       // M2 clearance and counterbore (underside)
foot_d = 8;  foot_depth = 0.8;                           // rubber-foot recesses (underside)
foot_xy = [for (x = [8, W - 8], y = [D/2 - 20, D/2 + 20]) [x, y]];
rib_t = 0.8;  rib_h = 6;  rib_seg = 4;  rib_side = 12;   // short ribs leave a finger gap beside the cell


// A vertical post from the plate, cut flat on the PCB rear plane (minus `preload`), so it presses the
// board up the slope and into the glass pocket.
module pusher(gp) difference() {
  translate([gp[0], gp[1], 0]) cylinder(d = push_d, h = gp[2] + 6);
  bf() translate([-100, -100, -100]) cube([300, 100 + pcb_rear - preload, 300]);
}
module pushers() for (gp = push_pts) pusher(gp);

module bay_ribs() {
  for (x = [bx0, bx0 + bay_w - rib_seg], y = [by0 - rib_t, by0 + bay_l])
    translate([x, y, 0]) cube([rib_seg, rib_t, rib_h]);                       // end ribs
  // side ribs run through the end ribs' outer faces: corner-only contact would be a non-manifold edge
  for (x = [bx0 - rib_t, bx0 + bay_w], y = [by0 - rib_t, by0 + bay_l - rib_side + rib_t])
    translate([x, y, 0]) cube([rib_t, rib_side, rib_h]);
}

// Same outline as the shell footprint, so the two parts stay flush around the seam, with the underside
// edge chamfered so nothing sharp meets the desk. Prints as a 45 deg outward overhang off the bed.
module plate_body() hull() {
  translate([0, 0, -plate_t + plate_cham]) linear_extrude(plate_t - plate_cham) foot2d();
  translate([0, 0, -plate_t]) linear_extrude(0.01) foot2d(plate_cham);
}

module base_plate() difference() {
  union() {
    plate_body();
    bay_ribs();
    pushers();
  }
  for (p = boss_xy) translate([p[0], p[1], -plate_t - 0.01]) {
    cylinder(d = screw_clear_d, h = plate_t + 0.02);
    cylinder(d = cb_d, h = cb_depth + 0.01);
  }
  for (f = foot_xy) translate([f[0], f[1], -plate_t - 0.01]) cylinder(d = foot_d, h = foot_depth + 0.01);
}

// ---- openings --------------------------------------------------------------------------
module usb_cut() bf() usb_slot(W);
module usb_plug_cut() bf() usb_plug_relief(W);
module button_cuts() bf() button_holes(W);
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

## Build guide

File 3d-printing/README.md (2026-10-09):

# Claude status cube: desk stands

Two printed stands, both parametric and both checked by `test.sh`. They share the board facts and fit tunables in `board.scad` (glass, PCB, openings, `clr`, `lip_t`), so a measurement corrected there fixes both. Each stand sets its own `board_flip` (see [Orientation](#orientation)).

The board facts come from Waveshare's STEP model of the board (`ESP32-S3-Touch-LCD-1_69.stp`, Creo export): glass 33.13 x 41.13 with r ~6.4 corners and a rounded front edge, 3.8 mm of glass and LCD, a 1.5 mm foam pad, a 1.0 mm PCB whose front face is 5.3 mm behind the glass front, and rear parts up to 10.7 mm (a vertical 2-pin 1.0 mm header; the BAT header reaches 9.8, the Type-C 9.65). The PCB has no closed mounting holes: the four "holes" are Ø2.36 notches open to the long edges. The STEP figures are the vendor's CAD, not caliper readings: measure the overall thickness and the glass-to-PCB-rear depth on your board before a full print.

- **Wedge** (`stand.scad`, below): one closed body and a base plate.
- **Easel** (`easel.scad`, see [Easel stand](#easel-stand)): a slim bezel at 65 deg on a low tray that holds the cell; screws only, every part prints flat without supports.

The wedge is a two-part printed desk stand for the Waveshare ESP32-S3-Touch-LCD-1.69 and a 12 x 40 x 65 mm LiPo. The board sits in a glass pocket in the sloped front face (65 deg screen angle by default), the cell lies flat in a bay behind and below it, and a base plate with two pusher posts closes the bottom and presses the board into the pocket. Everything is parametric in `stand.scad`; `test.sh` checks the geometry with boolean-intersection tests.

> **Biggest unverified risk: board retention.** The board has only two lower rear contacts (the two pusher posts on the base plate); nothing supports the upper board from behind, and the pusher/retention mechanism is NOT in `fit-check.stl`, so the fit-check cannot validate retention. Touch-time rattle or flex can only be judged on the full print. Fallbacks if it rattles: foam on the pusher tips (then set `preload = -0.8`), or add a rear pad at the roof. The posts press on the PCB around the edge notches. Against the STEP model's parts they clear everything only with `board_flip = true`, the wedge's default; unflipped, they hit the RST switch and the BAT header.

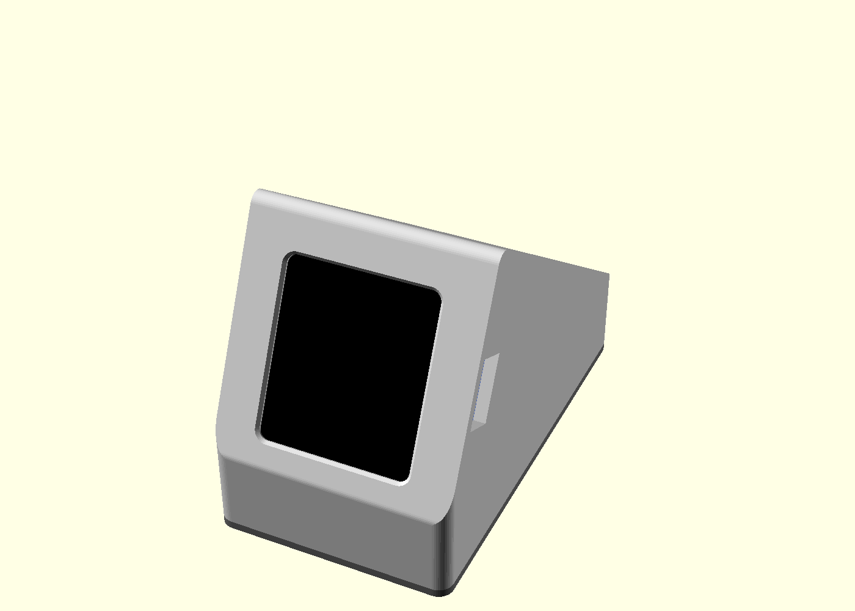
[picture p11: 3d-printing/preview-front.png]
front

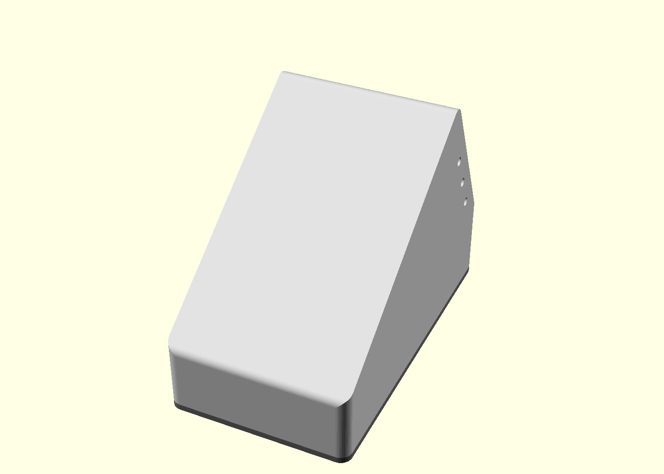
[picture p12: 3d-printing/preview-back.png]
back

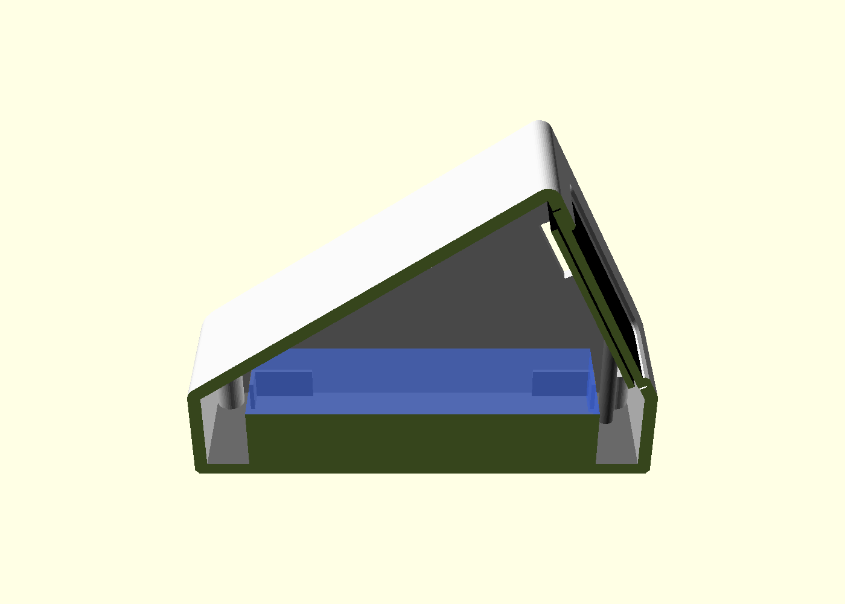
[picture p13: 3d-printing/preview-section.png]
section


Outer envelope 47.6 x 88.44 x 59.89 mm (front shell). Every dimension marked `VERIFY` in `stand.scad` is an estimate to confirm on a real print. The preview images predate the STEP-based board (thinner board, 85.6 mm deep, unflipped) and are illustrative only.

## Print list

1. `fit-check.stl` first (1624 triangles, print time not measured): a slice of the shell around the glass pocket with both side walls. It tests glass fit, window, Type-C relief and pinholes only, not retention. The slice has no horizontal face: print it lying on its rear cut face (the large flat face opposite the glass; use the slicer's lay-on-face, which is a rotation of `tilt` = 65 deg from the modelled orientation), so the glass face and pocket point up and no supports should be needed. Printing as modelled needs supports.
2. `stand-front.stl` (3204 triangles) and `stand-base.stl` (3124 triangles).
3. `usb-cap.stl` (320 triangles), optional: the Type-C blanking cap. See below.

Settings: 0.2 mm layers, 3 perimeters, 20% infill, PLA or PETG.

- **Front shell** prints as modelled, open bottom on the bed, with supports for the interior roof and the glass-pocket ceiling (both are required). The supports sit inside the open cavity and come out through the bottom.
- **Base plate** (`base_print()`): print with the plate's bottom face (z = -plate_t, the side with the counterbores and foot recesses) on the bed and the pushers pointing up. No supports; the `plate_cham` chamfer is a 45 deg outward overhang off the bed.

## Edges

Four cosmetic radii in `stand.scad`, each independent and each `0` for the original hard-edged wedge:

| | | |
|---|---|---|
| `edge_r` | 3.0 | the four vertical corners, in plan. The shell and the base plate share it, so the two parts stay flush around the seam. The inner cavity is rounded to `edge_r - wall` so the wall keeps its full 2.4 mm through a corner (`check_wall`). |
| `prof_r` | 2.5 | apex ridge, back top edge and the kink at the foot of the face. Costs 1.23 mm of height at the apex; the glass-pocket skin still passes `check_skin`. |
| `win_cham` | 0.6 | a 45 deg break around the window, where a finger meets the screen edge. |
| `plate_cham` | 0.8 | a 45 deg chamfer under the base plate, so nothing sharp meets the desk. |

The bottom rim of the shell is deliberately left square: it is the print surface and the mating face for the plate.

## Type-C blanking cap

`usb-cap.stl` (`part="cap"`) closes the Type-C opening when nothing is plugged in. It is modelled in its
print orientation: flange face on the bed, tongues up, no supports, about a gram of filament.

Two sprung tongues reach through the wall and snap behind its inner face; the flange covers the opening
from the outside and carries a lift ear, so a fingernail pops it out. It follows `board_flip` like every
other opening, so it fits whichever wall the port ends up on.

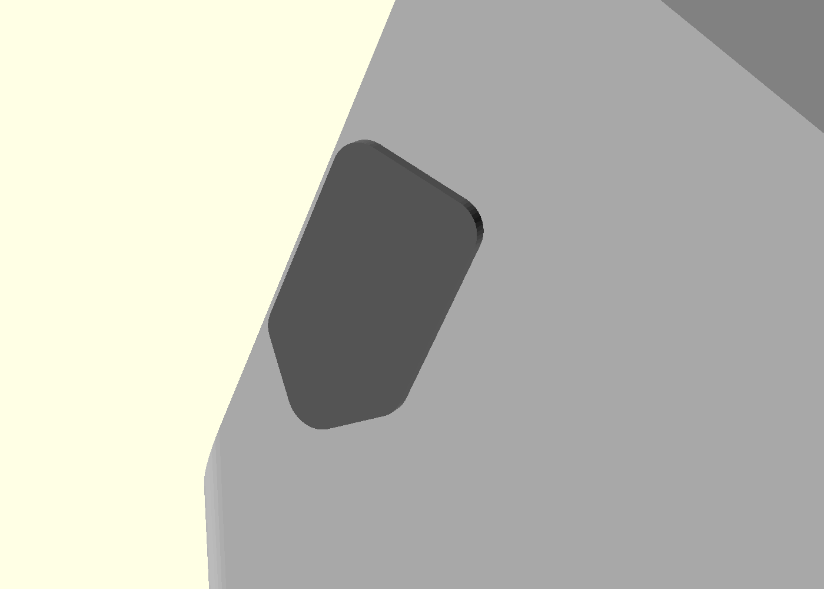
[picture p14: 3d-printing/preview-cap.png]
cap fitted


| | | |
|---|---|---|
| `cap_clr` | 0.15 | clearance into the opening, per side |
| `cap_barb` | 0.45 | snap ridge, per side; `cap_barb - cap_clr` = 0.3 mm of it engages behind the wall |
| `cap_wall` | 0.8 | tongue thickness: this is what flexes, so thinner is softer |
| `cap_flange` | 1.6 | how far the flange stands past the opening, per side |
| `cap_lip` | 0.9 | flange thickness: how far it stands proud of the wall |
| `cap_ear` | 2.2 | radius of the lift ear |
| `cap_land` | 1.0 | how far the tongues reach past the inner wall face |

The fit is **unverified on a print**, and it inherits every `VERIFY` in the Type-C relief: the cap is sized
from `usb_plug_w` x `usb_plug_h`, so if you change those after measuring your plug, the cap follows. Print
it with the fit-check coupon and try it in that first: too tight to start, raise `cap_clr`; falls out,
raise `cap_barb` or lower `cap_clr`; too stiff to push in, lower `cap_wall`.

The geometry tests check that the tongues pass through the opening with clearance, that the barbs really
do reach past the inner wall face, that the flange covers the opening and seats on flat wall, and that
nothing touches the board, each with a control that must fail.

## Hardware

- 4 x M2 x 6 self-tapping screws (an M2 x 8 bottoms out at the pilot) (or heat-set inserts with `insert_mode = true`)
- 4 rubber feet, 8 mm
- optional 1 mm foam tape on the pusher tips (then set `preload = -0.8`)

## Assembly order

1. Connect the battery to the board before closing (see the polarity warning).
2. Set the board into the glass pocket from behind, glass first.
3. Screw on the base plate; the pushers press the board's lower edge into the pocket.
4. Stick on the feet.

## Fit-check procedure

Print `fit-check.stl` and check:

- the glass drops in without force: if tight or loose, adjust `clr` (and `glass_a`, `glass_b`, `glass_r`);
- the window leaves the touch area clear: `act_a0`, `act_b0`, `win_margin`;
- the Type-C plug seats: the slot (`usb_a`, `usb_w`, `usb_h`) is surrounded by a plug relief (`usb_plug_w` x `usb_plug_h` = 13 x 7.5 mm, VERIFY) cut through the wall starting `usb_plug_x0` = 3 mm beyond the PCB edge, so the overmold can reach within a few mm of the board edge (the PCB edge is about 8.9 mm from the outer wall, the wall is 2.4 mm thick). Measure your plug and adjust `usb_plug_w`, `usb_plug_h`, `usb_plug_x0`;
- a paper clip reaches RST / BOOT / PWR through the pinholes: `btn_a`, `btn_y`, `pin_d`;
- the tallest rear part clears: `board_t`.

The opening positions (Type-C slot, buttons) and the board dimensions come from the STEP model; the plug relief and the button order (RST / BOOT / PWR) are still `VERIFY` items: check them on the fit-check print, edit the values, and re-run `./test.sh stand` after every edit. Also check the battery position against the board's chip antenna (see Antenna).

## Orientation

In the unflipped board frame (the STEP model, turned 180 deg in-plane so its button positions match `btn_a`), the Type-C and the BAT header are on the right edge and RST / BOOT / PWR on the left. `board_flip = true` rotates the board 180 deg in its pocket and swaps the openings to the opposite walls. No firmware change is needed either way: the cube reads its IMU and turns the picture the right way up on its own.

Each stand sets `board_flip` itself, because the right choice differs:

- **Wedge** (`stand.scad`): `true`, so the Type-C and the battery connector are on the **left** wall and the buttons on the right. Unflipped, the pusher posts land on the RST switch and the BAT header. Flipped, the posts sit further back, so the front end zone grows to keep them at least 1 mm (`push_gap`) in front of the battery bay: 88.44 mm deep at tilt 65 (88.37 unflipped, 89.1 at tilt 55).
- **Easel** (`easel.scad`): `false`, so the Type-C is on the right. Flipped, the active area sits 2.55 mm higher in the bezel and the centre-press tip force drops to 2.76 N, under the 3.0 N the tests require.

Re-export the STLs after changing either.

## Battery polarity warning

MX1.25 connector pinouts vary by vendor. Compare the battery lead against the `+` / `-` marks on the board before connecting; a swapped pair can destroy the board or the cell. The battery pocket is 65.8 x 40.8 x 12.8 mm and the LiPo must not be compressed: do not force a thicker cell in, and do not let the lid or the base squeeze it.

## Antenna

The battery and its metal pouch must not sit over the board's chip antenna. The STEP model has a 6 x 2 x 1 mm part on the PCB rear at the board's short edge, on the buttons' side (unflipped board x 7.6..13.6, z 2.0..4.0), which is probably the antenna; the stands do not model it, so the bay position relative to it is **unverified**: before closing the stand, locate the chip antenna on the board and confirm physically that the battery does not sit over it. The body is plastic only.

## Tests and regenerating

`./test.sh` (both stands; `./test.sh stand` or `./test.sh easel` for one; uses Docker via `tools/openscad`, override with `OPENSCAD=...`) must exit 0. Export:

```sh
tools/openscad --backend=manifold -D 'part="front"' -o stand-front.stl stand.scad   # also part="base", part="fit", part="cap"
python3 tools/stlcheck.py stand-front.stl
```

Previews were rendered headless with `--render` and `xvfb-run` (installed with apt inside the Docker image; not scripted here), using `part="assembly"` / `part="section"` / `part="cap_fitted"` with a section camera rotated 270 deg about z. They are illustrative and not reproducible from this repo alone.

## Easel stand

`easel.scad`. The board stands at 65 deg (`tilt`) in a slim bezel, held from behind by a carrier that stands on the lid of a low tray; the 12 x 40 x 65 mm cell lies flat in the tray, mostly behind the screen. Assembled envelope 46 x 81 x 67.8 mm. Same constraints as the wedge: the whole active area open, Type-C reachable (plug relief plus an optional cap), RST / BOOT / PWR through pinholes, plastic only near the antenna, no supports.

### Print list

| File | Part | Print orientation |
|---|---|---|
| `easel-tray.stl` | tray, 46 x 81 x 15.2, battery bay, screw pilasters, Ø8 foot recesses | open side up |
| `easel-frame.stl` | 2.4 mm lid with a lightened centre fin that backs the carrier | lid down |
| `easel-carrier.stl` | 3.2 mm back plate with a groove for the battery lead, four posts (shoulders press the PCB, pegs locate it in its edge notches), two legs with hinge ridges | rear face down |
| `easel-bezel.stl` | glass pocket and window, open chin with hinge grooves, Type-C relief, pinholes | front face down |
| `easel-usb-cap.stl` | optional Type-C blanking cap (crush ribs) | flange down |

**Print the carrier first** and press the real board onto its pegs before printing the rest: the notch positions come from the STEP model, not a measured board. If the pegs miss, set `peg_l = 0`; the shoulders still press the PCB, though only the rim around each notch (about 7 mm² in all).

### Hardware

Self-tapping M2 into Ø1.8 pilots, no glue: 2 x M2 x 10 (legs), 1 x M2 x 8 (rear of the lid), 2 x M2 x 6 (top of the bezel, from the carrier's rear). 4 x Ø8 rubber feet.

### Assembly order

1. Cell into the tray, tab end forwards; thread the lead up through the lid slot on the board's connector side.
2. Frame on; fit the rear M2 x 8.
3. Carrier on the lid; two M2 x 10 down through the legs clamp carrier, lid and tray in one go. These go in **before the board**: once the board and bezel are on, the leg screws are covered.
4. Plug the lead into the board's BAT header (it sits beside the Type-C, nearer the board's bottom end, and is assumed to open towards the board centre, so the lead leaves across the PCB rear). Lay the lead in the groove in the carrier's front face: across, down past the lower post, out under the board edge and down beside the leg to the slot. Then press the board onto the pegs, glass outwards, without pinching the lead.
5. Hold the bezel tilted forward with its front-bottom edge on the lid and swing it back over the glass: the grooves in its chin pick up the ridges on the legs.
6. Two M2 x 6 from the carrier's rear into the bezel.

To get at the board or the lead later, take out the two top screws and swing the bezel off.

### Hinge

Ridges and grooves are arc bands concentric with the bezel's front-bottom edge (the hinge line), so swinging the bezel about that edge slides each groove along its ridge and nothing else meets. Closed, the ridges stop the chin lifting or sliding forward and the grooves locate it sideways. The lower corners of the glass pocket are square behind the glass on purpose: round ones sweep into the glass and PCB corners during the swing. The tests swing it 5, 10, 20 and 30 deg with the board nominal and sagged 0.2 mm on its pegs. Clearances are 0.2 mm in printed plastic; if it binds, sand the ridges.

### Stability

`tools/stability.py` estimates mass, centre of gravity and the push into the screen that tips the stand backwards, from the parts in place (PLA at 1.24 g/cm³ x 0.9 solidity, 55 g cell, 12 g board, pivot 1 mm inside the rear feet). Nominal: 112.7 g; 3.28 N at the centre of the active area, 1.49 N at its top edge (`test.sh` requires 3.0 and 1.3). Estimates, not measurements.

### VERIFY (easel-specific, on top of the board items in `board.scad`)

- PCB notch positions (the pegs): from the STEP model, averaged end to end (3.13 and 3.26 mm from the PCB ends).
- The MX1.25 BAT header and the lead route (`bat_x`, `bat_z`, `bat_h`, `bat_w`, `bat_plug`, `bat_exit`). The header's position and height are from the STEP model (`bat_z` = 10.5, beside the Type-C towards the bottom end); which way it opens and how far the mated plug stands out are not, and `bat_w` = 5 is a 2-pin MX1.25 plug, not the header with its solder tabs. `check_cord` runs the plug and a Ø1.6 lead from the header through the groove (`cord_x`, `cord_w`, `cord_depth`) to the lid slot, clear of every part. It treats everything on the PCB rear as reaching `board_t`, except the header and `bat_exit` mm past the plug, where the lead climbs into the groove. If a tall part sits in that run, move `cord_x`.
- Which end of the cell the tabs leave from (assumed: the front).

`board_flip` works here too (but see [Orientation](#orientation)) and needs no firmware change. Export:

```sh
tools/openscad --backend=manifold -D 'part="carrier"' -o easel-carrier.stl easel.scad   # also tray, frame, bezel, cap (-> easel-usb-cap.stl)
python3 tools/stability.py build/easel   # after ./test.sh easel has rendered the at_* parts
```

There are no easel preview images (no headless PNG export here); `part="assembly"` and `part="section"` render the parts in place for viewing in OpenSCAD.

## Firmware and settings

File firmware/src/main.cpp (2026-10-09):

// Claude status cube -- Waveshare ESP32-S3-Touch-LCD-1.69
//
// Polls the host bridge for a small pre-formatted JSON payload and renders it
// as a swipeable deck of cards. Swipe left/right to change card; the deck can
// also auto-advance (the rotate setting).

#include <Arduino.h>
#include "battery.h"
#include "ble.h"
#include "buzzer.h"
#include "config.h"
#include "cpu_policy.h"
#include "deck_util.h"
#include "display.h"
#include "gesture.h"
#include "idle_sleep.h"
#include "imu.h"
#include "net.h"
#include "orientation.h"
#include "ota.h"
#include "payload.h"
#include "dev_editor.h"
#include "pomo_editor.h"
#include "pomo_settings.h"
#include "pomodoro.h"
#include "portal.h"
#include "readings_key.h"
#include "settings.h"
#include "settings_json.h"
#include "touch.h"
#include "touch_map.h"
#include "transport_policy.h"
#include "ui.h"
#include "unlock_prompt.h"
#include "volume_slider.h"

// Divides every Pomodoro duration. Leave at 1. `make run POMO_FAST=60` in
// sim/ turns minutes into seconds, so a whole cycle and the phase-end alert
// can be watched in about two minutes.
#ifndef POMO_TIME_DIV
#define POMO_TIME_DIV 1
#endif

// Keep WiFi up while BLE is live (OTA needs it). A config.h from before this
// existed still builds.
#ifndef WIFI_ALWAYS_ON
#define WIFI_ALWAYS_ON 0
#endif

namespace {

// While a ring moves a frame is drawn on every pass, and the pass is held to
// this so the loop does not spin: ~60 fps, which is what a whole-frame push
// over SPI allowed before only changed rows were sent. The animations are
// timed, so this sets how smooth they look, not how long they take.
constexpr uint32_t FRAME_MS = 16;

Display lcd;
Touch touch;
Payload payload{};
// Built from the compile-time defaults only so the object exists; setup()
// applies the stored settings once NVS is read.
Pomodoro pomo(pomoConfigFrom(pomoDefaults(), POMO_TIME_DIV));
uint32_t lastPomoSec = 0xFFFFFFFFu;  // the clock value last drawn, to redraw when it changes
uint8_t lastBatPct = 255;  // battery percent last drawn, to redraw when it changes

uint8_t cardIndex = 0;
uint32_t lastPoll = 0;
uint32_t lastRotate = 0;
uint32_t lastGood = 0;  // millis() of the last successful fetch
uint32_t lastReadings = 0;  // readingsKey() of the last payload: only a change keeps the screen awake
uint32_t lastDraw = 0;
bool dirty = true;
// The Volume card: in the deck while a Mac is bonded, between the payload cards
// and the Pomodoro. `deckVolume` is what the deck was last built with, so a
// bond coming or going can keep the viewer on their card.
VolumeSlider volSlider;
// The media button last tapped on the Volume card (a MediaKey, -1 none), lit for VOLUME_PRESS_MS.
int8_t mediaPressed = -1;
uint32_t mediaPressedAt = 0;
bool deckVolume = false;
// The Mac is locked and unlocks for a tap (unlock_prompt.h): a screen over the deck.
UnlockPrompt unlock;
bool volumeShown() { return bleBonded(); }
uint8_t deckSize() { return uiDeckSize(payload, deckVolume); }
uint8_t pomoIndex() { return uiPomodoroIndex(payload, deckVolume); }
bool onVolumeCard() { return deckVolume && cardIndex == uiVolumeIndex(payload); }
DeckSpot deckSpot() {
  return cardIndex == pomoIndex() ? DeckSpot::Pomodoro : onVolumeCard() ? DeckSpot::Volume : DeckSpot::Payload;
}

TransportPolicy policy;
bool wifiUp = false;           // netStart() called and not yet netStop()
bool otaUp = false;            // otaBegin() called and not yet otaEnd()
IdleSleep idle;
bool screenOn = true;
CpuPolicy cpuPolicy;  // fast clock for touch and animation, slow otherwise (cpu_policy.h)
uint32_t cpuMhz = CPU_MHZ_FAST;  // the clock last set; the board boots at board_build.f_cpu
bool swallowTouch = false;  // the touch that woke the screen is ignored until the finger lifts
bool pairWaitDismissed = false;  // a touch dismisses the first-boot "waiting for a Mac" screen

// Auto-rotate (orientation.h). `orient` is what the IMU says; `appliedRot` is what
// is on the panel: they differ only while the screen sleeps, so the panel is
// never written to while it is off. Touch is remapped by `appliedRot`.
Orientation orient;
uint8_t appliedRot = 0;
bool imuUp = false;
bool touchOnVolumeRow = false;  // ... and landed in its button row: a tap there, never a drag
bool touchOnVolume = false;  // the finger now down landed on the Volume card (latched at landing)
bool touchDown = false;  // a finger was on the glass at the last poll: do not flip under it
uint32_t lastImu = 0;
constexpr uint32_t IMU_POLL_MS = 200;

// First boot with neither a Mac nor a network and nothing received yet.
bool waitingToPair() { return pairWaitAtBoot(bleBonded(), settingsHaveWifi()) && !payload.valid; }

// Gestures come from raw coordinates (see gesture.h), which keeps this working
// across the CST816S/T/D variants, whose gesture registers disagree.
GestureTracker gestures;

// The Pomodoro settings editor (swipe up on the idle Pomodoro card). While it
// is open nothing else moves the deck, and multi-tap is off so a double tap
// cannot start a session behind it. `editSettings` is the working copy.
bool editing = false;
bool editingDevice = false;  // the display panel, not the Pomodoro editor, is the open one
DeviceSettings editDevice{};
PomoSettings editSettings{};
// The Mac changed the Pomodoro lengths while a phase ran: they reach the timer
// at the next point where setConfig takes them (pomodoro.h).
bool pomoConfigPending = false;

constexpr uint32_t SETUP_HOLD_MS = 5000;
constexpr uint32_t SETUP_WINDOW_MS = 3000;

// Touching the screen just after the cube powers up forces the setup portal,
// so a working cube can be pointed at a new network without a reflash. The
// touch must then be held for SETUP_HOLD_MS.
bool setupHoldRequested() {
  int16_t x, y;
  // touch.begin() resets the controller, which then ignores a finger that was
  // already down, so a touch is looked for for a short window after the reset
  // rather than only at the instant of boot. It costs a normal boot 3 s, which the hint on screen explains.
  const uint32_t w0 = millis();
  bool touched = false;
  uiMessage(lcd, "STARTING", "HOLD SCREEN FOR SETUP");
  while (millis() - w0 < SETUP_WINDOW_MS && !touched) {
    touched = touch.read(x, y);
    if (!touched) delay(20);
  }
  Serial.printf("[boot] setup-touch window: touched=%d\n", (int)touched);
  if (!touched) return false;
  Serial.println("[boot] touch at boot: keep holding for WiFi setup");
  uiMessage(lcd, "KEEP HOLDING", "FOR SETUP");
  const uint32_t t0 = millis();
  uint8_t misses = 0;
  while (millis() - t0 < SETUP_HOLD_MS) {
    misses = touch.read(x, y) ? 0 : misses + 1;
    if (misses > 5) return false;  // a few dropped reads are not a release
    delay(20);
  }
  return true;
}

void step(int delta) {
  // Also when there is nowhere to go: otherwise the timer stays expired and the
  // first payload to arrive is swiped away from the Pomodoro card at once.
  lastRotate = millis();
  const uint8_t n = deckSize();
  if (n <= 1) return;
  cardIndex = (cardIndex + n + delta) % n;
  if (cardIndex == pomoIndex()) uiReplayPomodoro();
  else if (onVolumeCard()) uiReplayVolume();
  else uiReplay(cardIndex);
  dirty = true;
}

// The Mac edited settings over BLE: apply, tell it how it went, and reboot when
// the network settings changed (they are only read at boot).
void handleBleSettings() {
  char json[SETTINGS_JSON_MAX + 1];
  if (!bleTakeSettings(json, sizeof(json))) return;
  const SettingsResult r = settingsApplyJson(json);
  Serial.printf("[ble] settings write -> %d\n", (int)r);
  bleSettingsReply((uint8_t)r);
  if (r == SettingsResult::Invalid) return;
  pomoConfigPending = !pomo.setConfig(pomoConfigFrom(pomoSettings(), POMO_TIME_DIV));
  // The Mac's write wins over an open editor: it shows what is now stored,
  // rather than saving its older copy over it on DONE.
  if (editing) {
    editDevice = deviceSettings();
    editSettings = pomoSettings();
  }
  if (screenOn) lcd.setBrightness(deviceSettings().backlight);
  buzzerSetLevel(deviceSettings().sound);
  lastRotate = millis();
  dirty = true;
  if (r == SettingsResult::OkReboot) {
    delay(500);  // let the notification leave
    ESP.restart();
  }
}

void openEditor() {
  editSettings = pomoSettings();
  editing = true;
  uiEditorSlide(true, editSettings);
  dirty = true;
}

void openDeviceEditor() {
  editDevice = deviceSettings();
  editing = true;
  editingDevice = true;
  uiDeviceSlide(true, editDevice);
  dirty = true;
}

// DONE and swipe-up both land here. Brightness and sound were previewed live
// while editing; the rest takes effect now.
void closeDeviceEditor() {
  if (editDevice != deviceSettings()) {  // spare the flash
    deviceSettingsSave(editDevice);
    bleSettingsChanged();
  }
  lcd.setBrightness(deviceSettings().backlight);
  buzzerSetLevel(deviceSettings().sound);
  editing = false;
  editingDevice = false;
  uiDeviceSlide(false, editDevice);
  lastRotate = millis();
  idle.data(millis());  // the sleep timer starts over from the edit
  dirty = true;
}

void deviceEditorGesture(Gesture g) {
  if (g == Gesture::SwipeUp) {
    closeDeviceEditor();
  } else if (g == Gesture::Tap) {
    const EditHit hit = devEditorHit(gestures.startX(), gestures.startY());
    if (hit.action == EditAction::Done) {
      closeDeviceEditor();
    } else if (hit.action != EditAction::None) {
      const uint8_t soundBefore = editDevice.sound;
      devEditorApply(editDevice, hit, deviceDefaults(), deviceSettings());
      lcd.setBrightness(editDevice.backlight);
      if (editDevice.sound != soundBefore) {  // previewed live, like brightness
        buzzerSetLevel(editDevice.sound);
        buzzerPlay(Sound::Preview);  // silent when it was just switched off
      }
      dirty = true;
    }
  }
}

// DONE and swipe-down both land here: what is on screen is what is saved.
void closeEditor() {
  if (editSettings != pomoSettings()) {  // spare the flash
    pomoSettingsSave(editSettings);
    bleSettingsChanged();
  }
  pomo.setConfig(pomoConfigFrom(pomoSettings(), POMO_TIME_DIV));
  editing = false;
  uiEditorSlide(false, editSettings);
  uiReplayPomodoro();
  lastRotate = millis();
  dirty = true;
}

void editorGesture(Gesture g) {
  if (g == Gesture::SwipeDown) {
    closeEditor();
  } else if (g == Gesture::Tap) {
    // Hit-test where the finger went down, not where it came up.
    const EditHit hit = pomoEditorHit(gestures.startX(), gestures.startY());
    if (hit.action == EditAction::Done) {
      closeEditor();
    } else if (hit.action != EditAction::None) {
      pomoEditorApply(editSettings, hit, pomoDefaults());
      dirty = true;
    }
  }
}
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
void loop() {
  if (otaUp) otaHandle();
  const uint32_t now = millis();

  pomo.tick(now);
  if (pomo.takeAlert()) {
    const PomoView ended = pomo.view();  // DONE: phase = the one that just ended
    bleNotifyPomodoro(ended.phase, ended.next);
    buzzerPlay(ended.phase == PHASE_FOCUS ? Sound::FocusDone : Sound::BreakDone);
    // Phase over: pull the deck to the Pomodoro card wherever you were. A swipe
    // leaves it again; the DONE state waits for a double tap.
    cardIndex = pomoIndex();
    lastRotate = now;
    unlock.dismiss(now);  // the alert is drawn on the card, so the prompt steps aside
    uiReplayPomodoro();
    uiAlertStart();
    dirty = true;
  }
  buzzerUpdate(now);  // every pass, before the screen-off return below
  if (pomoConfigPending && pomo.setConfig(pomoConfigFrom(pomoSettings(), POMO_TIME_DIV))) {
    pomoConfigPending = false;
    dirty = true;
  }
  pollTouch();
  pollOrientation(now);
  batteryUpdate(now);

  // Which transport feeds the cube (transport_policy.h): BLE while the Mac is
  // delivering, WiFi when it is not.
  const TransportDecision td =
      policy.update(now, bleLastGood(), bleBonded(), settingsHaveWifi(), WIFI_ALWAYS_ON != 0);
  if (td.wifiOn && !wifiUp) {
    netStart();
    wifiUp = true;
  } else if (!td.wifiOn && wifiUp) {
    if (otaUp) {
      otaEnd();
      otaUp = false;
    }
    netStop();
    wifiUp = false;
  }
  if (wifiUp && !otaUp && netOnline()) {
    otaBegin(lcd);
    otaUp = true;
  }

  bool gotData = false;
  // The card follows the bond. Settled before `was`, so a payload arriving in
  // the same pass keeps the viewer where this left them.
  if (volumeShown() != deckVolume) {
    const DeckSpot spot = deckSpot();
    deckVolume = !deckVolume;
    cardIndex = deckKeepIndex(spot, cardIndex, deckSize(), deckVolume);
    if (onVolumeCard()) uiReplayVolume();
    dirty = true;
  }
  const DeckSpot was = deckSpot();
  if (bleTake(payload)) gotData = true;
  handleBleSettings();
  // The Mac's volume. Not a reading: it never keeps the screen awake.
  MacVolume macVol{};
  if (bleTakeVolume(macVol)) {
    volSlider.fromMac(macVol, now);
    unlock.fromMac(macVol.known && macVol.macLocked, now);  // unknown = the link dropped
    dirty = true;
  }
  if (unlock.tick(now)) dirty = true;
  if (volSlider.tick(now)) dirty = true;
  if (mediaPressed >= 0 && now - mediaPressedAt >= VOLUME_PRESS_MS) {
    mediaPressed = -1;
    dirty = true;
  }
  uint8_t volLevel = 0;
  bool volMuted = false;
  if (volSlider.takeSend(now, volLevel, volMuted)) bleSendVolume(volLevel, volMuted);
  if (wifiUp && now - lastPoll >= pollMs()) {
    lastPoll = now;
    netRequest();  // runs on its own task; netTake() hands over the result on a later pass
  }
  const NetFetch fetched = netTake(payload);
  if (fetched == NetFetch::Ok) gotData = true;
  if (fetched == NetFetch::Failed) Serial.printf("[net] fetch failed: %s\n", netLastError());
  if (fetched != NetFetch::None) dirty = true;
  if (gotData) {
    lastGood = now;
    // The Mac resends the same payload every 5 s, so only new readings count
    // as activity for screen sleep (readings_key.h).
    const uint32_t readings = readingsKey(payload);
    if (readings != lastReadings) {
      lastReadings = readings;
      idle.data(now);
    }
    // The deck may have changed size: keep the Pomodoro card under the user.
    cardIndex = deckKeepIndex(was, cardIndex, deckSize(), deckVolume);
    dirty = true;
  }

  if (rotateMs() > 0 && !editing && !touchDown && !volSlider.held() && now - lastRotate >= rotateMs()) {
    step(1);
  }

  // The Pomodoro clock counts whole seconds, so redraw the moment its number
  // changes rather than leaving it to the 1 s housekeeping tick below, which
  // would beat against it and skip or repeat digits.
  const PomoView pv = pomo.view();
  const bool clockShown = cardIndex == pomoIndex() || (!editing && unlock.screen(now) != UnlockScreen::Hidden);
  if (clockShown && pv.displaySec != lastPomoSec) {
    lastPomoSec = pv.displaySec;
    dirty = true;
  }

  const BatteryView bv = batteryView();
  if (bv.pct != lastBatPct) {
    lastBatPct = bv.pct;
    dirty = true;
  }

  // Screen sleep: never while a session is running, the editor or a pairing
  // code is up (see idle_sleep.h).
  const PomoState ps = pv.state;
  const bool keepOn = ps == POMO_FOCUS || ps == POMO_BREAK || ps == POMO_PAUSED || editing ||
                      bleState() == BleState::Pairing || (!pairWaitDismissed && waitingToPair());
  const bool wantOn = idle.update(now, keepOn, sleepMs());
  if (wantOn != screenOn) {
    screenOn = wantOn;
    if (screenOn) {
      setCpu(CPU_MHZ_FAST);
      lcd.wakeup();
      lcd.setBrightness(deviceSettings().backlight);
      uiInvalidate();  // the first frame after sleep goes out whole
      dirty = true;
    } else {
      lcd.setBrightness(0);
      lcd.sleep();
      setCpu(CPU_MHZ_SLOW);
    }
  }
  if (!screenOn) {
    delay(50);  // touch is still polled, so a tap wakes it at once
    return;
  }
  applyRotation();
  setCpu(cpuPolicy.update(now, touchDown || uiAnimating()));

  // Redraw on change, every frame while a ring is still moving, and once a
  // second otherwise so the freshness counter ticks.
  if (dirty || uiAnimating() || now - lastDraw >= 1000) {
    const uint32_t age = lastGood ? now - lastGood : now;
    const bool pairing = bleState() == BleState::Pairing;
    const bool waiting = !pairWaitDismissed && waitingToPair();
    const bool editorUp = editing && !uiEditorSliding();
    const UnlockScreen us = editing ? UnlockScreen::Hidden : unlock.screen(now);
    // Only the deck pulses the backlight for an alert; another screen ends it
    // and restores the level (the display panel's preview while it is open).
    if ((pairing || waiting || editorUp || us != UnlockScreen::Hidden) && uiAlertCancel())
      lcd.setBrightness(editingDevice ? editDevice.backlight : deviceSettings().backlight);
    if (pairing) uiBlePair(lcd, blePasskey());  // the code must be seen
    else if (waiting) uiBlePair(lcd, 0);
    else if (editorUp) {
      if (editingDevice) uiDeviceEditor(lcd, editDevice);
      else uiPomodoroEditor(lcd, editSettings);
    }
    else if (us != UnlockScreen::Hidden) uiUnlock(lcd, us == UnlockScreen::Waiting, pv);
    else {
      VolumeView vv = volSlider.view();
      vv.pressed = mediaPressed;
      uiRender(lcd, payload, cardIndex, td.bleLive || netOnline(), age, pv, bv,
               td.bleLive ? UiLink::Ble : (wifiUp && netOnline() ? UiLink::Wifi : UiLink::None),
               deckVolume ? &vv : nullptr);
    }
    lastDraw = now;
    dirty = false;
  }

  // Touch sampling cadence; keeps the loop off a busy spin. While a ring is
  // moving the pass is paced to FRAME_MS instead, counting the frame just drawn.
  if (uiAnimating()) {
    const uint32_t spent = millis() - now;
    if (spent < FRAME_MS) delay(FRAME_MS - spent);
  } else {
    delay(15);
  }
}

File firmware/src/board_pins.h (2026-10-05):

#pragma once
// Pin map for the Waveshare ESP32-S3-Touch-LCD-1.69.
//
// VERIFY THESE AGAINST YOUR BOARD before the first flash -- Waveshare ships
// several 1.69" variants and the revisions do not all share a pinout. The
// schematic and pin table are on the product wiki. Everything board-specific
// in this project lives in this one file, so a different revision is a
// one-file change.

// --- ST7789V2 display, SPI ---------------------------------------------
#define PIN_LCD_DC    4
#define PIN_LCD_CS    5
#define PIN_LCD_SCLK  6
#define PIN_LCD_MOSI  7
#define PIN_LCD_RST   8
#define PIN_LCD_BL   15   // backlight, driven as PWM

#define LCD_WIDTH   240
#define LCD_HEIGHT  280
// The ST7789 controller addresses a 240x320 frame, so a 240x280 panel starts
// 20 rows in. If the image is shifted vertically, this is the number to change.
#define LCD_OFFSET_Y 20
// Corner radius of the glass, in px. The settings sheets round their screen-edge
// corners to this so they sit flush with the bezel; tune it if they do not.
#define LCD_CORNER_R 40

// --- CST816 capacitive touch, I2C (shared with the IMU and RTC) --------
#define PIN_I2C_SDA  11
#define PIN_I2C_SCL  10
#define PIN_TP_INT   14
#define PIN_TP_RST   13
#define CST816_ADDR  0x15

// --- QMI8658C 6-axis IMU, I2C (same bus as the touch controller) --------
#define QMI8658_ADDR 0x6B
// Sign of the IMU's X-axis reading (measured: gravity lies on X with the cube on its edge) when the top of the screen points at the
// ceiling (+1 g = upright). Flip to -1 if the screen rotates the wrong way when
// the cube is stood on its edge; see docs/imu-acceptance.md.
#define IMU_UP_SIGN  1

// --- Misc on-board peripherals -----------------------------------------
#define PIN_BAT_ADC   1   // battery voltage divider
#define PIN_BUZZER   42   // passive buzzer, PWM (buzzer.cpp); an older board revision used 33

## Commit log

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2026-10-02 feat(ble): payload frame assembler, protocol doc and golden fixture
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2026-10-02 fix(ble): route name to scan response, log advertising start result
    NimBLEAdvertising::setName only targets the scan response if
    enableScanResponse(true) was called first; the order is swapped. Also log
    adv->start() and clear g_sendNow on disconnect.
    [net_ble.cpp]
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2026-10-02 fix(fw): keep WiFi modem sleep on in OTA (BLE coexistence abort)
    [ota.cpp]
2026-10-02 fix(mac): tolerate timer jitter in heartbeat push policy
2026-10-02 fix(fw): let BLE pairing work from the setup portal
    [portal.cpp]
2026-10-02 fix(fw): non-zero BLE passkey, race-free Control notify
    [net_ble.cpp]
2026-10-02 fix(fw): portal restarts only on a new bond; repaint pair code on change
    [portal.cpp]
2026-10-02 feat(stand): round the outer edges, add a Type-C blanking cap
    The shell and base plate were all hard 90 deg edges. Round them with four
    new tunables (set any to 0 for the old look): edge_r 3.0 on the vertical
    corners, prof_r 2.5 on the apex ridge and back top edge, win_cham 0.6
    around the window, plate_cham 0.8 under the plate. The shell body is now
    the intersection of the swept profile and the extruded plan footprint, so
    both edge families round while the bottom rim stays square for printing.
    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
    [fit-check.stl, stand-base.stl, stand-front.stl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]
2026-10-02 fix(fw): enable octal PSRAM so BLE + setup portal fit in RAM; add BLE-off env
    The board's PSRAM is octal but memory_type was the quad setting, so the chip
    was never found and everything ran in ~7 KB of free internal RAM once BLE was
    up. Starting the portal AP then failed an allocation inside the WiFi driver
    (LoadProhibited in ieee80211_hostap_attach) and the cube boot-looped after a
    failed WiFi join. memory_type = qio_opi fixes it.
    Also add a waveshare-s3-lcd169-noble env (-DCUBE_NO_BLE, net_ble_off.cpp stubs)
    as a WiFi-only fallback build.
    Verified on hardware: pairing, silent reconnect after reboot, WiFi fallback and
    return to BLE.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
    [net_ble.cpp]
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2026-10-02 feat(mac): trace logging, Show log menu item, redesigned dropdown
    - Trace (CUBE_TRACE=1 / --trace / menu toggle): BLE, bridge, HTTP and push-policy diagnostics
    - Menu: "Show log" opens ~/Library/Logs/claude-cube-link.log; app logs there when not run by launchd
    - Menu: custom gauge rows with tinted progress bars and status dots instead of greyed-out items
2026-10-02 feat(firmware): redesign slide-up/down settings sheets, settings over BLE
    Pomodoro and Display sheets get a rounded edge and grab handle, icon titles,
    per-sheet accents, label-left rows with round steppers, a brightness meter and
    a slimmer RESET/DONE bar. Card dims while a sheet slides. Settings can also be
    changed from the Mac over a new BLE Settings characteristic.
    [ble_sim.cpp, board_pins.h]
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2026-10-02 fix(firmware): read the IMU X axis as vertical when the cube stands on its edge
    Measured on hardware: with the USB-C edge down, gravity lies on X (+0.96 upright,
    -0.95 flipped) and Y stays near 0, so reading Y never triggered a flip.
    [board_pins.h, main.cpp]
2026-10-02 feat(firmware): double-tap to start/pause, triple-tap to reset the Pomodoro
    Replace the long-press and hold-to-reset gestures with taps. GestureTracker
    groups taps only on the Pomodoro card (multiTap flag): a tap waits
    MULTI_TAP_GAP_MS for the next, a third tap fires at once, and a swipe, drag
    or card change drops pending taps. Everywhere else a tap is immediate.
    Card hints now read "2 TAPS: ...". Docs and host tests updated.
    [main.cpp]
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2026-10-03 feat(firmware): setup portal joins the saved network alongside its AP
    The portal now runs AP+STA. While nobody is on the AP and no Mac is pairing,
    the station side makes a bounded attempt at the saved network (10 s every
    30 s); once joined, the screen shows the LAN address and the form works there
    too. A portal opened because WiFi was down reboots to normal as soon as the
    network answers, replacing the 60 s idle reboot.
    The AP moves to 192.168.71.1 so the station can join a 192.168.4.x LAN.
    Requests must name the cube by address and POSTs must carry a per-boot form
    token, so another web page cannot drive the form. A blank OTA password keeps
    the stored one; a checkbox clears it.
    Co-Authored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
    [net.cpp, portal.cpp]
2026-10-03 fix(firmware): review fixes across BLE, settings, Pomodoro and UI
    - BLE: who may stay connected is ble_auth.h (host-tested). Just Works links,
    a second device, and a link not secured within 60 s are dropped. A rejected
    Settings write is republished so a read never returns it. The deprecated
    NimBLEService::start() call is gone.
    - Settings over BLE: only the groups that changed are written, network last.
    Ok can mean a partial save, and the Mac reads back. The editors save only
    when a value changed, to spare the flash.
    - Pomodoro: setConfig also applies between phases (DONE) and says whether it
    did. A Mac change that arrives mid-phase waits in pomoConfigPending.
    - UI: the top bar sh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
    [main.cpp, net.cpp]
2026-10-03 fix(bridge): review fixes, US-inference pricing, loopback for the Mac helper
    - Config: a bad number falls back to the default with a warning, refresh is
    at least 1 s, env booleans override config.json both ways, and `host` /
    CUBE_HOST picks the listen address. Pinned to a LAN address, the bridge
    also listens on 127.0.0.1, which is where the Mac helper reads it.
    - Server: listens at once and refreshes in the background (the card says
    "starting"). /health is always 200 and reports ok/error in the body. A
    throwing request handler no longer ends the process. No CORS header.
    - Limits: a failed read keeps the last good one for up to 10 minutes, then
    shows an empty track. The usage capt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
2026-10-03 fix(mac-helper): review fixes; Forget cube, settings form, bridge on quit
    - Menu: "Cube settings…" and "Forget cube" (drops the stored cube and scans
    again; a late disconnect from the old link cannot tear down the new one).
    The heartbeat timer runs in .common modes, so an open menu no longer lets
    the cube call the link stale.
    - Quit (and logout/shutdown) stops the bridge child, so the next launch does
    not adopt a stale one. An Edit menu makes Cmd-C/V/X/A/Z work in the form.
    - Settings form: Apply writes only what differs. A re-read keeps fields being
    edited and refreshes the rest. A new WiFi network with no password asks
    first, since the cube then joins it as open. After a save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
2026-10-04 refactor(3d): move the board facts into board.scad
    The wedge renders byte-identical STLs before and after. board_flip no longer needs a firmware change: the IMU auto-rotates.
    [board.scad, stand.scad]
2026-10-04 test(3d): run both stands from test.sh; easel.scad skeleton
    test.sh [stand|easel] renders into build/<scad>-<part>.*. easel.scad has the tunables, the board placement, the cell and board ghosts and the reference points for the tip-force estimate.
    [easel.scad]
2026-10-04 feat(3d): easel tray and frame
    The tray holds the cell flat with three screw pilasters and four foot recesses; the frame lid carries the lead slots, the screw holes and the fin that braces the carrier.
    [easel.scad]
2026-10-04 feat(3d): easel carrier
    Back plate, four posts with shoulders and pegs on the PCB holes, two legs with the vertical leg screws and the hinge ridges, top-screw holes and the Type-C relief.
    [easel.scad]
2026-10-04 feat(3d): easel bezel and hinge
    Bezel with glass pocket, chamfered window, open chin, grooves that pick up the carrier's ridges about the hinge line P, blind top-screw pilots and the wedge's openings. The lower pocket corners are squared: round ones sweep into the glass and PCB corners while the bezel swings on. Tests: window, pilot walls, ridge/groove, bezel vs carrier/frame/heads, swing 5-30 deg with a sagged board, all-pairs fit across variants, each with a positive control.
    Claude-Session: https://claude.ai/code/session_01TcL18LyAn39Us5VsC2UP8w
    [easel.scad]
2026-10-04 feat(3d): easel Type-C cap
    Optional friction plug for the bezel's blind plug relief: flange with a pull ear on the side face, crush ribs only on the stretch that sits in the bezel so the bezel still swings off. Tests: body cle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
    [easel.scad]
2026-10-04 feat(3d): stability estimate for the easel
    tools/stability.py takes mass and centre of gravity from the assembled-position meshes (printed parts by volume, cell and board as fixed masses) and the reference points easel.scad echoes, and works out the push into the screen that tips the stand backwards. Nominal: 109.5 g, 3.21 N at the centre of the active area, 1.45 N at its top edge (need 3.0 / 1.3). stlcheck gets a __main__ guard so it can be imported.
    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
2026-10-04 feat(3d): export the easel parts; README
    Five easel STLs (tray, frame, carrier, bezel, usb-cap). README: both stands and board.scad in the intro, an Easel section (print list, hardware, assembly order, hinge, stability, VERIFY items, print the carrier first), and fixes for the stale docs/enclosure test paths and the setRotation note (the IMU auto-rotates now).
    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
    [easel-bezel.stl, easel-carrier.stl, easel-frame.stl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]
2026-10-04 feat(3d): route the battery lead through the easel carrier
    The MX1.25 BAT header sits on the PCB rear beside the Type-C and opens towards the board centre, so the lead leaves flat across the PCB rear with no way out to the lid slot. The carrier plate grows 2.4 -> 3.2 mm and gets a 1.6 mm groove in its front face: across, down past the lower post, out under the PCB edge to the chin; it mirrors in x with board_flip. check_cord runs a plug ghost and a 1.6 mm lead from the header to the tray against every part, the board and a rear-parts envelope, with three controls. Re-exported carrier and frame; stability 3.27 / 1.48 N.
    Claude-Session: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
    [easel-carrier.stl, easel-frame.stl, easel.scad]
2026-10-04 feat(firmware): on/off switches and bigger buttons in the settings panels
    Both settings sheets (Pomodoro and Display) get a new row layout: the
    label over its value on the left, two 34 px round -/+ buttons side by
    side on the right (46x44 touch zones each). A stepper that would change
    nothing, at a limit or on a row that is off, is drawn disabled. RESET is
    now a pill like DONE, and the round shapes are anti-aliased.
    SLEEP and ADVANCE, where 0 means never/off, carry a switch. A tap on the
    row's left part (editorLead) toggles it; devEditorHit adds that Toggle
    zone to the shared pomoEditorHit. Their steppers move between non-zero
    presets only and do nothing while off. Turning one back on resto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
    [main.cpp]
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2026-10-05 feat(firmware): buzzer plays a tune when a Pomodoro phase ends
    [bench.cpp, board_pins.h, buzzer.cpp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]
2026-10-05 fix(firmware): republish BLE Settings after an on-device edit
    Saving from the display panel or the Pomodoro editor left the Settings
    characteristic holding the values from before, so the Mac's next read
    (opening Cube settings) showed them: mute on the cube, the Mac still
    says Medium. Both editors now call bleSettingsChanged() after a save.
    The bench checks after every loop pass that a Settings read returns
    what is stored; the editor scenario now also steps the Pomodoro editor.
    [bench.cpp, ble_sim.cpp, main.cpp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]
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2026-10-09 fix(firmware): volume fill edge sits on the finger (inverse of volumeLevelAt)
2026-10-09 fix(firmware): idle Volume speaker visible on the track (VOL_IDLE)
2026-10-09 fix(firmware): grab the volume slider only from inside the pill; stricter bench check
    [bench.cpp, main.cpp]
2026-10-09 fix: volume writes latest-wins, touch routing latched at landing, stale GATT diagnostic
    Mac Volume writes keep one in flight with the newest pending (LatestWinsGate);
    the bench Mac models the FIFO and checks the final level. Auto-advance never
    moves under a finger and the slider only gets touches that landed on it. A
    fw_rev 5 cube without the Volume characteristic logs the cached-table hint.
    [bench.cpp, main.cpp]
2026-10-09 feat: minimal Volume card with media controls; Service Changed after a GATT change
    BLE: the cube flags Service Changed for bonded Macs when it boots a new fw_rev
    (NVS ble/gr), and the Mac rediscovers on didModifyServices, so a firmware that
    adds a characteristic no longer needs a re-pair. fw_rev 6.
    Volume card: name, number and status word on the left, a slim bar on the right,
    a full-width row of previous / play-pause / next. The level moves only by a
    drag, relative to where the finger landed; a tap on the number mutes; a touch
    that lands in the button row is always a tap. The buttons send Control
    06 <key>; the Mac sends it as a MediaRemote command from a one-shot osascript
    (Apple-signed, s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
    [bench.cpp, ble_sim.cpp, main.cpp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]
2026-10-09 fix(3d): board facts from Waveshare's STEP model; flip the board in the wedge
    The board is 3.7 mm thicker than estimated: glass + LCD 3.8, a 1.5 mm foam
    pad, then a 1.0 mm PCB, and rear parts up to 10.7 mm. With the old values
    the Type-C slot and the pinholes sat ~3 mm too shallow, the wedge pushers
    and the easel posts ran through the PCB, and the easel carrier hit the rear
    parts. The "mounting holes" are Ø2.36 notches open to the long edges, and
    the BAT header sits beside the Type-C towards the bottom end.
    - board.scad: depths, offsets, glass corner radius, button positions and
    the notches from the STEP; the test ghost now has the LCD and foam pad.
    - board_flip moves into each stand: th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
    [board.scad, easel-bezel.stl, easel-carrier.stl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]
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2026-10-23 feat(nav-server): HTTPS site live, hash bucket file, HCMC route fixture
    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
2026-10-23 fix(nav-server): smoke motorway check is case-insensitive
    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
2026-10-23 fix(nav-server): per-key tile limit, directory mounts, download timeout, expressway pre-filter
    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
2026-10-23 feat(firmware): Mac and iPhone bonded and connected at once
    ble_auth.h becomes ble_bonds.h: two bonds, a 120 s pairing window opened by
    the portal's "Pair new device" (NVS ble/pw), bond kinds learned from the first
    write (Nav = iPhone) and stored per identity address, and bleBondToEvict to
    replace an older bond of the same kind. net_ble.cpp keeps advertising while
    fewer than two links are up, tracks each link, adds the Nav characteristic
    (decoded on the NimBLE task into static scenes, handed over by bleTakeNav),
    and asks the iPhone's link for BLE_NAV_PARAMS. The portal gets Pair new
    device / Forget Mac / Forget iPhone. Stand-ins: CUBE_NAV, CUBE_NAV_STOP_MS,
    CUBE_PAIRING in ble_sim.cpp; a scr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
2026-10-23 fix(firmware): never let a full bond store or a silent new bond push out the Mac
    A new bond whose link drops before its first write is deleted
    (bleDropBondOnDisconnect), and NimBLE's store-full handler is replaced: only
    a bond of unknown kind may make room (bleStoreOverflowVictim), otherwise the
    write is refused, so a third device can no longer round-robin away the Mac
    or iPhone. bleForget(Unknown) now deletes only unidentified bonds, and the
    portal offers "Forget unknown devices" while one exists.
    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
2026-10-23 fix(firmware): phone bond skips the boot join and the portal; WiFi stays off during a ride
    bootWifiPlan (pure, tested) decides the boot join; the transport policy takes rideActive.
    NO PHONE redraws the moment it flips; [nav] compose N ms is logged every 10 s.
    Bench: new ride scenario (Mac away, WiFi configured) and frame-rate/screen asserts for rides.
    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
2026-10-23 fix(firmware): reject nav frames with a coordinate outside the clip box
    The busy sample stays inside it; a longeta sample shows the longest eta.
    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
2026-10-23 fix(firmware): low-battery percent in the nav banner; a long eta never overflows the bottom line
    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
2026-10-23 fix(ios-nav): centre frames on the raw fix, cull far streets, stable street order
    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
2026-10-23 fix(ios-nav): link never resends an older parked frame, backs off from refusing cubes
    A frame started on an idle queue now drops any frame parked behind the one
    just finished. NavLinkPolicy (NavCore, tested) decides after a drop:
    reconnect a working link at once, back off when setup never finished,
    skip a scanned cube that never became ready, and stop on a removed bond
    (status forgetCube). A stale last scene is not resent on reconnect;
    discovery cannot orphan a connect in flight; Service Changed keeps the
    seq. New statuses: unauthorized, openPairingWindow (30 s without pairing).
    Claude-Session: https://claude.ai/code/session_01X6B1Z6rN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
2026-10-23 fix(ios-nav): ride tick re-runs the engine, keychain ids, dispatch timer, location errors
    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
2026-10-23 fix(ios-nav): a street too big for the frame no longer drops the smaller ones after it
    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
2026-10-24 test(3d): check the printed parts against Waveshare's STEP model
    test.sh now runs every printed part, in place, against the board's STEP model
    (291 solids) instead of only the box ghost: no overlap with any solid, at
    least 0.2 mm from every rear part, and the wedge pushers / easel shoulders
    overlap the PCB (the preload) and nothing else. The easel bezel is checked
    swung 5-30 deg with the board sagged 0.2 mm. Controls: an undersized pocket,
    2.6 mm pegs, a 10.2 mm board_t and the unflipped wedge must all fail.
    - tools/stepcheck.py: `mesh` turns the STEP into closed per-solid meshes in
    board.scad's frame (cached in build/board-step.npz); `check` intersects one
    part with them using the boar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
2026-10-24 fix(3d): pod review fixes: lead notch, blind anchor, sponge gasket, squeezed pad, detent finger
    The cell's plug could not pass the carrier's lead slot; the tether anchor opened
    into the cavity; a solid TPU gasket needed far more force than four M2 screws
    and the carrier could take. Each fix has a check that failed first.
    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
2026-10-24 fix(bridge): final-review fixes for agent tracking
    Answers survive a client hang-up and fail closed when a send may have
    typed; menu answers move from the live cursor; keys are 1-9. The budget
    drops extra cards before any prompt data and marks cut text (...),
    dropped detail (cut) and a dropped prompt (qc). Multi-select questions
    are answered at the terminal. Hooks end "starting" and own the status
    over menu prompts. Tracker locks are released by defer; the hook client
    waits 300 ms. Prompt ids are unique across restarts; tmux runs with a
    UTF-8 locale; discovery retries the claude lookup, logs its fallback
    once and slows down when idle; an over-long transcript line is skipped.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
2026-10-25 fix(firmware): the reason line sits above the answer buttons
    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
2026-10-25 fix(firmware): lower-case labels on the display panel too
    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
2026-10-25 fix(firmware): keep the display panel's RESET/DONE bar clear of the rounded corners
    The bar ran to y 276, 10 px from the edges, where the glass's 40 px corner
    is 16 px in, so its outer corners were cut off and it covered the sheet
    handle. It now ends at y 264 (pills), 16 px in; a host test checks the
    pills against the corner radius.
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2026-10-25 revert: back to the fixed 2x2 Agents grid (keep the black background)
    Two agents at full height read poorly; the grid is 108x96 tiles again,
    with empty slots filling a screenful, as before a1b6ef4.
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2026-10-25 feat(firmware): pick a folder's hat on the cube
    A tap on the critter on the detail screen now draws uiHatPicker in the
    detail's place: `hat` beside `< back`, 13 shapes on small idle critters in
    the current colour, `none`, `auto` and 8 colour swatches, with the current
    shape (or none / auto) and colour outlined. hat_picker_layout.h places it
    for drawing and hatPickerAt. A pick sends Control 0B (bleSendHat) and
    DetailView shows it for its hold; SwipePrev or back return to the detail.
    Also: the screen's sleep closes the detail and its picker (0A 00);
    DETAIL_CRITTER moves to y 60 so it no longer overlaps `< back`; pollTouch
    takes the pass's `now`, so a touch-started 0A or pick is never stamped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
2026-10-25 fix: final-review fixes for the agent detail and hat picker
    - A navigation ride starting closes the detail and its picker (0A 00), so
    the Mac stops polling ?detail= while the phone streams map frames; bench
    scenario `detail-ride` checks one 0A 00 and nothing left open.
    - A 0A 00 that could not go out is tried again every 1 s for up to 5 s,
    until one goes out or a detail opens (DetailView::closeSent/closeDue,
    host-tested; the bench `detail` stand-in fails the first close once).
    - The pick -> code -> wire mapping moves out of main.cpp into
    hat_picker_layout.h (hatPickCode, hatPickWire), host-tested.
    - Docs: PollPolicy polls every 1 s with ?detail= while a detail is open;
    /api/hat i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
2026-10-26 fix(bridge): find claude where the installers put it
    Under launchd the bridge looked claude up with zsh -lc, which reads
    ~/.zprofile but not ~/.zshrc, and the native installer often adds
    ~/.local/bin to PATH only in the latter. With no claude, discovery fell
    back to the process scan, which cannot tell two sessions in one folder
    apart: each process takes the newest unclaimed transcript there, so a
    session showed another's title and one dropped off the board.
    When the login shell names no claude, Discovery now tries the installers'
    locations (~/.local/bin, ~/.claude/local, /opt/homebrew/bin,
    /usr/local/bin). Only NewDiscovery sets them, so tests never find a real
    binary.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
2026-10-26 fix(mac): a running tile's dots stop only behind its text
    The ground skipped a full-width band from the name to near the bottom,
    so the dots looked cut off; now only a box as wide as each line clears,
    as on the cube.
    Claude-Session: https://claude.ai/code/session_01Kmx7rziqjNyKryWNqxzJBT
2026-10-26 feat: agent tiles follow the tmux panes, left to right
    The bridge reads every pane's session, window and position from
    list-panes and orders the tiles as the panes sit on screen, so swapping
    two panes swaps their tiles within a sync (3 s); agents outside tmux come
    after, by status. Status still decides which agents get a place, which
    prompt is q and which tile the byte budget drops, so a waiting agent is
    never left out. The board uses the same order, and the Mac menu keeps it
    while keeping a place for a waiting tile.
    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
2026-10-26 fix(bridge): a turn's end survives a slow or restarting bridge
    Stop and SessionEnd, which nobody waits on and whose loss leaves a tile
    running until the next turn, get 3 s instead of 300 ms and are posted
    again every 250 ms while the bridge does not answer. The tracker logs
    each lifecycle hook (start, prompt, stop, end) with the status it
    leaves, never the prompt, so a stuck tile can be traced.
    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
2026-10-26 feat(firmware): the usage card as two tiles with edge gauges
    Each rate-limit window gets its own tile in the Agents card's columns:
    the percentage large in its tone, the key above, the reset and caption
    below, and the reading as a 4 px gauge round the tile's edge cut at the
    60/85 thresholds. A failed read shows the bridge's reason (s1, s2) in
    the tiles. The inner ring's table is gone. preview.html mirrors it.
2026-10-27 feat(firmware): critters at 30 frames/s on USB and 24 on battery
    The pacer now keeps to its schedule instead of stamping each frame at the
    pass that drew it, so the 15 ms pass delay no longer rounds the rate down;
    a pass more than a period late still does not owe the frames it missed.
